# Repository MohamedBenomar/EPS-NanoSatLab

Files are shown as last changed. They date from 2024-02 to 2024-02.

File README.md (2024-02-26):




# Electrical Power System (EPS) for the NanoSatLab of the Universitat Politècnica de Catalunya (UPC)

Study and validate a design of a Electrical Power System for Nanosatellites using Supercapacitors technology as a source for systems that require high currents for a short time, together with Lithium-Ion batteries.

## Table of Contents

- [CADS](#cads)
- [Docs](#docs)
- [Firmware](#firmware)
- [Hardware](#hardware)
- [Validation](#validation)

## CADS

This folder section the 3D model of the designed PCB and the 3D model of an encapsulate for the system.

## Docs

This section includes the datasheets of the components used in the design, a real picture of the system indicating the differents blocks and the paper about the project.

## Firmware

This section includes the firmware for the ESP using an STM32 microcontroller.

## Hardware

This section includes the hardware files of the system using the open-source software KiCad.

## Validation

This section contains the validation report of the system.

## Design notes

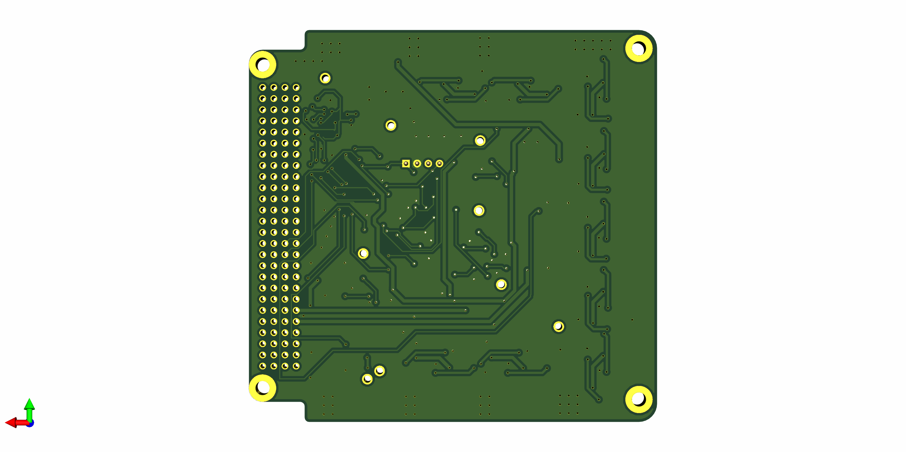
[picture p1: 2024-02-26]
Hardware/Docs/EPS_v3_NanoSatLab_PCB_Back.png

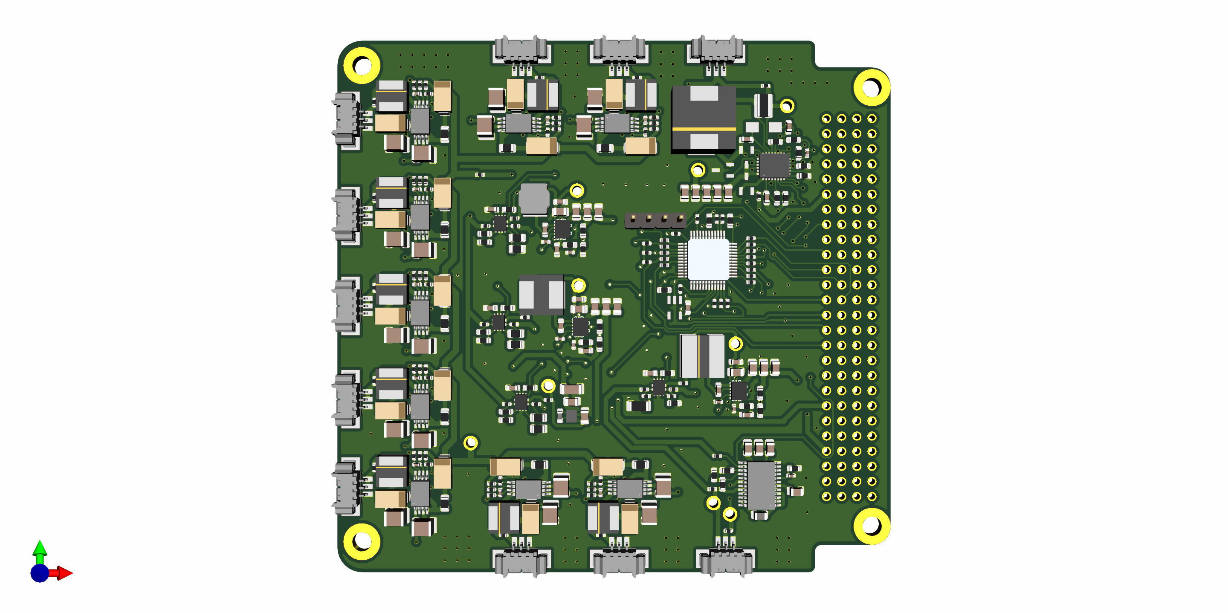
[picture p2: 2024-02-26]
Hardware/Docs/EPS_v3_NanoSatLab_PCB_Front.png

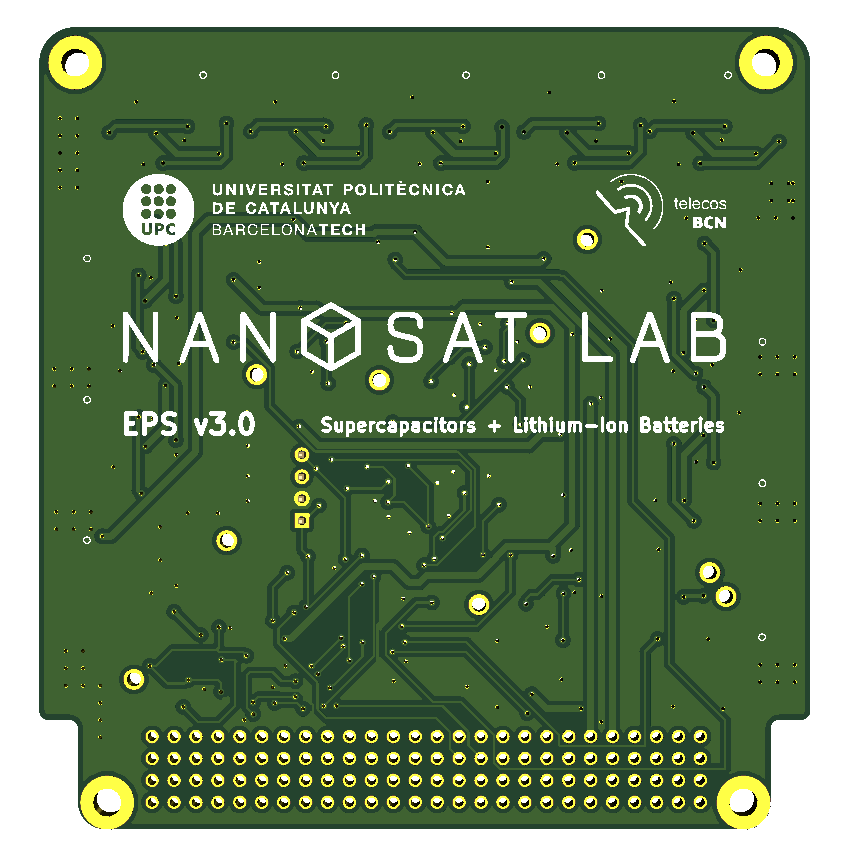
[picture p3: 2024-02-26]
CAD/EPS_v3_NanoSatLab_Bottom_3D.PNG

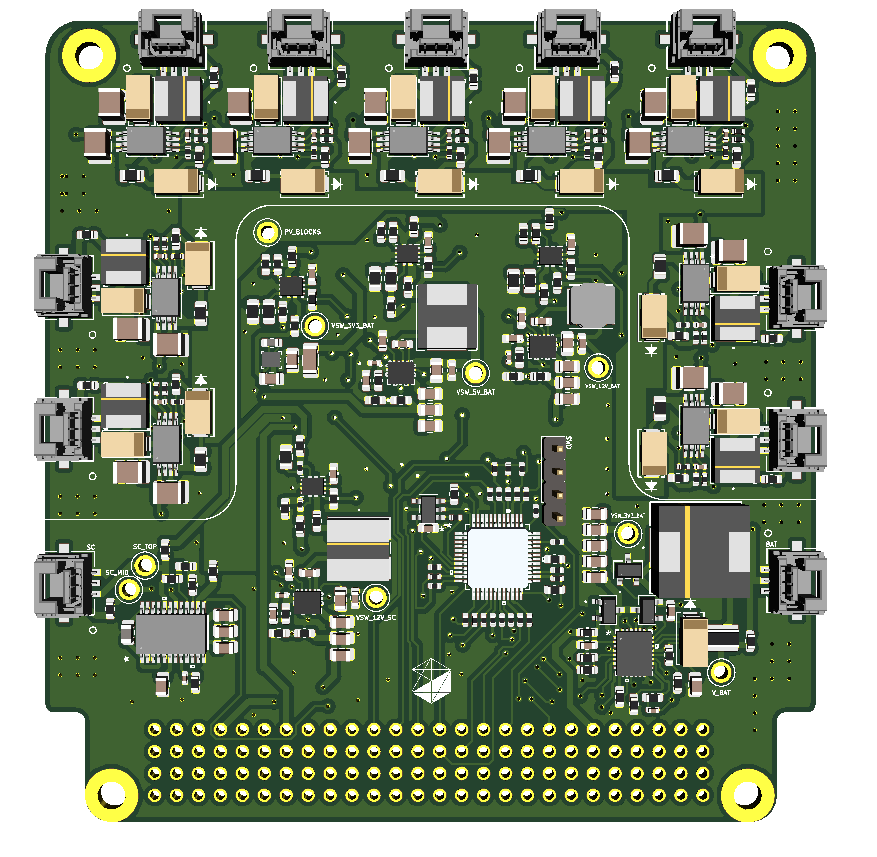
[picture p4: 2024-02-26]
CAD/EPS_v3_NanoSatLab_Top_3D.PNG

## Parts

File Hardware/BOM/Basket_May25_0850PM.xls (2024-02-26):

SHOPPING BASKET
This is not an invoice
25-May-21 20:50:02
 | Mouser No | Mfr. No | Manufacturer | Customer No | Description | RoHS | Lifecycle | Order Qty. | Price (EUR) | Ext.: (EUR)
1 | 538-502382-0370 | 502382-0370 | Molex |  | Headers & Wire Housings 3P CLIKMATE RECPT VERTICAL TIN | RoHS Compliant |  | 11 | 0,424 € | 4,66 €
2 | 511-STM32L412C8T6 | STM32L412C8T6 | STMicroelectronics |  | ARM Microcontrollers - MCU 16/32-BITS MICROS | RoHS Compliant |  | 1 | 3,68 € | 3,68 €
3 | 579-MCP1320T-29LE/OT | MCP1320T-29LE/OT | Microchip |  | Supervisory Circuits Active low P-P | RoHS Compliant |  | 1 | 0,559 € | 0,56 €
4 | 81-DFE18SAN1R0MG0L | DFE18SAN1R0MG0L | Murata |  | Fixed Inductors 0603 1.0uH 20% 1.7A RDC=0.128ohms | RoHS Compliant |  | 1 | 0,356 € | 0,36 €
5 | 595-TPS61288RQQR | TPS61288RQQR | Texas Instruments |  | Switching Voltage Regulators 18V, 15A synch boost converter 11-VQFN-HR -40 to 125 | RoHS Compliant | New Product | 3 | 3,35 € | 10,05 €
6 | 652-CR0603FX9313ELF | CR0603-FX-9313ELF | Bourns |  | Thick Film Resistors - SMD CHIP RESISTOR | RoHS Compliant |  | 2 | 0,085 € | 0,17 €
7 | 667-ERJ-PB3B4872V | ERJ-PB3B4872V | Panasonic |  | Thick Film Resistors - SMD 0603 Anti-Surge Res. 0.1%, 48.7Koh |  |  | 3 | 0,237 € | 0,71 €
8 | 81-LQH5BPN2R7NT0L0L | LQH5BPN2R7NT0L | Murata |  | Fixed Inductors 2.7uH +/-30% | RoHS Compliant |  | 1 | 0,415 € | 0,42 €
9 | 81-GCM155R72A392KA7J | GCM155R72A392KA37J | Murata |  | Multilayer Ceramic Capacitors MLCC - SMD/SMT 0402 3900pF 100volts X7R 10% | RoHS Compliant |  | 1 | 0,085 € | 0,09 €
10 | 667-ERJ-PB3B3402V | ERJ-PB3B3402V | Panasonic |  | Thick Film Resistors - SMD 0603 Anti-Surge Res. 0.1%, 34Kohm |  |  | 1 | 0,212 € | 0,21 €
11 | 542-PM628S-6R0-RC | PM628S-6R0-RC | Bourns |  | Fixed Inductors 6.0uH 30% | RoHS Compliant |  | 1 | 0,94 € | 0,94 €
12 | 81-GCM1555C1H620JA6D | GCM1555C1H620JA16D | Murata |  | Multilayer Ceramic Capacitors MLCC - SMD/SMT 0402 62pF 50volts C0G 5% | RoHS Compliant |  | 2 | 0,085 € | 0,17 €
13 | 667-ERJ-PB3D2052V | ERJ-PB3D2052V | Panasonic |  | Thick Film Resistors - SMD 0603 Anti-Surge Res. 0.5%, 20.5Koh |  |  | 1 | 0,152 € | 0,15 €
14 | 595-TPS2121RUXR | TPS2121RUXR | Texas Instruments |  | Power Switch ICs - Power Distribution 2.7-V&nbsp;to 22-V, 56-m , 4.5-A, power mux with seamless switchover 12-VQFN-HR -40 to 125 | RoHS Compliant |  | 4 | 1,86 € | 7,44 €
15 | 667-ERJ-PA3F3573V | ERJ-PA3F3573V | Panasonic |  | Thick Film Resistors - SMD 0603 357Kohm 1% Anti-Surge AEC-Q200 |  |  | 1 | 0,136 € | 0,14 €
16 | 704-FP3-3R3-R | FP3-3R3-R | Eaton |  | Fixed Inductors 3.3uH 5.5A Flat-Pac FP3 | RoHS Compliant |  | 1 | 3,71 € | 3,71 €
17 | 667-ERJ-PB3B1962V | ERJ-PB3B1962V | Panasonic |  | Thick Film Resistors - SMD 0603 Anti-Surge Res. 0.1%, 19.6Koh |  |  | 1 | 0,237 € | 0,24 €
18 | 534-5013 | 5013 | Keystone Electronics |  | Circuit Board Hardware - PCB ORANGE TEST POINT | RoHS Compliant |  | 9 | 0,352 € | 3,17 €
19 | 81-LQM21PN3R3MGRD | LQM21PN3R3MGRD | Murata |  | Fixed Inductors 0805 3.3uH 20% | RoHS Compliant |  | 1 | 0,305 € | 0,31 €
20 | 584-LTC3128IUFD#PBF | LTC3128IUFD#PBF | Analog Devices Inc. |  | Switching Voltage Regulators 3A Monolithic Buck-Boost Supercapacitor Charger and Balancer with Accurate Input Current Limit | RoHS Compliant |  | 1 | 8,80 € | 8,80 €
21 | 660-RN731JTTD1423B50 | RN731JTTD1423B50 | KOA Speer |  | Thin Film Resistors - SMD 142kOhm,0603,0.1%,50 ppm,63mW,50V | RoHS Compliant |  | 1 | 0,352 € | 0,35 €
22 | 667-ERJ-UP3F3571V | ERJ-UP3F3571V | Panasonic |  | Thick Film Resistors - SMD AEC-Q200 | RoHS Compliant By Exemption | New Product | 1 | 0,22 € | 0,22 €
23 | 594-MCT06030C2214FP5 | MCT06030C2214FP500 | Vishay |  | Thin Film Resistors - SMD .1W 2.21Mohms 1% 0603 50ppm Auto | RoHS Compliant |  | 1 | 0,195 € | 0,20 €
24 | 667-ERJ-UP3F3013V | ERJ-UP3F3013V | Panasonic |  | Thick Film Resistors - SMD AEC-Q200 | RoHS Compliant By Exemption | New Product | 1 | 0,22 € | 0,22 €
25 | 667-ERJ-6CWDR022V | ERJ-6CWDR022V | Panasonic |  | Current Sense Resistors - SMD 0805 0.5% 0.022ohm AEC-Q200 | RoHS Compliant By Exemption | New Product | 1 | 0,576 € | 0,58 €
26 | 494-LSM115JE3/TR13 | LSM115JE3/TR13 | Microchip |  | Schottky Diodes & Rectifiers Schottky | RoHS Compliant |  | 1 | 0,364 € | 0,36 €
27 | 963-NR10050T2R1N | NR10050T2R1N | Taiyo Yuden |  | Fixed Inductors 1005 2.1uH 10.4mOhms +/-30%Tol 8.3A HiCur | RoHS Compliant |  | 1 | 0,754 € | 0,75 €
28 | 667-ERJ-PA3F8662V | ERJ-PA3F8662V | Panasonic |  | Thick Film Resistors - SMD 0603 86.6Kohm 1% Anti-Surge AEC-Q200 |  |  | 1 | 0,11 € | 0,11 €
29 | 660-RN731JTD3361D100 | RN731JTTD3361D100 | KOA Speer |  | Thin Film Resistors - SMD 3.36kOhm,0603,0.5%,1 0ppm,63mW,50V | RoHS Compliant |  | 1 | 0,201 € | 0,20 €
30 | 621-DMN1019UVT-7 | DMN1019UVT-7 | Diodes Incorporated |  | MOSFET 12V Enh Mode FET | RoHS Compliant |  | 3 | 0,39 € | 1,17 €
31 | 511-SPV1040T | SPV1040T | STMicroelectronics |  | Battery Management Hi efficiency solar battery charger | RoHS Compliant |  | 9 | 2,84 € | 25,56 €
32 | 963-JMK325ABJ107MM-P | JMK325ABJ107MM-P | Taiyo Yuden |  | Multilayer Ceramic Capacitors MLCC - SMD/SMT 1210 6.3VDC 100uF 20% X5R | RoHS Compliant |  | 9 | 0,508 € | 4,57 €
33 | 963-NRS5020T470MMGJV | NRS5020T470MMGJV | Taiyo Yuden |  | Fixed Inductors 47uH 20% AEC-Q200 Hi Quality | RoHS Compliant | New Product | 9 | 0,601 € | 5,41 €
34 | 78-VS-30BQ015-M39AT | VS-30BQ015-M3/9AT | Vishay |  | Schottky Diodes & Rectifiers 3A 15V Single Die Schottky Rectifier | RoHS Compliant |  | 18 | 0,751 € | 13,52 €
35 | 71-RCWH080533L2FNEA | RCWH080533L2FNEA | Vishay |  | Thick Film Resistors - SMD 0.33W .0332ohms 1% 200ppm | RoHS Compliant |  | 9 | 0,567 € | 5,10 €
36 | 187-CL32A157MQVNNNE | CL32A157MQVNNNE | Samsung Electro-Mechanics |  | Multilayer Ceramic Capacitors MLCC - SMD/SMT 150uF +/-20% 6.3V X5R 3225 | RoHS Compliant | New At Mouser | 9 | 0,974 € | 8,77 €
37 | 584-LTC4013IUFD#PBF | LTC4013IUFD#PBF | Analog Devices Inc. |  | Battery Management 60V Synchronous Buck Multi-Chemistry Battery Charger | RoHS Compliant |  | 1 | 9,23 € | 9,23 €
38 | 595-TPS630242YFFT | TPS630242YFFT | Texas Instruments |  | Switching Voltage Regulators High Efficiency 1.5A Sing InductBuckBoost | RoHS Compliant |  | 1 | 2,33 € | 2,33 €
By submitting your order you agree to these terms and conditions. (https://www.mouser.es/saleterms) |  |  |  |  |  |  |  |  | Merchandise: | 124,63 €
Prices are reflected at the date and time shown. |  |  |  |  |  |  |  |  | Delivery Charge: | 0,00 €
 |  |  |  |  |  |  |  |  | Back-order Delivery: | 0,00 €

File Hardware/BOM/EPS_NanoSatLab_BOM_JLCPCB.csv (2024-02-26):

Comment | Designator | Footprint | LCSC Part #
100 nF Unpolarized capacitor | C201,C317,C313,C309,C306,C307,C302,C314,C301,C308,C305 | C_0603_1608Metric | CC0603KRX7R9BB104
47 nF Unpolarized capacitor | C316,C315 | C_0603_1608Metric | CL10B473KB8NNNC
2.2 uF Unpolarized capacitor | C318,C311,C310 | C_0603_1608Metric | CL10A225KO8NNNC
82 pF Unpolarized capacitor | C329 | C_0603_1608Metric | 0603CG820J500NT
22 uF Unpolarized capacitor | C330,C331,C332,C321,C323,C326 | C_0805_2012Metric | CL21A226MAQNNNE
10 uF Unpolarized capacitor | C333,C325,C312,C322,C304,C327,C324,C303,C403,C405,C404,C401,C509,C502,C503,C505,C506,C508 | C_0805_2012Metric | CL21A106KAYNNNE
47 uF Unpolarized capacitor | C334 | C_1206_3216Metric | CL31A476MPHNNNE
470 pF Unpolarized capacitor | C402 | C_0402_1005Metric | 0402B471K500NT
0.1 uF Unpolarized capacitor | C501 | C_0603_1608Metric | CC0603KRX7R9BB104
0.01 uF Unpolarized capacitor | C504 | C_0402_1005Metric | CL05B103KB5NNNC
0.22 uF Unpolarized capacitor | C507 | C_0603_1608Metric | CL10B224KA8NNNC
1 uF Unpolarized capacitor | C604,C605,C606,C613,C614,C615,C622,C623,C624 | C_0402_1005Metric | CL05A105KA5NQNC
100 kΩ Resistor, US symbol | R201,R202,R203,R204 | R_0402_1005Metric | 0402WGF1003TCE
33 Ω Resistor, US symbol | R222,R223 | R_0402_1005Metric | 0402WGF330JTCE
0 Ω Resistor, US symbol | R226,R215,R217,R218,R216,R210,R221,R214,R209,R207,R208,R212,R213,R224,R225,R219,R206,R220 | R_0402_1005Metric | 0402WGF0000TCE
10 kΩ Resistor, US symbol | R227,R205,R211,R319,R320,R311,R312,R328,R329 | R_0603_1608Metric | 0603WAF1002T5E
12 kΩ Resistor, US symbol | R305,R307 | R_0402_1005Metric | 0402WGF1202TCE
40.2 kΩ Resistor, US symbol | R306 | R_0603_1608Metric | 0603WFA4022T5E
7.5 kΩ Resistor, US symbol | R308 | R_0805_2012Metric | 0805W8F7501T5E
5.1 kΩ Resistor, US symbol | R317,R309,R326 | R_0805_2012Metric | 0805W8F5101T5E
15 kΩ Resistor, US symbol | R318,R310,R327 | R_0805_2012Metric | 0805W8F1502T5E
18 kΩ Resistor, US symbol | R325,R314,R331,R313 | R_0603_1608Metric | 0603WAF1802T5E
0 Ω Resistor, US symbol | R330,R322,R338,R321,R303,R315,R301,R323,R324,R304,R316,R302,R401,R407,R404,R501,R510,R601,R602,R603,R619,R620,R621,R638,R639,R637 | R_0603_1608Metric | 0603WAF0000T5E
1.5 MΩ Resistor, US symbol | R502 | R_0603_1608Metric | 0603WAF1504T5E
1 MΩ Resistor, US symbol | R503,R507,R508 | R_0603_1608Metric | 0603WAF1004T5E
75 kΩ Resistor, US symbol | R505 | R_0603_1608Metric | 0603WAF7502T5E
1 kΩ Resistor, US symbol | R604,R605,R606,R607,R608,R609,R622,R623,R624,R625,R626,R627,R640,R641,R642,R643,R644,R645 | R_0402_1005Metric | 0402WGF1001TCE
2 MΩ Resistor, US symbol | R613,R615,R617,R631,R633,R635,R649,R651,R653 | R_0603_1608Metric | 0603WAF2004T5E
680 kΩ Resistor, US symbol | R614,R616,R618,R632,R634,R636,R650,R652,R654 | R_0402_1005Metric | 0402WGF6803TCE

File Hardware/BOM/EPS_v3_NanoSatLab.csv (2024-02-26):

Reference | Value | Footprint | Datasheet | Description | JLCPCB | LCSC BOM | LCSC Part | Order Code | Package | Ref | Resistance
J112 | 502382-0370 | EPS_v3_Library:MOLEX_502382-0370 | ~ | SC_CONN | - - - | 0 | - - - | 502494-0370 | MOLEX | - - -
J111 | 502382-0370 | EPS_v3_Library:MOLEX_502382-0370 | ~ | BAT_CONN | - - - | 0 | - - - | 502382-0370 | MOLEX | - - -
J110 | PC104 | EPS_v3_Library:PC104 |  | PinHeaders | - - - | 0 | - - - | – – – | – – – | - - -
J101 | 502382-0370 | EPS_v3_Library:MOLEX_502382-0370 | ~ | X_1 | - - - | 0 | - - - | 502382-0370 | MOLEX | - - -
J102 | 502382-0370 | EPS_v3_Library:MOLEX_502382-0370 | ~ | Y_1 | - - - | 0 | - - - | 502382-0370 | MOLEX | - - -
J103 | 502382-0370 | EPS_v3_Library:MOLEX_502382-0370 | ~ | Z_1 | - - - | 0 | - - - | 502382-0370 | MOLEX | - - -
J104 | 502382-0370 | EPS_v3_Library:MOLEX_502382-0370 | ~ | X_2 | - - - | 0 | - - - | 502382-0370 | MOLEX | - - -
J105 | 502382-0370 | EPS_v3_Library:MOLEX_502382-0370 | ~ | Y_2 | - - - | 0 | - - - | 502382-0370 | MOLEX | - - -
J106 | 502382-0370 | EPS_v3_Library:MOLEX_502382-0370 | ~ | Z_2 | - - - | 0 | - - - | 502382-0370 | MOLEX | - - -
J107 | 502382-0370 | EPS_v3_Library:MOLEX_502382-0370 | ~ | X_3 | - - - | 0 | - - - | 502382-0370 | MOLEX | - - -
J108 | 502382-0370 | EPS_v3_Library:MOLEX_502382-0370 | ~ | Y_3 | - - - | 0 | - - - | 502382-0370 | MOLEX | - - -
J109 | 502382-0370 | EPS_v3_Library:MOLEX_502382-0370 | ~ | Z_3 | - - - | 0 | - - - | 502382-0370 | MOLEX | - - -
C201 | 100 nF | Capacitor_SMD:C_0603_1608Metric | ~ |  | CC0603KRX7R9BB104 | 1 | CC0603KRX7R9BB104 | CC0603KRX7R9BB104 | 0603 | CC0603KRX7R9BB104
U201 | STM32L412C8T6 | EPS_v3_Library:STM32L412C8T6 |  |  | - - - | 0 | - - - | STM32L412C8T6 | LQFP-48 | - - -
R227 | 10 kΩ | Resistor_SMD:R_0603_1608Metric | ~ |  | 0603WAF1002T5E | 1 | 0603WAF1002T5E | CRCW060310K0JNEBC | 0603 | CRCW060310K0JNEBC
J201 | SWD | Connector_PinHeader_2.54mm:PinHeader_1x04_P2.54mm_Vertical | ~ | PinHeaders | - - - | 0 | - - - | – – – | – – – | - - -
R226 | 0 Ω | Resistor_SMD:R_0402_1005Metric | ~ |  | 0402WGF0000TCE | 1 | 0402WGF0000TCE | RCS04020000Z0ED | 0402 | RCS04020000Z0ED
R215 | 0 Ω | Resistor_SMD:R_0402_1005Metric | ~ |  | 0402WGF0000TCE | 1 | 0402WGF0000TCE | RCS04020000Z0ED | 0402 | RCS04020000Z0ED
R217 | 0 Ω | Resistor_SMD:R_0402_1005Metric | ~ |  | 0402WGF0000TCE | 1 | 0402WGF0000TCE | RCS04020000Z0ED | 0402 | RCS04020000Z0ED
R218 | 0 Ω | Resistor_SMD:R_0402_1005Metric | ~ |  | 0402WGF0000TCE | 1 | 0402WGF0000TCE | RCS04020000Z0ED | 0402 | RCS04020000Z0ED
R216 | 0 Ω | Resistor_SMD:R_0402_1005Metric | ~ |  | 0402WGF0000TCE | 1 | 0402WGF0000TCE | RCS04020000Z0ED | 0402 | RCS04020000Z0ED
R210 | 0 Ω | Resistor_SMD:R_0402_1005Metric | ~ |  | 0402WGF0000TCE | 1 | 0402WGF0000TCE | RCS04020000Z0ED | 0402 | RCS04020000Z0ED
R221 | 0 Ω | Resistor_SMD:R_0402_1005Metric | ~ |  | 0402WGF0000TCE | 1 | 0402WGF0000TCE | RCS04020000Z0ED | 0402 | RCS04020000Z0ED
R214 | 0 Ω | Resistor_SMD:R_0402_1005Metric | ~ |  | 0402WGF0000TCE | 1 | 0402WGF0000TCE | RCS04020000Z0ED | 0402 | RCS04020000Z0ED
R209 | 0 Ω | Resistor_SMD:R_0402_1005Metric | ~ |  | 0402WGF0000TCE | 1 | 0402WGF0000TCE | RCS04020000Z0ED | 0402 | RCS04020000Z0ED
R207 | 0 Ω | Resistor_SMD:R_0402_1005Metric | ~ |  | 0402WGF0000TCE | 1 | 0402WGF0000TCE | RCS04020000Z0ED | 0402 | RCS04020000Z0ED
R208 | 0 Ω | Resistor_SMD:R_0402_1005Metric | ~ |  | 0402WGF0000TCE | 1 | 0402WGF0000TCE | RCS04020000Z0ED | 0402 | RCS04020000Z0ED
R212 | 0 Ω | Resistor_SMD:R_0402_1005Metric | ~ |  | 0402WGF0000TCE | 1 | 0402WGF0000TCE | RCS04020000Z0ED | 0402 | RCS04020000Z0ED
R213 | 0 Ω | Resistor_SMD:R_0402_1005Metric | ~ |  | 0402WGF0000TCE | 1 | 0402WGF0000TCE | RCS04020000Z0ED | 0402 | RCS04020000Z0ED
R222 | 33 Ω | Resistor_SMD:R_0402_1005Metric | ~ |  | 0402WGF330JTCE | 1 | 0402WGF330JTCE | CRCW040233R0FKEDC | 0402 | CRCW040233R0FKEDC
R223 | 33 Ω | Resistor_SMD:R_0402_1005Metric | ~ |  | 0402WGF330JTCE | 1 | 0402WGF330JTCE | CRCW040233R0FKEDC | 0402 | CRCW040233R0FKEDC
R224 | 0 Ω | Resistor_SMD:R_0402_1005Metric | ~ |  | 0402WGF0000TCE | 1 | 0402WGF0000TCE | RCS04020000Z0ED | 0402 | RCS04020000Z0ED
R225 | 0 Ω | Resistor_SMD:R_0402_1005Metric | ~ |  | 0402WGF0000TCE | 1 | 0402WGF0000TCE | RCS04020000Z0ED | 0402 | RCS04020000Z0ED
R205 | 10 kΩ | Resistor_SMD:R_0603_1608Metric | ~ |  | 0603WAF1002T5E | 1 | 0603WAF1002T5E | CRCW060310K0JNEBC | 0603 | CRCW060310K0JNEBC
R211 | 10 kΩ | Resistor_SMD:R_0603_1608Metric | ~ |  | 0603WAF1002T5E | 1 | 0603WAF1002T5E | CRCW060310K0JNEBC | 0603 | CRCW060310K0JNEBC
R219 | 0 Ω | Resistor_SMD:R_0402_1005Metric | ~ |  | 0402WGF0000TCE | 1 | 0402WGF0000TCE | RCS04020000Z0ED | 0402 | RCS04020000Z0ED
R206 | 0 Ω | Resistor_SMD:R_0402_1005Metric | ~ |  | 0402WGF0000TCE | 1 | 0402WGF0000TCE | RCS04020000Z0ED | 0402 | RCS04020000Z0ED
R220 | 0 Ω | Resistor_SMD:R_0402_1005Metric | ~ |  | 0402WGF0000TCE | 1 | 0402WGF0000TCE | RCS04020000Z0ED | 0402 | RCS04020000Z0ED
R201 | 100 kΩ | Resistor_SMD:R_0402_1005Metric | ~ |  | 0402WGF1003TCE | 1 | 0402WGF1003TCE | RCS0402100KFKED | 0402 | RCS0402100KFKED
R202 | 100 kΩ | Resistor_SMD:R_0402_1005Metric | ~ |  | 0402WGF1003TCE | 1 | 0402WGF1003TCE | RCS0402100KFKED | 0402 | RCS0402100KFKED
R203 | 100 kΩ | Resistor_SMD:R_0402_1005Metric | ~ |  | 0402WGF1003TCE | 1 | 0402WGF1003TCE | RCS0402100KFKED | 0402 | RCS0402100KFKED
R204 | 100 kΩ | Resistor_SMD:R_0402_1005Metric | ~ |  | 0402WGF1003TCE | 1 | 0402WGF1003TCE | RCS0402100KFKED | 0402 | RCS0402100KFKED
U202 | MCP1320T-29LE_OT | EPS_v3_Library:MCP1320T-29LE&slash_OT |  |  | - - - | 0 | - - - | MCP1320T-29LE/OT | SOT-23-5 | - - -
C333 | 10 uF | Capacitor_SMD:C_0805_2012Metric | ~ |  | CL21A106KAYNNNE | 1 | CL21A106KAYNNNE | JMF212AB7106KGHT | 0805 | JMF212AB7106KGHT | 1 mΩ
C325 | 10 uF | Capacitor_SMD:C_0805_2012Metric | ~ |  | CL21A106KAYNNNE | 1 | CL21A106KAYNNNE | JMF212AB7106KGHT | 0805 | JMF212AB7106KGHT | 3 mΩ
C334 | 47 uF | Capacitor_SMD:C_1206_3216Metric | ~ |  | CL31A476MPHNNNE | 1 | CL31A476MPHNNNE | CL31A476MPHNNNE | 1206 | CL31A476MPHNNNE | 1 mΩ
L304 | 1 uH | Inductor_SMD:L_0603_1608Metric | ~ |  | - - - | 0 | - - - | DFE18SAN1R0MG0L | 0603 | - - -
U307 | TPS61288RQQR | EPS_v3_Library:TPS61288RQQR |  |  | - - - | 0 | - - - | TPS61288RQQR | VQFN-HR-11 | - - -
C330 | 22 uF | Capacitor_SMD:C_0805_2012Metric | ~ |  | CL21A226MAQNNNE | 1 | CL21A226MAQNNNE | CL21A226MOQNNNE | 0805 | CL21A226MOQNNNE
R340 | 931 kΩ | Resistor_SMD:R_0603_1608Metric | ~ |  | 0603WAF9313T5E | 0 | - - - | CR0603-FX-9313ELF | 0603 | CR0603-FX-9313ELF
R341 | 48.7 kΩ | Resistor_SMD:R_0603_1608Metric | ~ |  | 0603WAF4872T5E | 0 | - - - | ERJ-PB3B4872V | 0603 | ERJ-PB3B4872V
L303 | 2.7 uH | EPS_v3_Library:IND_LQH5BPN2R7NT0L | ~ |  | - - - | 0 | - - - | LQH5BPN2R7NT0L | 2020 | - - -
C317 | 100 nF | Capacitor_SMD:C_0603_1608Metric | ~ |  | CC0603KRX7R9BB104 | 1 | CC0603KRX7R9BB104 | CC0603KRX7R9BB104 | 0603 | CC0603KRX7R9BB104
C318 | 2.2 uF | Capacitor_SMD:C_0603_1608Metric | ~ |  | 0805F225M500NT | 1 | CL10A225KO8NNNC | LMK105ABJ225KVHF | 0603 | LMK105ABJ225KVHF
C313 | 100 nF | Capacitor_SMD:C_0603_1608Metric | ~ |  | CC0603KRX7R9BB104 | 1 | CC0603KRX7R9BB104 | CC0603KRX7R9BB104 | 0603 | CC0603KRX7R9BB104
C312 | 10 uF | Capacitor_SMD:C_0805_2012Metric | ~ |  | CL21A106KAYNNNE | 1 | CL21A106KAYNNNE | JMF212AB7106KGHT | 0805 | JMF212AB7106KGHT
C328 | 39 nF | Capacitor_SMD:C_0402_1005Metric | ~ |  | CL05B393K05NNNC | 0 | - - - | GCM155R72A392KA37J | 0402 | GCM155R72A392KA37J
C329 | 82 pF | Capacitor_SMD:C_0603_1608Metric | ~ |  | 0603CG820J500NT | 1 | 0603CG820J500NT | 06035A820JAT2A | 0603 | 06035A820JAT2A
R339 | 34 kΩ | Resistor_SMD:R_0603_1608Metric | ~ |  | 0603WAF3402T5E | 0 | - - - | ERJ-PB3B3402V | 0603 | ERJ-PB3B3402V
C322 | 10 uF | Capacitor_SMD:C_0805_2012Metric | ~ |  | CL21A106KAYNNNE | 1 | CL21A106KAYNNNE | JMF212AB7106KGHT | 0805 | JMF212AB7106KGHT
R336 | 931 kΩ | Resistor_SMD:R_0603_1608Metric | ~ |  | 0603WAF9313T5E | 0 | - - - | CR0603-FX-9313ELF | 0603 | CR0603-FX-9313ELF
R337 | 48.7 kΩ | Resistor_SMD:R_0603_1608Metric | ~ |  | 0603WAF4872T5E | 0 | - - - | ERJ-PB3B4872V | 0603 | ERJ-PB3B4872V
L302 | 6 uH | EPS_v3_Library:PM628S-100 | ~ |  | - - - | 0 | - - - | PM628S-6R0-RC | 6.8x6.8x2.8mm | - - -
C309 | 100 nF | Capacitor_SMD:C_0603_1608Metric | ~ |  | CC0603KRX7R9BB104 | 1 | CC0603KRX7R9BB104 | CC0603KRX7R9BB104 | 0603 | CC0603KRX7R9BB104
C311 | 2.2 uF | Capacitor_SMD:C_0603_1608Metric | ~ |  | 0805F225M500NT | 1 | CL10A225KO8NNNC | LMK105ABJ225KVHF | 0603 | LMK105ABJ225KVHF
C306 | 100 nF | Capacitor_SMD:C_0603_1608Metric | ~ |  | CC0603KRX7R9BB104 | 1 | CC0603KRX7R9BB104 | CC0603KRX7R9BB104 | 0603 | CC0603KRX7R9BB104
C304 | 10 uF | Capacitor_SMD:C_0805_2012Metric | ~ |  | CL21A106KAYNNNE | 1 | CL21A106KAYNNNE | JMF212AB7106KGHT | 0805 | JMF212AB7106KGHT
C316 | 47 nF | Capacitor_SMD:C_0603_1608Metric | ~ |  | CL10B473KB8NNNC | 1 | CL10B473KB8NNNC | CL10B473KB8NNNC | 0603 | CL10B473KB8NNNC
C320 | 62 pF | Capacitor_SMD:C_0402_1005Metric | ~ |  | 0402CG620J500NT | 0 | - - - | GCM1555C1H620JA16D | 0402 | GCM1555C1H620JA16D
R333 | 20.5 kΩ | Resistor_SMD:R_0603_1608Metric | ~ |  | 0603WAF2052T5E | 0 | - - - | ERJ-PB3D2052V | 0603 | ERJ-PB3D2052V
C327 | 10 uF | Capacitor_SMD:C_0805_2012Metric | ~ |  | CL21A106KAYNNNE | 1 | CL21A106KAYNNNE | JMF212AB7106KGHT | 0805 | JMF212AB7106KGHT
C324 | 10 uF | Capacitor_SMD:C_0805_2012Metric | ~ |  | CL21A106KAYNNNE | 1 | CL21A106KAYNNNE | JMF212AB7106KGHT | 0805 | JMF212AB7106KGHT
R317 | 5.1 kΩ | Resistor_SMD:R_0805_2012Metric | ~ |  | - - - | 1 | 0805W8F5101T5E | CRCW08055K10FKEA | 0805 | - - -
R318 | 15 kΩ | Resistor_SMD:R_0805_2012Metric | ~ |  | 0805W8F1502T5E | 1 | 0805W8F1502T5E | RCG080515K0FKEA | 0805 | RCG080515K0FKEA
R319 | 10 kΩ | Resistor_SMD:R_0603_1608Metric | ~ |  | 0603WAF1002T5E | 1 | 0603WAF1002T5E | CRCW060310K0JNEBC | 0603 | CRCW060310K0JNEBC
R320 | 10 kΩ | Resistor_SMD:R_0603_1608Metric | ~ |  | 0603WAF1002T5E | 1 | 0603WAF1002T5E | CRCW060310K0JNEBC | 0603 | CRCW060310K0JNEBC
U303 | TPS2121RUXR | EPS_v3_Library:TPS2121RUXR |  |  | - - - | 0 | - - - | TPS2121RUXR | VQFN-12 | - - -
R309 | 5.1 kΩ | Resistor_SMD:R_0805_2012Metric | ~ |  | - - - | 1 | 0805W8F5101T5E | CRCW08055K10FKEA | 0805 | - - -
R310 | 15 kΩ | Resistor_SMD:R_0805_2012Metric | ~ |  | 0805W8F1502T5E | 1 | 0805W8F1502T5E | RCG080515K0FKEA | 0805 | RCG080515K0FKEA
R311 | 10 kΩ | Resistor_SMD:R_0603_1608Metric | ~ |  | 0603WAF1002T5E | 1 | 0603WAF1002T5E | CRCW060310K0JNEBC | 0603 | CRCW060310K0JNEBC
R312 | 10 kΩ | Resistor_SMD:R_0603_1608Metric | ~ |  | 0603WAF1002T5E | 1 | 0603WAF1002T5E | CRCW060310K0JNEBC | 0603 | CRCW060310K0JNEBC
R326 | 5.1 kΩ | Resistor_SMD:R_0805_2012Metric | ~ |  | - - - | 1 | 0805W8F5101T5E | CRCW08055K10FKEA | 0805 | - - -
R327 | 15 kΩ | Resistor_SMD:R_0805_2012Metric | ~ |  | 0805W8F1502T5E | 1 | 0805W8F1502T5E | RCG080515K0FKEA | 0805 | RCG080515K0FKEA
R328 | 10 kΩ | Resistor_SMD:R_0603_1608Metric | ~ |  | 0603WAF1002T5E | 1 | 0603WAF1002T5E | CRCW060310K0JNEBC | 0603 | CRCW060310K0JNEBC
R329 | 10 kΩ | Resistor_SMD:R_0603_1608Metric | ~ |  | 0603WAF1002T5E | 1 | 0603WAF1002T5E | CRCW060310K0JNEBC | 0603 | CRCW060310K0JNEBC
R305 | 12 kΩ | Resistor_SMD:R_0402_1005Metric | ~ |  | 0402WGF1202TCE | 1 | 0402WGF1202TCE | ERJ-2RHD1202X | 0402 | ERJ-2RHD1202X
R306 | 40.2 kΩ | Resistor_SMD:R_0603_1608Metric | ~ |  | - - - | 1 | 0603WFA4022T5E | ERJ-UP3F4022V | 0603 | - - -
R307 | 12 kΩ | Resistor_SMD:R_0402_1005Metric | ~ |  | 0402WGF1202TCE | 1 | 0402WGF1202TCE | ERJ-2RHD1202X | 0402 | ERJ-2RHD1202X
R308 | 7.5 kΩ | Resistor_SMD:R_0805_2012Metric | ~ |  | - - - | 1 | 0805W8F7501T5E | CRCW12067K00JNTA | 0805 | - - -
R325 | 18 kΩ | Resistor_SMD:R_0603_1608Metric | ~ |  | 0603WAF1802T5E | 1 | 0603WAF1802T5E | AC0603FR-1318KL | 0603 | AC0603FR-1318KL
R314 | 18 kΩ | Resistor_SMD:R_0603_1608Metric | ~ |  | 0603WAF1802T5E | 1 | 0603WAF1802T5E | AC0603FR-1318KL | 0603 | AC0603FR-1318KL
R331 | 18 kΩ | Resistor_SMD:R_0603_1608Metric | ~ |  | 0603WAF1802T5E | 1 | 0603WAF1802T5E | AC0603FR-1318KL | 0603 | AC0603FR-1318KL
R313 | 18 kΩ | Resistor_SMD:R_0603_1608Metric | ~ |  | 0603WAF1802T5E | 1 | 0603WAF1802T5E | AC0603FR-1318KL | 0603 | AC0603FR-1318KL
C307 | 100 nF | Capacitor_SMD:C_0603_1608Metric | ~ |  | CC0603KRX7R9BB104 | 1 | CC0603KRX7R9BB104 | CC0603KRX7R9BB104 | 0603 | CC0603KRX7R9BB104
C302 | 100 nF | Capacitor_SMD:C_0603_1608Metric | ~ |  | CC0603KRX7R9BB104 | 1 | CC0603KRX7R9BB104 | CC0603KRX7R9BB104 | 0603 | CC0603KRX7R9BB104
C314 | 100 nF | Capacitor_SMD:C_0603_1608Metric | ~ |  | CC0603KRX7R9BB104 | 1 | CC0603KRX7R9BB104 | CC0603KRX7R9BB104 | 0603 | CC0603KRX7R9BB104
C301 | 100 nF | Capacitor_SMD:C_0603_1608Metric | ~ |  | CC0603KRX7R9BB104 | 1 | CC0603KRX7R9BB104 | CC0603KRX7R9BB104 | 0603 | CC0603KRX7R9BB104
C331 | 22 uF | Capacitor_SMD:C_0805_2012Metric | ~ |  | CL21A226MAQNNNE | 1 | CL21A226MAQNNNE | CL21A226MOQNNNE | 0805 | CL21A226MOQNNNE
C332 | 22 uF | Capacitor_SMD:C_0805_2012Metric | ~ |  | CL21A226MAQNNNE | 1 | CL21A226MAQNNNE | CL21A226MOQNNNE | 0805 | CL21A226MOQNNNE
C321 | 22 uF | Capacitor_SMD:C_0805_2012Metric | ~ |  | CL21A226MAQNNNE | 1 | CL21A226MAQNNNE | CL21A226MOQNNNE | 0805 | CL21A226MOQNNNE
R334 | 357 kΩ | Resistor_SMD:R_0603_1608Metric | ~ |  | 0603WAF3573T5E | 0 | - - - | ERJ-PA3F3573V | 0603 | ERJ-PA3F3573V
R335 | 48.7 kΩ | Resistor_SMD:R_0603_1608Metric | ~ |  | 0603WAF4872T5E | 0 | - - - | ERJ-PB3B4872V | 0603 | ERJ-PB3B4872V
L301 | 3.2 uH | EPS_v3_Library:IND_FP3-3R3-R | ~ |  | - - - | 0 | - - - | FP3-3R3-R | 5.2x5.2x1.45mm | - - -
C308 | 100 nF | Capacitor_SMD:C_0603_1608Metric | ~ |  | CC0603KRX7R9BB104 | 1 | CC0603KRX7R9BB104 | CC0603KRX7R9BB104 | 0603 | CC0603KRX7R9BB104
C310 | 2.2 uF | Capacitor_SMD:C_0603_1608Metric | ~ |  | 0805F225M500NT | 1 | CL10A225KO8NNNC | LMK105ABJ225KVHF | 0603 | LMK105ABJ225KVHF
C305 | 100 nF | Capacitor_SMD:C_0603_1608Metric | ~ |  | CC0603KRX7R9BB104 | 1 | CC0603KRX7R9BB104 | CC0603KRX7R9BB104 | 0603 | CC0603KRX7R9BB104
C303 | 10 uF | Capacitor_SMD:C_0805_2012Metric | ~ |  | CL21A106KAYNNNE | 1 | CL21A106KAYNNNE | JMF212AB7106KGHT | 0805 | JMF212AB7106KGHT
C315 | 47 nF | Capacitor_SMD:C_0603_1608Metric | ~ |  | CL10B473KB8NNNC | 1 | CL10B473KB8NNNC | CL10B473KB8NNNC | 0603 | CL10B473KB8NNNC
C319 | 62 pF | Capacitor_SMD:C_0402_1005Metric | ~ |  | 0402CG620J500NT | 0 | - - - | GCM1555C1H620JA16D | 0402 | GCM1555C1H620JA16D
R332 | 19.6 kΩ | Resistor_SMD:R_0603_1608Metric | ~ |  | CR0603FA1962G | 0 | - - - | ERJ-PB3B1962V | 0603 | ERJ-PB3B1962V
C323 | 22 uF | Capacitor_SMD:C_0805_2012Metric | ~ |  | CL21A226MAQNNNE | 1 | CL21A226MAQNNNE | CL21A226MOQNNNE | 0805 | CL21A226MOQNNNE
C326 | 22 uF | Capacitor_SMD:C_0805_2012Metric | ~ |  | CL21A226MAQNNNE | 1 | CL21A226MAQNNNE | CL21A226MOQNNNE | 0805 | CL21A226MOQNNNE
U308 | TPS630242YFFR | EPS_v3_Library:TPS630242YFFR |  |  | - - - | 0 | - - - | TPS630242YFFR | DSBGA-20 | - - -
U302 | TPS2121RUXR | EPS_v3_Library:TPS2121RUXR |  |  | - - - | 0 | - - - | TPS2121RUXR | VQFN-12 | - - -
U306 | TPS2121RUXR | EPS_v3_Library:TPS2121RUXR |  |  | - - - | 0 | - - - | TPS2121RUXR | VQFN-12 | - - -
U301 | TPS2121RUXR | EPS_v3_Library:TPS2121RUXR |  |  | - - - | 0 | - - - | TPS2121RUXR | VQFN-12 | - - -
U305 | TPS61288RQQR | EPS_v3_Library:TPS61288RQQR |  |  | - - - | 0 | - - - | TPS61288RQQR | VQFN-HR-11 | - - -
U304 | TPS61288RQQR | EPS_v3_Library:TPS61288RQQR |  |  | - - - | 0 | - - - | TPS61288RQQR | VQFN-HR-11 | - - -
R330 | 0 Ω | Resistor_SMD:R_0603_1608Metric | ~ |  | 0402WGF0000TCE | 1 | 0603WAF0000T5E | RC0603JR-100RL | 0603 | RCS04020000Z0ED
R322 | 0 Ω | Resistor_SMD:R_0603_1608Metric | ~ |  | 0402WGF0000TCE | 1 | 0603WAF0000T5E | RC0603JR-100RL | 0603 | RCS04020000Z0ED
R338 | 0 Ω | Resistor_SMD:R_0603_1608Metric | ~ |  | 0402WGF0000TCE | 1 | 0603WAF0000T5E | RC0603JR-100RL | 0603 | RCS04020000Z0ED
R321 | 0 Ω | Resistor_SMD:R_0603_1608Metric | ~ |  | 0402WGF0000TCE | 1 | 0603WAF0000T5E | RC0603JR-100RL | 0603 | RCS04020000Z0ED
TP303 | TestPoint | EPS_v3_Library:TESTPOINT_5013 | ~ |  | - - - | 0 | - - - | 5013 | TP | - - -
TP301 | TestPoint | EPS_v3_Library:TESTPOINT_5013 | ~ |  | - - - | 0 | - - - | 5013 | TP | - - -
TP304 | TestPoint | EPS_v3_Library:TESTPOINT_5013 | ~ |  | - - - | 0 | - - - | 5013 | TP | - - -
TP302 | TestPoint | EPS_v3_Library:TESTPOINT_5013 | ~ |  | - - - | 0 | - - - | 5013 | TP | - - -
R303 | 0 Ω | Resistor_SMD:R_0603_1608Metric | ~ |  | 0402WGF0000TCE | 1 | 0603WAF0000T5E | RC0603JR-100RL | 0603 | RCS04020000Z0ED
R315 | 0 Ω | Resistor_SMD:R_0603_1608Metric | ~ |  | 0402WGF0000TCE | 1 | 0603WAF0000T5E | RC0603JR-100RL | 0603 | RCS04020000Z0ED
R301 | 0 Ω | Resistor_SMD:R_0603_1608Metric | ~ |  | 0402WGF0000TCE | 1 | 0603WAF0000T5E | RC0603JR-100RL | 0603 | RCS04020000Z0ED
R323 | 0 Ω | Resistor_SMD:R_0603_1608Metric | ~ |  | 0402WGF0000TCE | 1 | 0603WAF0000T5E | RC0603JR-100RL | 0603 | RCS04020000Z0ED
R324 | 0 Ω | Resistor_SMD:R_0603_1608Metric | ~ |  | 0402WGF0000TCE | 1 | 0603WAF0000T5E | RC0603JR-100RL | 0603 | RCS04020000Z0ED
R304 | 0 Ω | Resistor_SMD:R_0603_1608Metric | ~ |  | 0402WGF0000TCE | 1 | 0603WAF0000T5E | RC0603JR-100RL | 0603 | RCS04020000Z0ED
R316 | 0 Ω | Resistor_SMD:R_0603_1608Metric | ~ |  | 0402WGF0000TCE | 1 | 0603WAF0000T5E | RC0603JR-100RL | 0603 | RCS04020000Z0ED
R302 | 0 Ω | Resistor_SMD:R_0603_1608Metric | ~ |  | 0402WGF0000TCE | 1 | 0603WAF0000T5E | RC0603JR-100RL | 0603 | RCS04020000Z0ED
C403 | 10 uF | Capacitor_SMD:C_0805_2012Metric | ~ |  | CL21A106KAYNNNE | 1 | CL21A106KAYNNNE | JMF212AB7106KGHT | 0805 | JMF212AB7106KGHT
L401 | 3.3 uH | Inductor_SMD:L_0805_2012Metric | ~ |  | - - - | 0 | - - - | LQM21PN3R3MGRD | 0805 | - - -
U401 | LTC3128 | EPS_v3_Library:LTC3128EFE-PBF |  |  | - - - | 0 | - - - | LTC3128IUFD#PBF | QFN-20 | - - -
R403 | 142 kΩ | Resistor_SMD:R_0603_1608Metric | ~ |  | - - - | 0 | - - - | RN731JTTD1423B50 | 0603 | - - -
R402 | 3.57 kΩ | Resistor_SMD:R_0603_1608Metric | ~ |  | 0603WAF3571T5E | 0 | - - - | ERJ-UP3F3571V | 0603 | ERJ-UP3F3571V
C402 | 470 pF | Capacitor_SMD:C_0402_1005Metric | ~ |  | 0402B471K500NT | 1 | 0402B471K500NT | VJ0402Y471JXQPW1BC | 0402 | VJ0402Y471JXQPW1BC
R405 | 2.21 MΩ | Resistor_SMD:R_0603_1608Metric | ~ |  | WR06W2214FTL | 0 | - - - | MCT06030C2214FP500 | 0603 | MCT06030C2214FP500
R406 | 301 kΩ | Resistor_SMD:R_0603_1608Metric | ~ |  | 0603WAF301KT5E | 0 | - - - | ERJ-UP3F3013V | 0603 | ERJ-UP3F3013V
C405 | 10 uF | Capacitor_SMD:C_0805_2012Metric | ~ |  | CL21A106KAYNNNE | 1 | CL21A106KAYNNNE | JMF212AB7106KGHT | 0805 | JMF212AB7106KGHT
C404 | 10 uF | Capacitor_SMD:C_0805_2012Metric | ~ |  | CL21A106KAYNNNE | 1 | CL21A106KAYNNNE | JMF212AB7106KGHT | 0805 | JMF212AB7106KGHT
C401 | 10 uF | Capacitor_SMD:C_0805_2012Metric | ~ |  | CL21A106KAYNNNE | 1 | CL21A106KAYNNNE | JMF212AB7106KGHT | 0805 | JMF212AB7106KGHT
TP401 | TestPoint | EPS_v3_Library:TESTPOINT_5013 | ~ |  | - - - | 0 | - - - | 5013 | TP | - - -
TP402 | TestPoint | EPS_v3_Library:TESTPOINT_5013 | ~ |  | - - - | 0 | - - - | 5013 | TP | - - -
R401 | 0 Ω | Resistor_SMD:R_0603_1608Metric | ~ |  | 0402WGF0000TCE | 1 | 0603WAF0000T5E | RC0603JR-100RL | 0603 | RCS04020000Z0ED
R407 | 0 Ω | Resistor_SMD:R_0603_1608Metric | ~ |  | 0402WGF0000TCE | 1 | 0603WAF0000T5E | RC0603JR-100RL | 0603 | RCS04020000Z0ED
R404 | 0 Ω | Resistor_SMD:R_0603_1608Metric | ~ |  | 0402WGF0000TCE | 1 | 0603WAF0000T5E | RC0603JR-100RL | 0603 | RCS04020000Z0ED
U501 | LTC4013EUFD-PBF | EPS_v3_Library:LTC4013EUFD-PBF |  |  | - - - | 0 | - - - | LTC4013EUFD#PBF | QFN-28 | - - -
R502 | 1.5 MΩ | Resistor_SMD:R_0603_1608Metric | ~ |  | 0603WAF1504T5E | 1 | 0603WAF1504T5E | ERJ-PA3J155V | 0603 | ERJ-PA3J155V
R503 | 1 MΩ | Resistor_SMD:R_0603_1608Metric | ~ |  | 0603WAF1004T5E | 1 | 0603WAF1004T5E | ERJ-PA3J105V | 0603 | ERJ-PA3J105V
R509 | 22 mΩ | Resistor_SMD:R_0815_2038Metric | ~ |  | - - - | 0 | - - - | ERJ-6CWDR022V | 0805 | - - -
C507 | 0.22 uF | Capacitor_SMD:C_0603_1608Metric | ~ |  | CL10B224KA8NNNC | 1 | CL10B224KA8NNNC | CL10B224KA8NNNC | 0603 | CL10B224KA8NNNC
D501 | 1A | EPS_v3_Library:DO-214BA-2 | ~ |  | - - - | 0 | - - - | LSM115JE3/TR13 | DO-214BA-2 | - - -
L501 | 2.1 uH | EPS_v3_Library:NR10050T2R1N | ~ |  | - - - | 0 | - - - | NR10050T2R1N | 1005 | - - -
C509 | 10 uF | Capacitor_SMD:C_0805_2012Metric | ~ |  | CL10A106KP8NNNC | 1 | CL21A106KAYNNNE | JMF212AB7106KGHT | 0805 | GRM188R60J106ME84J
C501 | 0.1 uF | Capacitor_SMD:C_0603_1608Metric | ~ |  | CC0603KRX7R9BB104 | 1 | CC0603KRX7R9BB104 | CC0603KRX7R9BB104 | 0603 | CC0603KRX7R9BB104
R504 | 86.6 kΩ | Resistor_SMD:R_0603_1608Metric | ~ |  | 0603WAF8662T5E | 0 | - - - | ERJ-PA3F8662V | 0603 | ERJ-PA3F8662V
R505 | 75 kΩ | Resistor_SMD:R_0603_1608Metric | ~ |  | 0603WAF7502T5E | 1 | 0603WAF7502T5E | ERJ-UP3F7502V | 0603 | ERJ-UP3F7502V
R506 | 3.36 kΩ | Resistor_SMD:R_0603_1608Metric | ~ |  | - - - | 0 | - - - | RN731JTTD3361D100 | 0603 | - - -
C504 | 0.01 uF | Capacitor_SMD:C_0402_1005Metric | ~ |  | CL05B103KB5NNNC | 1 | CL05B103KB5NNNC | CL05B103KB5NNNC | 0402 | CL05B103KB5NNNC
R507 | 1 MΩ | Resistor_SMD:R_0603_1608Metric | ~ |  | 0603WAF1004T5E | 1 | 0603WAF1004T5E | ERJ-PA3J105V | 0603 | ERJ-PA3J105V
R508 | 1 MΩ | Resistor_SMD:R_0603_1608Metric | ~ |  | 0603WAF1004T5E | 1 | 0603WAF1004T5E | ERJ-PA3J105V | 0603 | ERJ-PA3J105V
C502 | 10 uF | Capacitor_SMD:C_0805_2012Metric | ~ |  | CL21A106KAYNNNE | 1 | CL21A106KAYNNNE | JMF212AB7106KGHT | 0805 | JMF212AB7106KGHT
C503 | 10 uF | Capacitor_SMD:C_0805_2012Metric | ~ |  | CL21A106KAYNNNE | 1 | CL21A106KAYNNNE | JMF212AB7106KGHT | 0805 | JMF212AB7106KGHT
C505 | 10 uF | Capacitor_SMD:C_0805_2012Metric | ~ |  | CL21A106KAYNNNE | 1 | CL21A106KAYNNNE | JMF212AB7106KGHT | 0805 | JMF212AB7106KGHT
C506 | 10 uF | Capacitor_SMD:C_0805_2012Metric | ~ |  | CL21A106KAYNNNE | 1 | CL21A106KAYNNNE | JMF212AB7106KGHT | 0805 | JMF212AB7106KGHT
C508 | 10 uF | Capacitor_SMD:C_0805_2012Metric | ~ |  | CL21A106KAYNNNE | 1 | CL21A106KAYNNNE | JMF212AB7106KGHT | 0805 | JMF212AB7106KGHT
TP502 | TestPoint | EPS_v3_Library:TESTPOINT_5013 | ~ |  | - - - | 0 | - - - | 5013 | TP | - - -
TP501 | TestPoint | EPS_v3_Library:TESTPOINT_5013 | ~ |  | - - - | 0 | - - - | 5013 | TP | - - -
R501 | 0 Ω | Resistor_SMD:R_0603_1608Metric | ~ |  | 0402WGF0000TCE | 1 | 0603WAF0000T5E | RC0603JR-100RL | 0603 | RCS04020000Z0ED
R510 | 0 Ω | Resistor_SMD:R_0603_1608Metric | ~ |  | 0402WGF0000TCE | 1 | 0603WAF0000T5E | RC0603JR-100RL | 0603 | RCS04020000Z0ED
Q501 | INFET | EPS_v3_Library:DMN1019USN-7(TSOT-26-6) | ~ |  | DMN1019UVT-7 | 0 | - - - | DMN1019UVT-7 | TSOT-26-6 | DMN1019UVT-7
Q502 | T_NMOS | EPS_v3_Library:DMN1019USN-7(TSOT-26-6) | ~ |  | DMN1019UVT-7 | 0 | - - - | DMN1019UVT-7 | TSOT-26-6 | DMN1019UVT-7
Q503 | B_NMOS | EPS_v3_Library:DMN1019USN-7(TSOT-26-6) | ~ |  | DMN1019UVT-7 | 0 | - - - | DMN1019UVT-7 | TSOT-26-6 | DMN1019UVT-7
U601 | SPV1040T | EPS_v3_Library:SPV1040T |  |  | - - - | 0 | - - - | SPV1040T | TSSOP-8 | - - -
C601 | 100 uF | Capacitor_SMD:C_1210_3225Metric | ~ |  | TAJB107K006RNJ | 0 | - - - | JMK325ABJ107MM-P | 1210 | JMK325ABJ107MM-P
L601 | 47 uH | EPS_v3_Library:NRS5020T4R7MMGJ | ~ |  | - - - | 0 | - - - | NRS5020T470MMGJV | 5020 | - - -
D601 | Vf=0.3V and If=3A | EPS_v3_Library:DO-214AB-2 | ~ |  | - - - | 0 | - - - | VS-30BQ015-M3/9AT | DO-214AB-2 | - - -
R610 | 33.2 mΩ | Resistor_SMD:R_0805_2012Metric | ~ |  | - - - | 0 | - - - | RCWH080533L2FNEA | 0805 | - - -
R613 | 2 MΩ | Resistor_SMD:R_0603_1608Metric | ~ |  | 0402WGF2004TCE | 1 | 0603WAF2004T5E | ERJ-2GEJ205X | 0603 | ERJ-2GEJ205X
R614 | 680 kΩ | Resistor_SMD:R_0402_1005Metric | ~ |  | - - - | 1 | 0402WGF6803TCE | CR0402-FX-6803GLF | 0402 | - - -
C604 | 1 uF | Capacitor_SMD:C_0402_1005Metric | ~ |  | CL05A105KA5NQNC | 1 | CL05A105KA5NQNC | JMK105BJ105MV8F | 0402 | JMK105BJ105MV8F
R604 | 1 kΩ | Resistor_SMD:R_0402_1005Metric | ~ |  | 0402WGF1001TCE | 1 | 0402WGF1001TCE | RCS04021K00JNED | 0402 | RCS04021K00JNED
R605 | 1 kΩ | Resistor_SMD:R_0402_1005Metric | ~ |  | 0402WGF1001TCE | 1 | 0402WGF1001TCE | RCS04021K00JNED | 0402 | RCS04021K00JNED
C607 | 150 uF | Capacitor_SMD:C_1210_3225Metric | ~ |  | - - - | 0 | - - - | CL32A157MQVNNNE | 1210 | - - -
D604 | Vf=0.3V and If=3A | EPS_v3_Library:DO-214AB-2 | ~ |  | - - - | 0 | - - - | VS-30BQ015-M3/9AT | DO-214AB-2 | - - -
U602 | SPV1040T | EPS_v3_Library:SPV1040T |  |  | - - - | 0 | - - - | SPV1040T | TSSOP-8 | - - -
L602 | 47 uH | EPS_v3_Library:NRS5020T4R7MMGJ | ~ |  | - - - | 0 | - - - | NRS5020T470MMGJV | 5020 | - - -
D602 | Vf=0.3V and If=3A | EPS_v3_Library:DO-214AB-2 | ~ |  | - - - | 0 | - - - | VS-30BQ015-M3/9AT | DO-214AB-2 | - - -
R611 | 33.2 mΩ | Resistor_SMD:R_0805_2012Metric | ~ |  | - - - | 0 | - - - | RCWH080533L2FNEA | 0805 | - - -
R615 | 2 MΩ | Resistor_SMD:R_0603_1608Metric | ~ |  | 0402WGF2004TCE | 1 | 0603WAF2004T5E | ERJ-2GEJ205X | 0603 | ERJ-2GEJ205X
R616 | 680 kΩ | Resistor_SMD:R_0402_1005Metric | ~ |  | - - - | 1 | 0402WGF6803TCE | CR0402-FX-6803GLF | 0402 | - - -
C605 | 1 uF | Capacitor_SMD:C_0402_1005Metric | ~ |  | CL05A105KA5NQNC | 1 | CL05A105KA5NQNC | JMK105BJ105MV8F | 0402 | JMK105BJ105MV8F
R606 | 1 kΩ | Resistor_SMD:R_0402_1005Metric | ~ |  | 0402WGF1001TCE | 1 | 0402WGF1001TCE | RCS04021K00JNED | 0402 | RCS04021K00JNED
R607 | 1 kΩ | Resistor_SMD:R_0402_1005Metric | ~ |  | 0402WGF1001TCE | 1 | 0402WGF1001TCE | RCS04021K00JNED | 0402 | RCS04021K00JNED
C608 | 150 uF | Capacitor_SMD:C_1210_3225Metric | ~ |  | - - - | 0 | - - - | CL32A157MQVNNNE | 1210 | - - -
D605 | Vf=0.3V and If=3A | EPS_v3_Library:DO-214AB-2 | ~ |  | - - - | 0 | - - - | VS-30BQ015-M3/9AT | DO-214AB-2 | - - -
U603 | SPV1040T | EPS_v3_Library:SPV1040T |  |  | - - - | 0 | - - - | SPV1040T | TSSOP-8 | - - -
L603 | 47 uH | EPS_v3_Library:NRS5020T4R7MMGJ | ~ |  | - - - | 0 | - - - | NRS5020T470MMGJV | 5020 | - - -
D603 | Vf=0.3V and If=3A | EPS_v3_Library:DO-214AB-2 | ~ |  | - - - | 0 | - - - | VS-30BQ015-M3/9AT | DO-214AB-2 | - - -
R612 | 33.2 mΩ | Resistor_SMD:R_0805_2012Metric | ~ |  | - - - | 0 | - - - | RCWH080533L2FNEA | 0805 | - - -
R617 | 2 MΩ | Resistor_SMD:R_0603_1608Metric | ~ |  | 0402WGF2004TCE | 1 | 0603WAF2004T5E | ERJ-2GEJ205X | 0603 | ERJ-2GEJ205X
R618 | 680 kΩ | Resistor_SMD:R_0402_1005Metric | ~ |  | - - - | 1 | 0402WGF6803TCE | CR0402-FX-6803GLF | 0402 | - - -
C606 | 1 uF | Capacitor_SMD:C_0402_1005Metric | ~ |  | CL05A105KA5NQNC | 1 | CL05A105KA5NQNC | JMK105BJ105MV8F | 0402 | JMK105BJ105MV8F
R608 | 1 kΩ | Resistor_SMD:R_0402_1005Metric | ~ |  | 0402WGF1001TCE | 1 | 0402WGF1001TCE | RCS04021K00JNED | 0402 | RCS04021K00JNED
R609 | 1 kΩ | Resistor_SMD:R_0402_1005Metric | ~ |  | 0402WGF1001TCE | 1 | 0402WGF1001TCE | RCS04021K00JNED | 0402 | RCS04021K00JNED
C609 | 150 uF | Capacitor_SMD:C_1210_3225Metric | ~ |  | - - - | 0 | - - - | CL32A157MQVNNNE | 1210 | - - -
D606 | Vf=0.3V and If=3A | EPS_v3_Library:DO-214AB-2 | ~ |  | - - - | 0 | - - - | VS-30BQ015-M3/9AT | DO-214AB-2 | - - -
U604 | SPV1040T | EPS_v3_Library:SPV1040T |  |  | - - - | 0 | - - - | SPV1040T | TSSOP-8 | - - -
L604 | 47 uH | EPS_v3_Library:NRS5020T4R7MMGJ | ~ |  | - - - | 0 | - - - | NRS5020T470MMGJV | 5020 | - - -
D607 | Vf=0.3V and If=3A | EPS_v3_Library:DO-214AB-2 | ~ |  | - - - | 0 | - - - | VS-30BQ015-M3/9AT | DO-214AB-2 | - - -
R628 | 33.2 mΩ | Resistor_SMD:R_0805_2012Metric | ~ |  | - - - | 0 | - - - | RCWH080533L2FNEA | 0805 | - - -
R631 | 2 MΩ | Resistor_SMD:R_0603_1608Metric | ~ |  | 0402WGF2004TCE | 1 | 0603WAF2004T5E | ERJ-2GEJ205X | 0603 | ERJ-2GEJ205X
R632 | 680 kΩ | Resistor_SMD:R_0402_1005Metric | ~ |  | - - - | 1 | 0402WGF6803TCE | CR0402-FX-6803GLF | 0402 | - - -
C613 | 1 uF | Capacitor_SMD:C_0402_1005Metric | ~ |  | CL05A105KA5NQNC | 1 | CL05A105KA5NQNC | JMK105BJ105MV8F | 0402 | JMK105BJ105MV8F
R622 | 1 kΩ | Resistor_SMD:R_0402_1005Metric | ~ |  | 0402WGF1001TCE | 1 | 0402WGF1001TCE | RCS04021K00JNED | 0402 | RCS04021K00JNED
R623 | 1 kΩ | Resistor_SMD:R_0402_1005Metric | ~ |  | 0402WGF1001TCE | 1 | 0402WGF1001TCE | RCS04021K00JNED | 0402 | RCS04021K00JNED
C616 | 150 uF | Capacitor_SMD:C_1210_3225Metric | ~ |  | - - - | 0 | - - - | CL32A157MQVNNNE | 1210 | - - -
D610 | Vf=0.3V and If=3A | EPS_v3_Library:DO-214AB-2 | ~ |  | - - - | 0 | - - - | VS-30BQ015-M3/9AT | DO-214AB-2 | - - -
U605 | SPV1040T | EPS_v3_Library:SPV1040T |  |  | - - - | 0 | - - - | SPV1040T | TSSOP-8 | - - -
L605 | 47 uH | EPS_v3_Library:NRS5020T4R7MMGJ | ~ |  | - - - | 0 | - - - | NRS5020T470MMGJV | 5020 | - - -
D608 | Vf=0.3V and If=3A | EPS_v3_Library:DO-214AB-2 | ~ |  | - - - | 0 | - - - | VS-30BQ015-M3/9AT | DO-214AB-2 | - - -
R629 | 33.2 mΩ | Resistor_SMD:R_0805_2012Metric | ~ |  | - - - | 0 | - - - | RCWH080533L2FNEA | 0805 | - - -
R633 | 2 MΩ | Resistor_SMD:R_0603_1608Metric | ~ |  | 0402WGF2004TCE | 1 | 0603WAF2004T5E | ERJ-2GEJ205X | 0603 | ERJ-2GEJ205X
R634 | 680 kΩ | Resistor_SMD:R_0402_1005Metric | ~ |  | - - - | 1 | 0402WGF6803TCE | CR0402-FX-6803GLF | 0402 | - - -
C614 | 1 uF | Capacitor_SMD:C_0402_1005Metric | ~ |  | CL05A105KA5NQNC | 1 | CL05A105KA5NQNC | JMK105BJ105MV8F | 0402 | JMK105BJ105MV8F
R624 | 1 kΩ | Resistor_SMD:R_0402_1005Metric | ~ |  | 0402WGF1001TCE | 1 | 0402WGF1001TCE | RCS04021K00JNED | 0402 | RCS04021K00JNED
R625 | 1 kΩ | Resistor_SMD:R_0402_1005Metric | ~ |  | 0402WGF1001TCE | 1 | 0402WGF1001TCE | RCS04021K00JNED | 0402 | RCS04021K00JNED
C617 | 150 uF | Capacitor_SMD:C_1210_3225Metric | ~ |  | - - - | 0 | - - - | CL32A157MQVNNNE | 1210 | - - -
D611 | Vf=0.3V and If=3A | EPS_v3_Library:DO-214AB-2 | ~ |  | - - - | 0 | - - - | VS-30BQ015-M3/9AT | DO-214AB-2 | - - -
U606 | SPV1040T | EPS_v3_Library:SPV1040T |  |  | - - - | 0 | - - - | SPV1040T | TSSOP-8 | - - -
L606 | 47 uH | EPS_v3_Library:NRS5020T4R7MMGJ | ~ |  | - - - | 0 | - - - | NRS5020T470MMGJV | 5020 | - - -
D609 | Vf=0.3V and If=3A | EPS_v3_Library:DO-214AB-2 | ~ |  | - - - | 0 | - - - | VS-30BQ015-M3/9AT | DO-214AB-2 | - - -
R630 | 33.2 mΩ | Resistor_SMD:R_0805_2012Metric | ~ |  | - - - | 0 | - - - | RCWH080533L2FNEA | 0805 | - - -
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

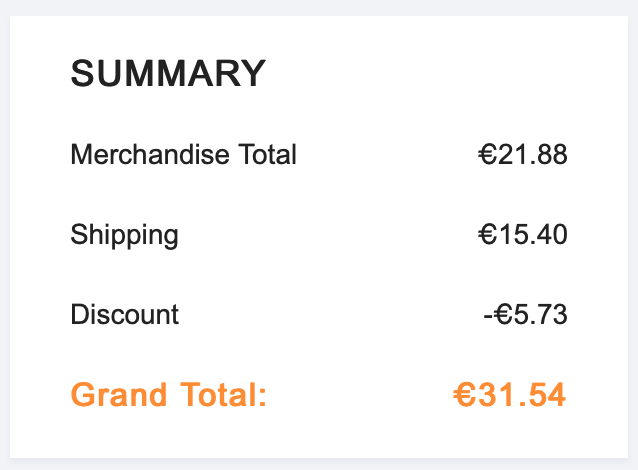
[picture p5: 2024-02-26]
Hardware/EPS_v3_Assembly/JLCPCB Final Cost.png

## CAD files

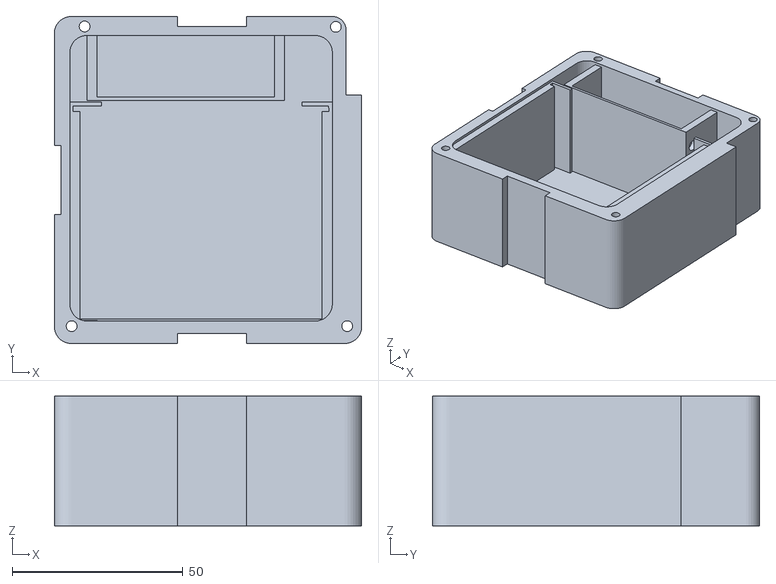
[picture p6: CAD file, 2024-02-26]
CAD/Cuerpo.stl
90.2 x 95.9 x 38.0

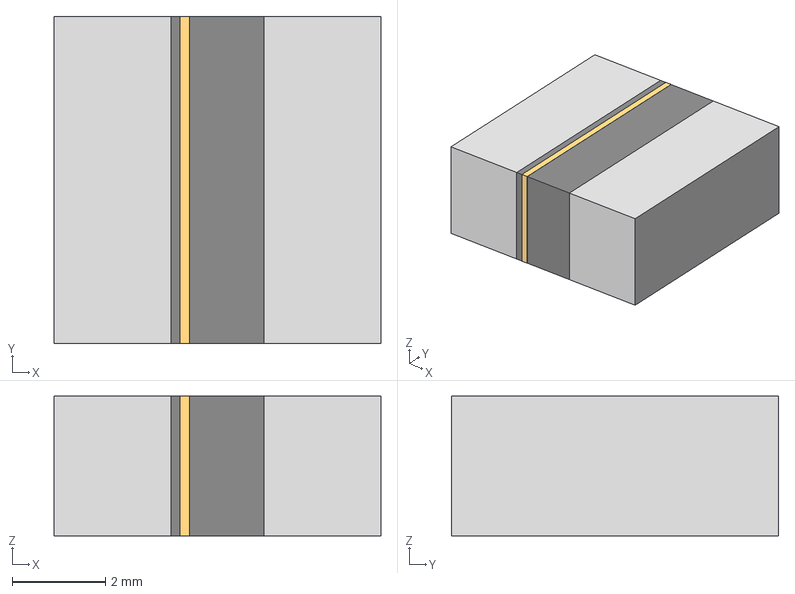
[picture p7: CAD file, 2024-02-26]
Hardware/EPS_v3_Library/3D/IND_PM628S.step
7.01 x 7.02 x 3.00 mm

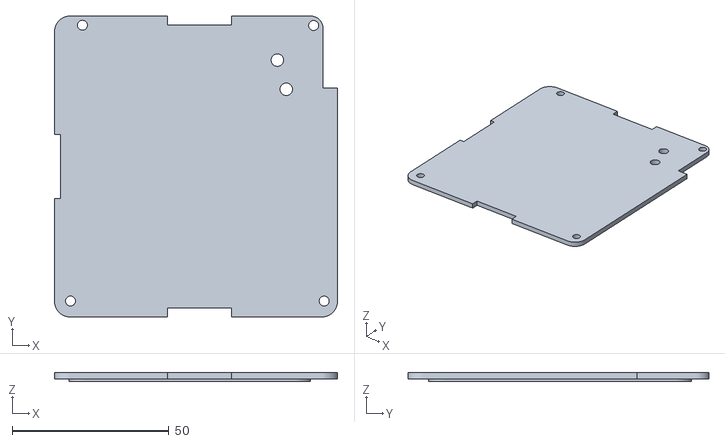
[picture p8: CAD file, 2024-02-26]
CAD/Tapa.stl
90.2 x 95.9 x 2.80

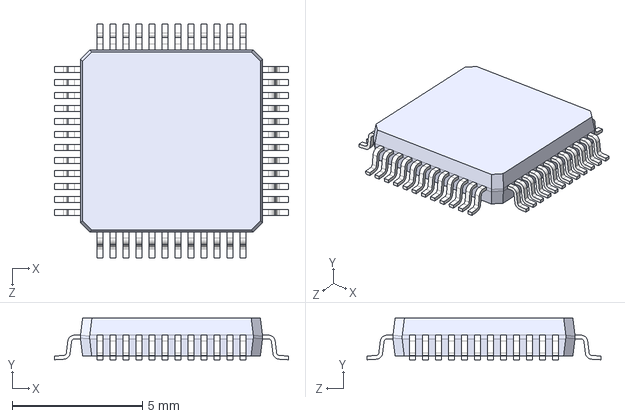
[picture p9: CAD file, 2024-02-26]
Hardware/EPS_v3_Library/3D/STM32L412C8T6.STEP
9.00 x 1.60 x 9.00 mm

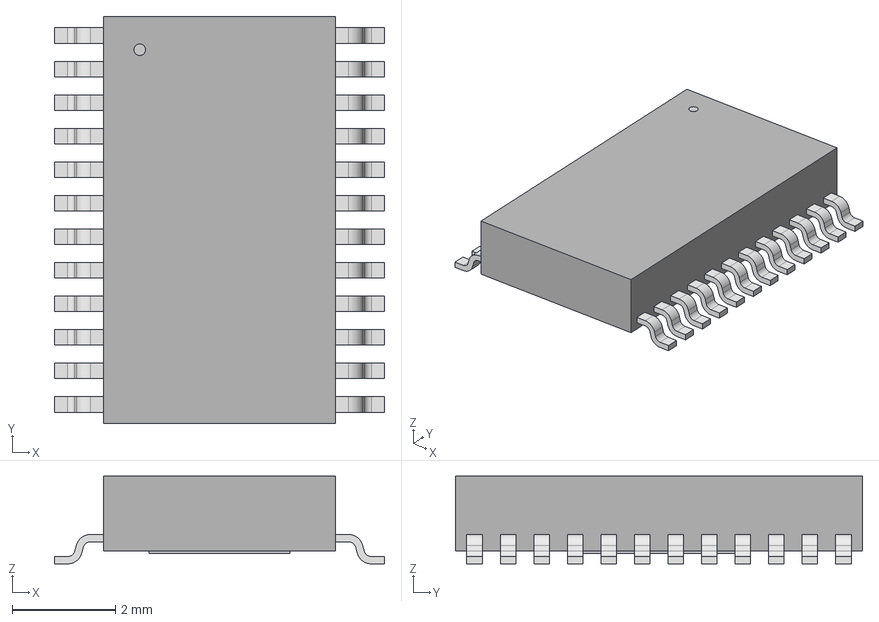
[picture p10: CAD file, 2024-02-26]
Hardware/EPS_v3_Library/3D/LTC3128EFEPBF_TSSOP-24_FEAA_LIT.step
6.40 x 7.90 x 1.70 mm

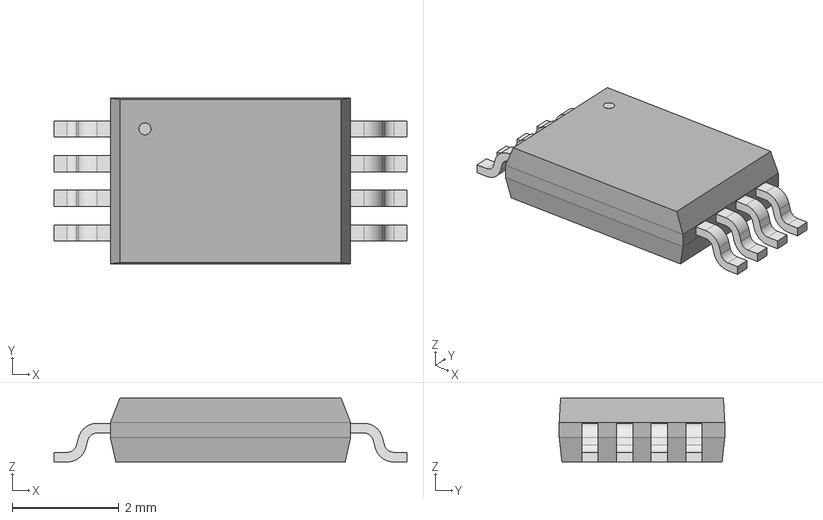
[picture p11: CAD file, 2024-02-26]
Hardware/EPS_v3_Library/3D/SPV1040T.step
6.60 x 3.10 x 1.20 mm

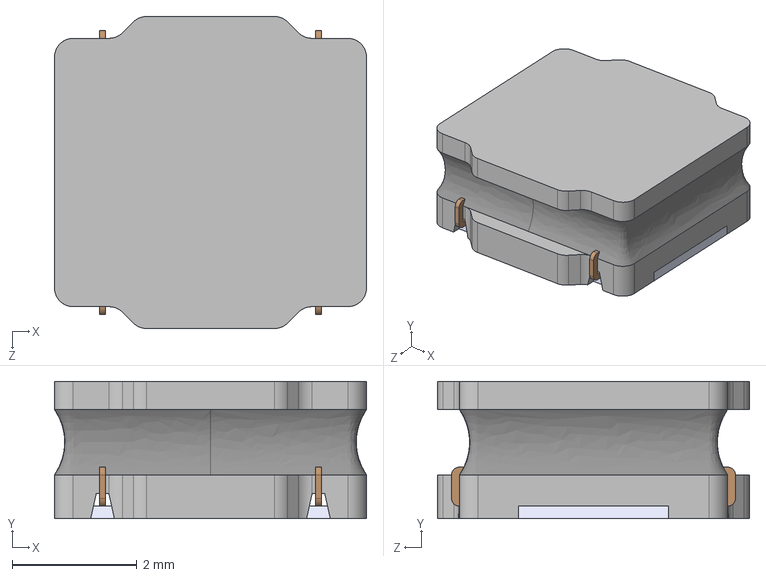
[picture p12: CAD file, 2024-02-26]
Hardware/EPS_v3_Library/3D/LQH5BPN2R7NT0L.step
5.00 x 2.20 x 5.00 mm

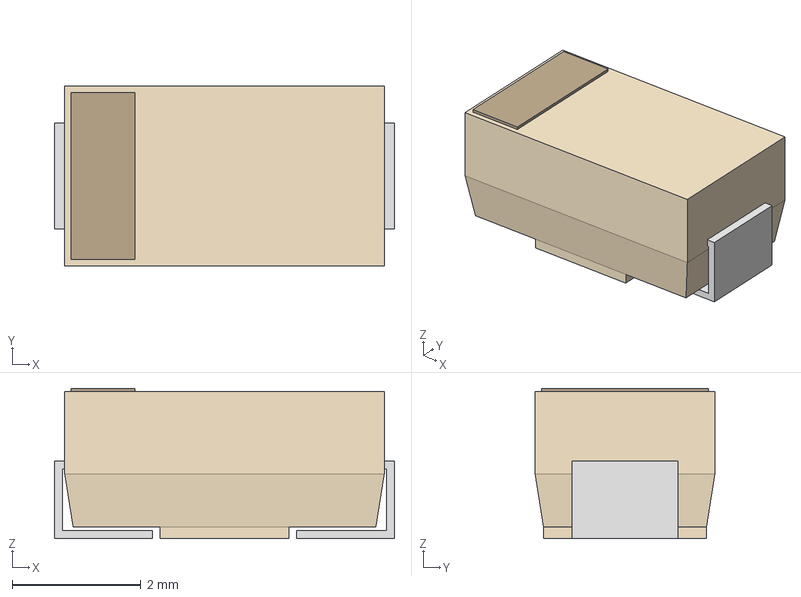
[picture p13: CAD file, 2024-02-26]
Hardware/EPS_v3_Library/3D/DIODE_DO-214AC.step
5.28 x 2.79 x 2.34 mm

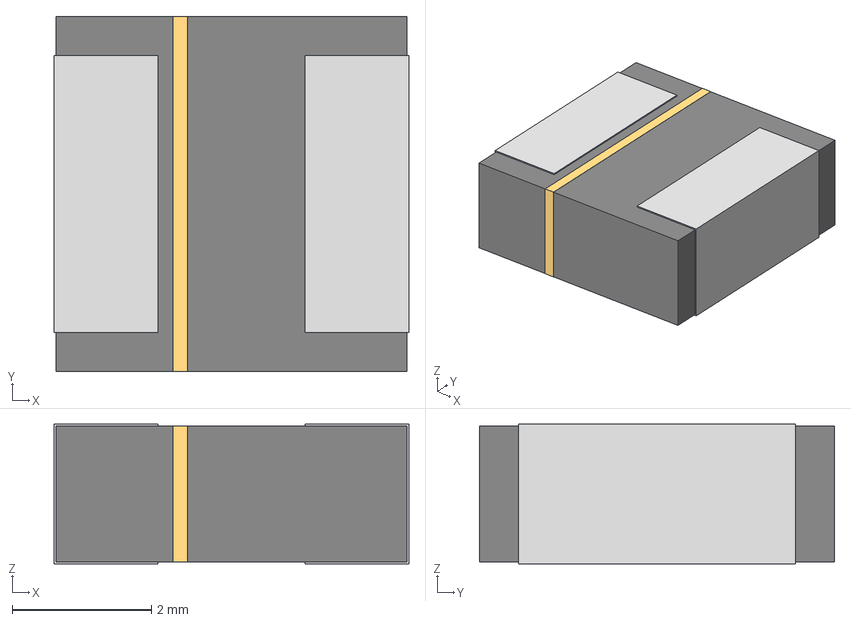
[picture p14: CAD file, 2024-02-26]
Hardware/EPS_v3_Library/3D/NRS5020T4R7MMGJ_IND_TAIYO_NRS5020_TAY.step
5.11 x 5.11 x 2.01 mm

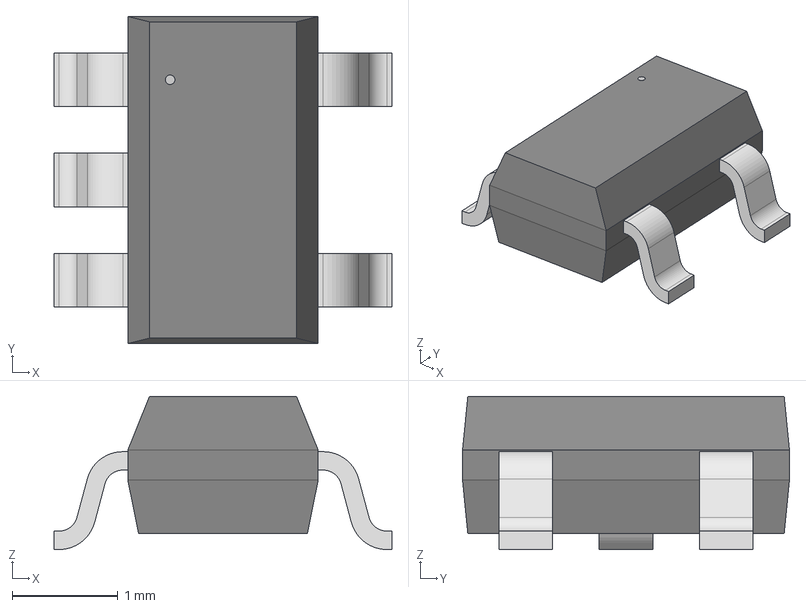
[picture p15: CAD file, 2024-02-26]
Hardware/EPS_v3_Library/3D/MCP1320T29LEOT_SOT-23-5_MC_MCH.step
3.20 x 3.10 x 1.45 mm

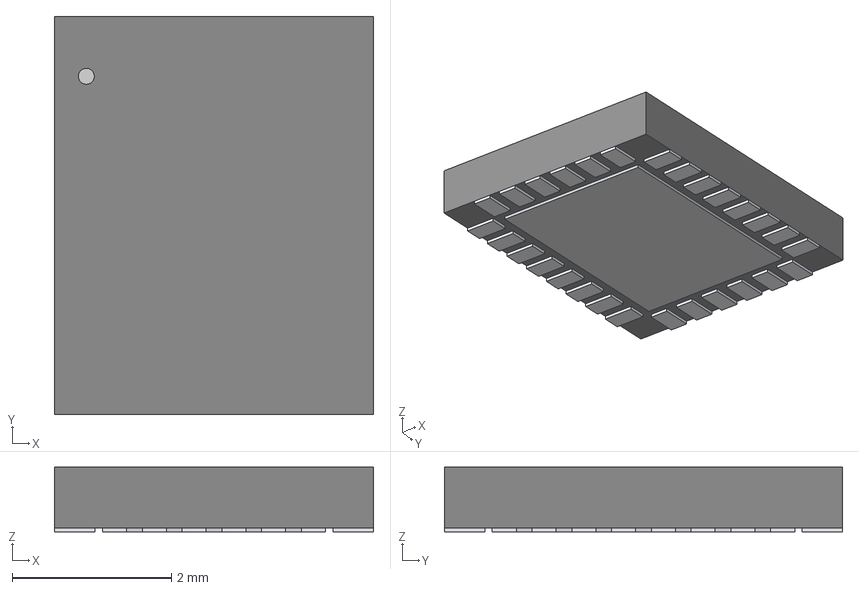
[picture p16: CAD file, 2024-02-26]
Hardware/EPS_v3_Library/3D/LTC4013EUFDPBF_UFD_28_ADI.step
4.01 x 5.00 x 0.815 mm

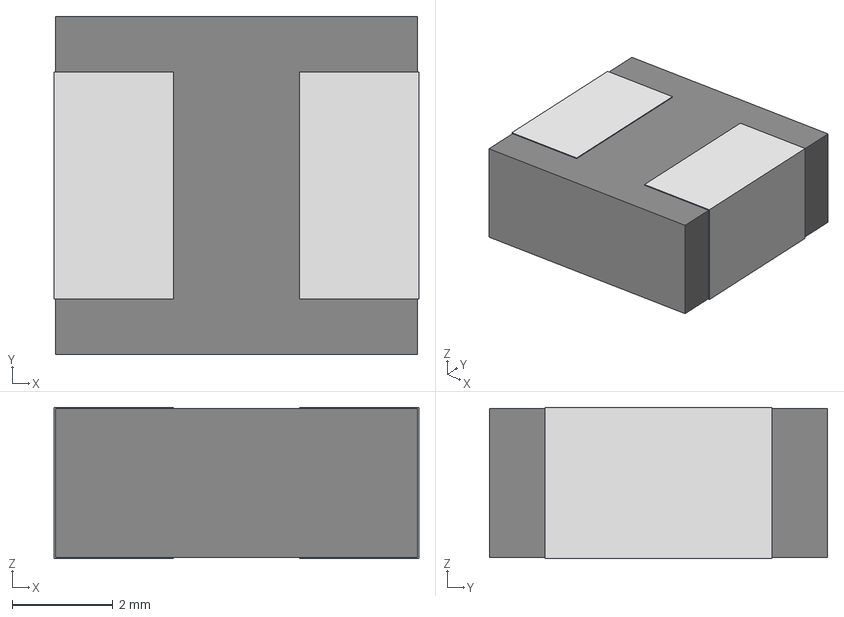
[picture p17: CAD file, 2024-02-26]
Hardware/EPS_v3_Library/3D/FP3-3R3-R.step
7.24 x 6.71 x 3.00 mm

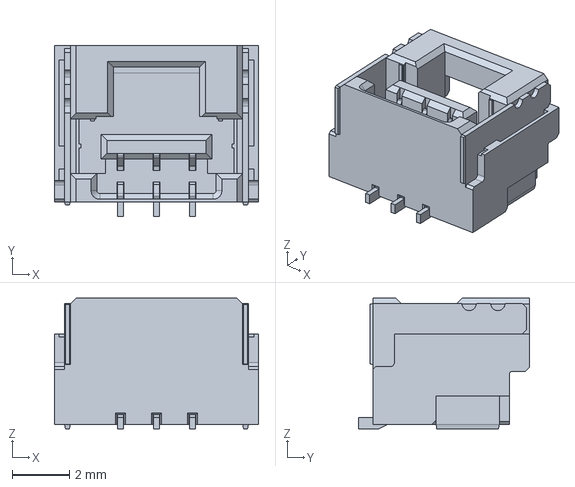
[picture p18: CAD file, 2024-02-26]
Hardware/EPS_v3_Library/3D/MOLEX_502382-0370.stp
7.10 x 5.95 x 4.55 mm

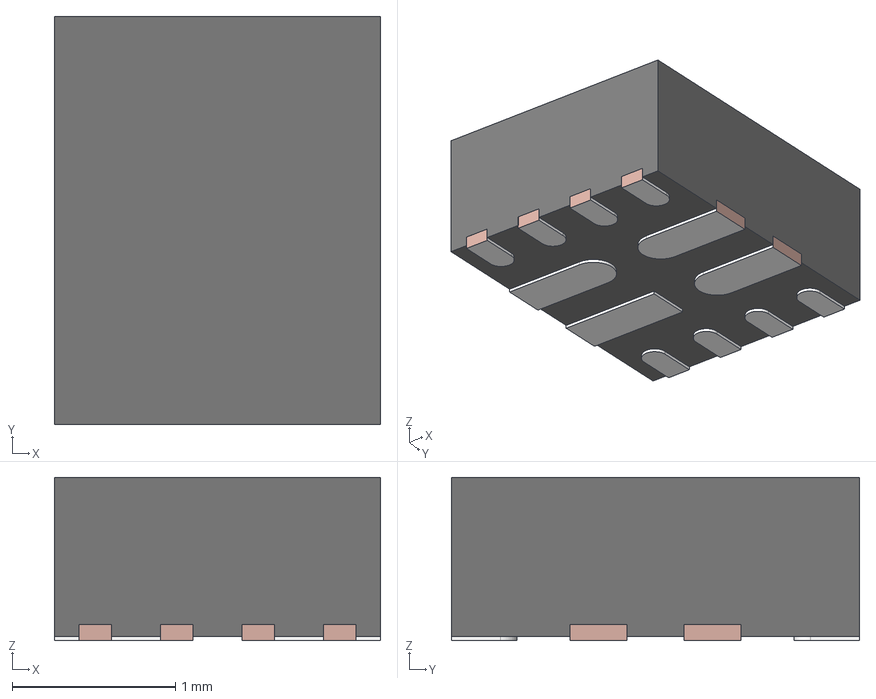
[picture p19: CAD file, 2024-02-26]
Hardware/EPS_v3_Library/3D/TPS2121RUXR.stp
2.00 x 2.50 x 1.00 mm
FRAME
MOLD

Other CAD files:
Hardware/EPS_v3_Library/3D/DO-214BA_VIS.step
Hardware/EPS_v3_Library/3D/DMN1019USN-7_SOT_9USN-7_DIO.step
Hardware/EPS_v3_Library/3D/IND_TAIYO_NR10050_TAY.step
Hardware/EPS_v3_Library/3D/IND_CB_DRA125.step
Hardware/EPS_v3_Library/3D/532610371.stp
Hardware/EPS_v3_Library/3D/TPS61288RQQR.stp
Hardware/EPS_v3_Library/3D/TPS630242YFFR.STEP

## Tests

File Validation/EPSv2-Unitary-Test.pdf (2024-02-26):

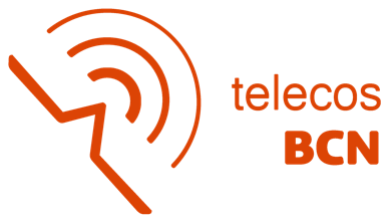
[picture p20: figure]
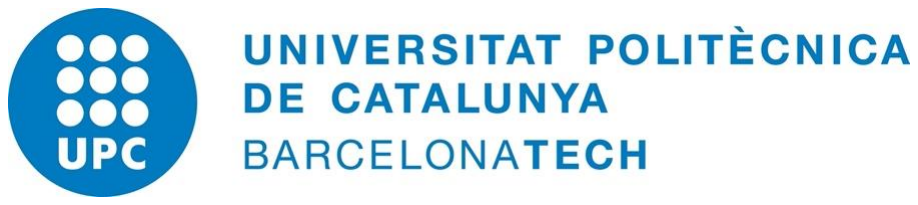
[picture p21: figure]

# Unitary Test

## MOHAMED BENOMAR EL KATI

## INTRODUCTION TO RESEARCH (IR)

Q2-2020/2021

Table of Contents

EPSv2_Unitary_Test

## 1. Description

The first step is to identify the different ICs on the PCB.

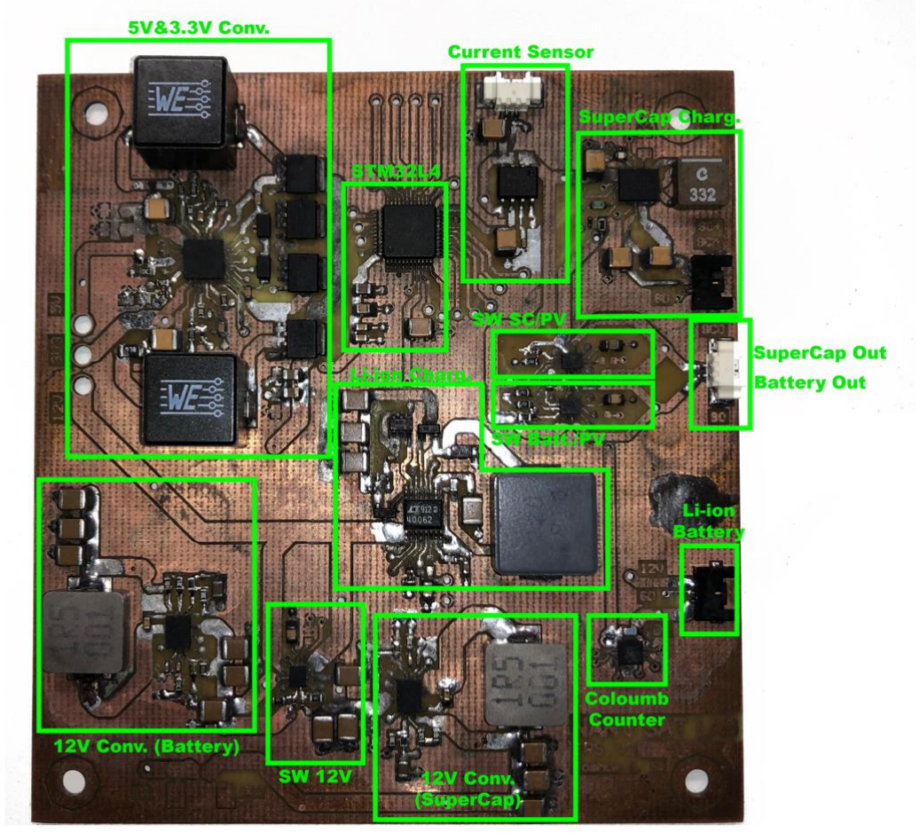
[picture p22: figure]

Figure 1 – PCB description

## EPS_NanoSatLab

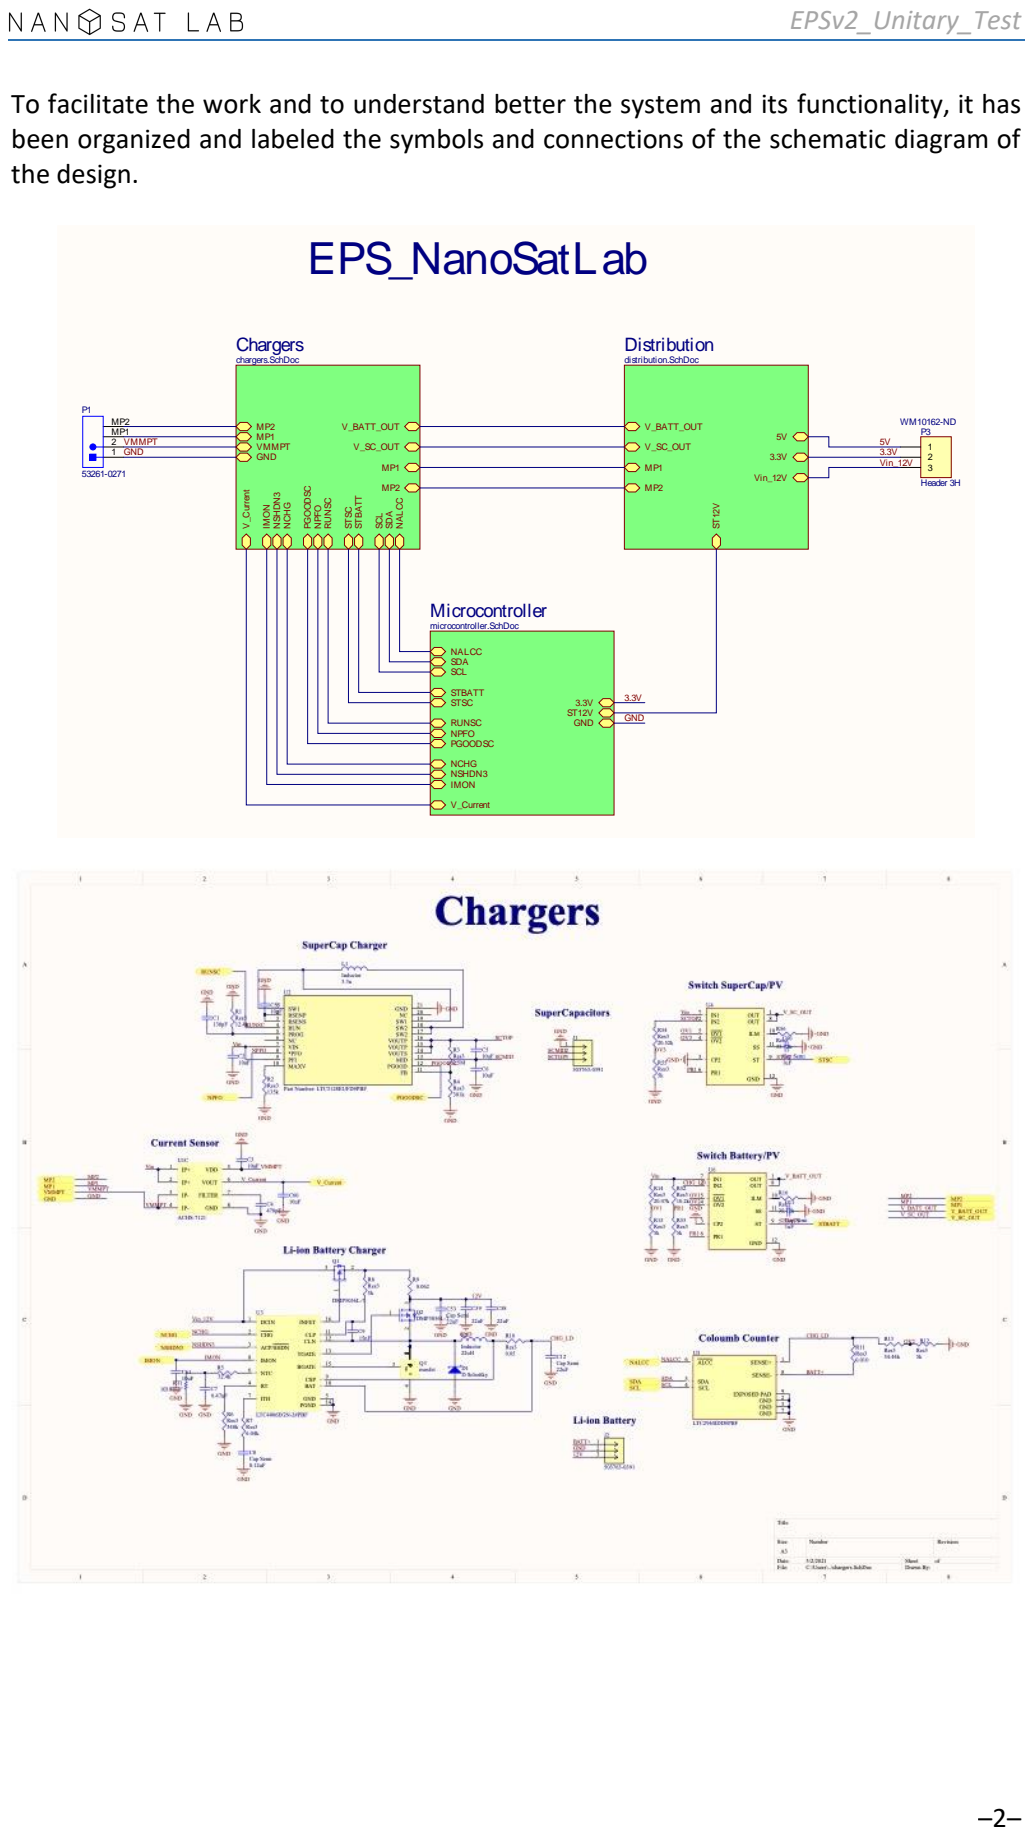
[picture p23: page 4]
VMMPT GND; V_BATT_OUT; V_SC_OUT; SCL; SDA; NALCC; STBATT; STSC; PGOODSC; NPFO; NSHDN3; NCHG; RUNSC; IMON; V_Current; Chargers; chargers.SchDoc; Vin_12V; Distribution; distribution.SchDoc; Header 3H; 5V 3.3V Vin_12V; NALCC SDA SCL; STBATT STSC; 3.3V ST12V GND; Microcontroller; microcontroller.SchDoc; GND

To facilitate the work and to understand better the system and its functionality, it has
been organized and labeled the symbols and connections of the schematic diagram of
the design.

## Distribution

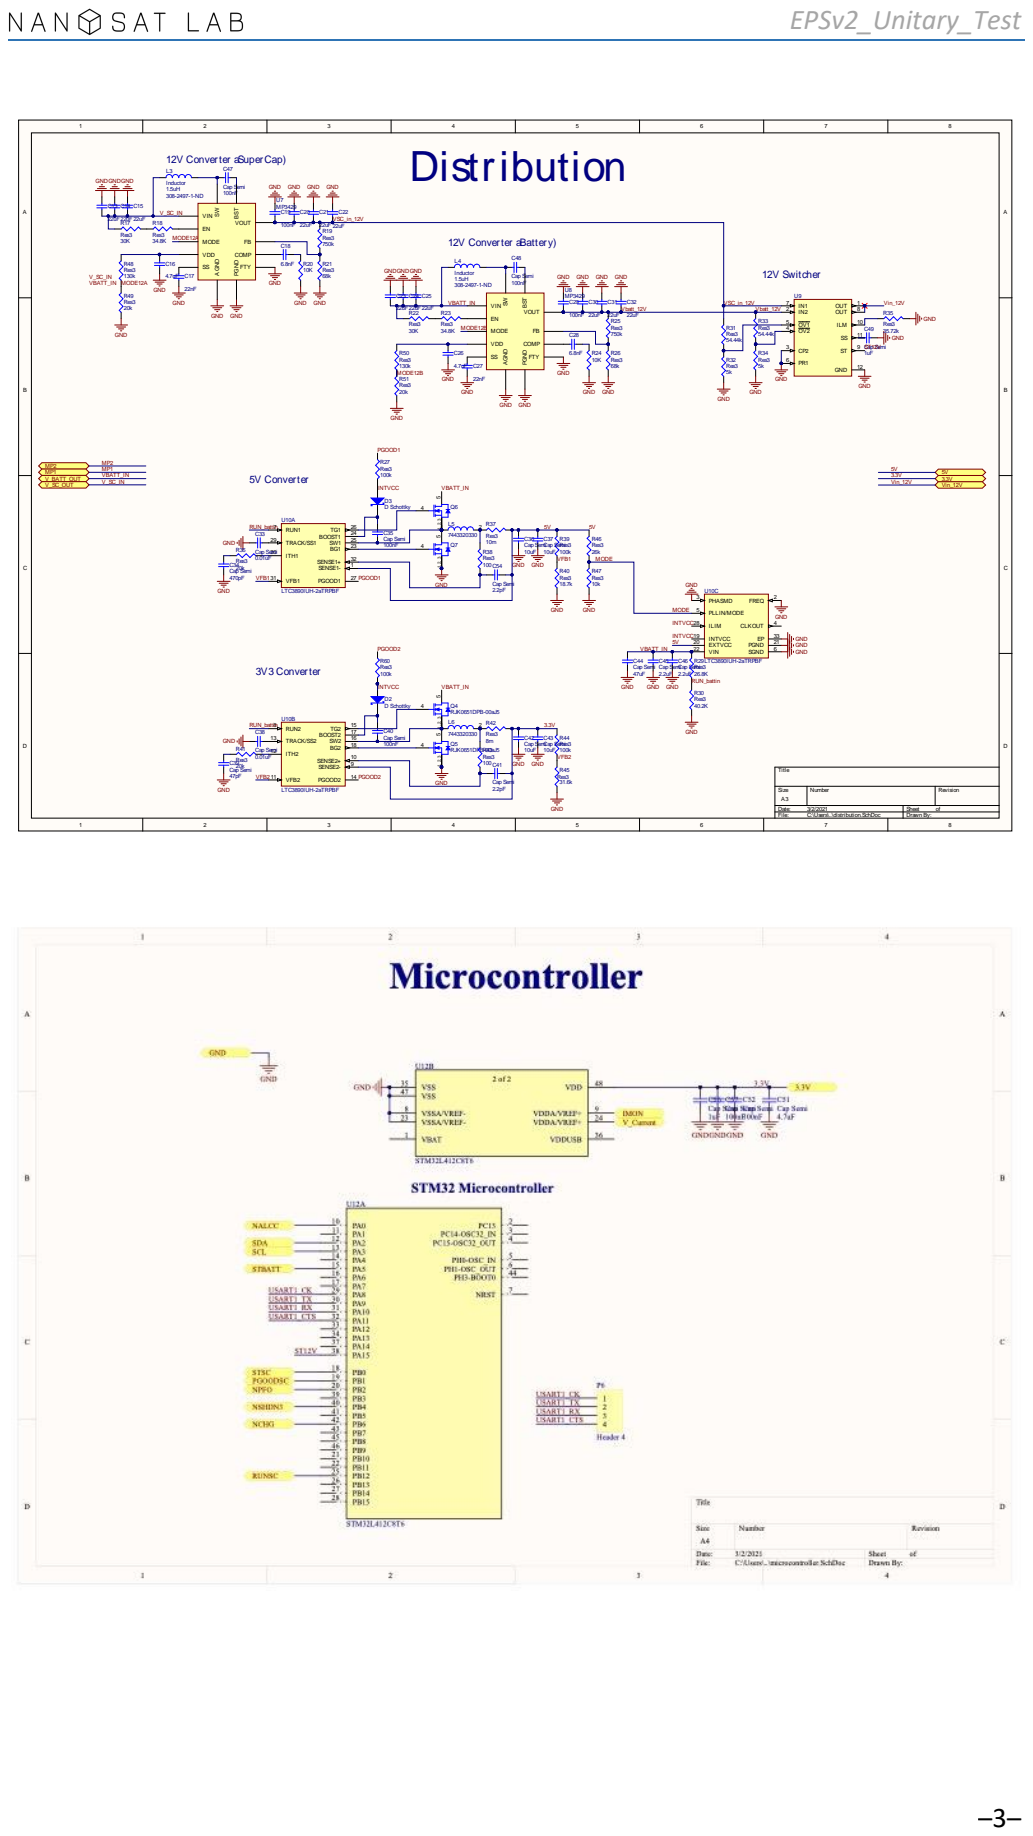
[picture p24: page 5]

C | 3.3V Vin_12V | C

Size A3 | Number | Revision

Date: 3/2/2021 File: C:\Users\..\distribution.SchDoc | Sheet of Drawn By:

## 2. EPS v2 Test

### 2.1 U1: ACHS-7121 (Current Sensor)

2.1.1 Pinout

U1 | 1 | IP+ IP+ | Terminal for current being sampled 2
| 3 | IP- | Terminal for current being sampled
| 4 | IP-
| 5 | GND | Output side ground
| 6 | FILTER | Filter pin to set bandwidth
| 7 | VOUT | Output Voltage
| 8 | VDD | Supply voltage relative to GND

2.1.2 Description

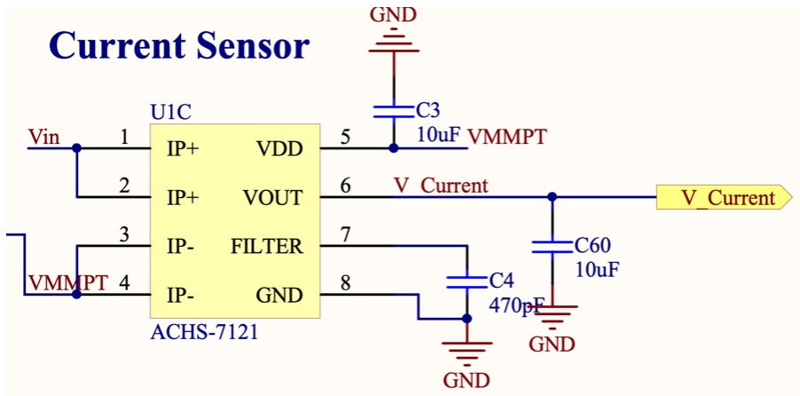
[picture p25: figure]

Vout = 185 · I + 2600 [mV] → ±10A

VoutA = [12 bits ADC] =

VoutD

- 5200
2

12 [mV]

I =

VoutA − 2600
185 =

VoutD

- 5200
4096 | − 2600
185 | =

VoutD

- 5200 − 10649600
757760 | [A]

I = VoutD

- 0,00686233 − 14,0540541 [A]

2.1.3 Validation

The aim of this test is to check the current sensor detects the current as specified by their datasheet. To test it is needed to connect it to the power supply, and a Multimeter to check the voltage that indicates the current passing through the current sensor. To simulate the load, is used a 4.9Ω power resistor and a power supply to change the voltage to vary the current flowing through the resistor.

The aim is to check the output voltage when there is flowing 0.2A, 0.6A, 0.9A, 1.2A and 2.1A. By the Ohm’s Law, the voltages that supply the resistor should be 0.98V, 2.94V, 4.41V, 5.88V and 10.29V.

After checking the output voltage with a multimeter, the performance and sensitivity will be checked by an ADC of the STM32L4 microcontroller.

2.1.4 Results

ID | Designator | Conditions | Date | Result | Judgement | Comments | Expected Value
3.1.4 | Current Sensor (Vout)
3.1.4.1 | Sensitivity = | 185 mV/A | I = 0.20 A | 22/3/2021 | 2460 mV | OK | Vsupply = 0.98 V | 2437 mV
3.1.4.2 | Vdd = | 4.8 V | I = 0.60 A | 22/3/2021 | 2535 mV | OK | Vsupply = 2.94 V | 2511 mV
3.1.4.3 | Vout = | 185*A + 2400 [mV] | I = 0.90 A | 22/3/2021 | 2590 mV | OK | Vsupply = 4.41 V | 2566.5 mV
3.1.4.4 | R = | 4.9 Ω | I = 1.20 A | 22/3/2021 | 2630 mV | OK | Vsupply = 5.88 V | 2622 mV
3.1.4.5 | | | I = 2.10 A | 22/3/2021 | 2790 mV | OK | Vsupply = 10.29 V | 2788.5 mV
3.1.4.6 | Real Sensor Sensitivity | | STM32 | 22/3/2021 | 200 mV/A | OK | | 185 mV/A

### 2.2 U2: LTC3128EUFD#PBF (SuperCap Charger)

2.2.1 Pinout

U2

1 | SW1 | Inductor pin 1 | Inductor pin
2 | RSENP | Sense Resistor Power Output | Connect other loads if necessary
3 | RSENS | Sense Resistor Power In | Connected to RSENSP
4 | RUN | Logic-Controlled Shutdown Input | Run >=1.2V Nor. Op. & <= 0.3V Shutdown
5 | PROG | Average Input Current Limit | Rprog = 11/Ilim & Cprog = 1600/Rprog
6 | NC | – – – (Tied to GND) | – – –
7 | VIN | Input Supply Pin | – – –
8 | *PFO | Power Fail Output | Sinks current when supply < Vth
9 | PFI | Power Fail Input | Supply to be monitored (Input)
10 | MAXV | Maximum voltage across supercap. | RMAXV=50*VMAXV
11 | FB | Output Voltage Feedback | Vout = 0.58*(1+R2/R1)
12 | PGOOD | Power Good Indicator | Low when Vout < Voutprog*96.75%
13 | MID | Output for active charger balancer | Tie to the junction of the two supercaps
14 | VOUTS | Output Sense Input | Tie to the Vout supercapacitor
15 | VOUTP | Output Synchronous Rectifier | Tie to the Vout supercapacitor
16 | VOUTP | Output Synchronous Rectifier | Tie to the Vout supercapacitor
17 | SW2 | Inductor pin 2 | Inductor pin
18 | SW2 | Inductor pin 2 | Inductor pin
19 | SW1 | Inductor pin 1 | Inductor pin
20 | NC | – – – (Tied to GND) | – – –
21 | GND | Ground | – – –

2.2.2 Description

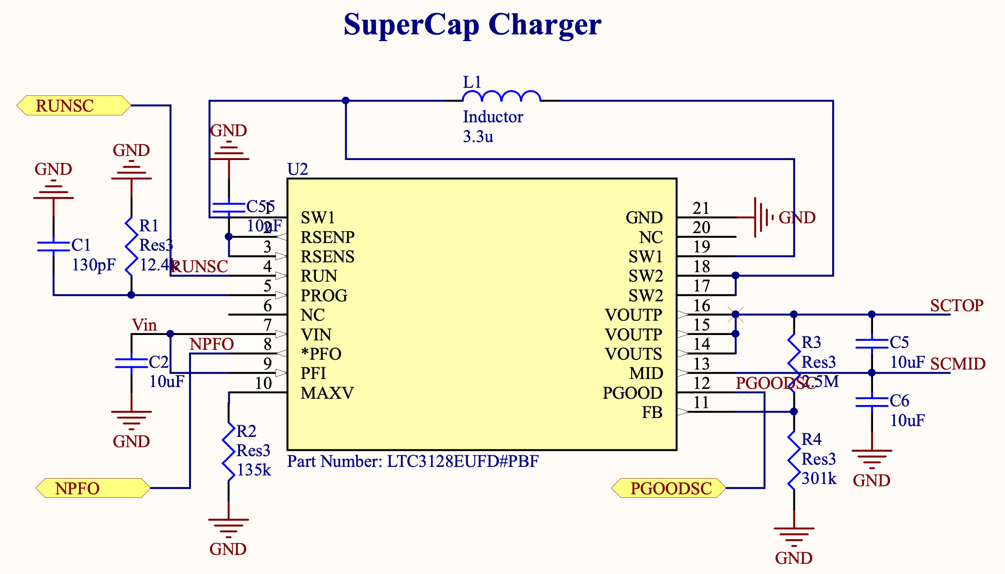
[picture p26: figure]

2.2.3 Validation

The aim of this test is to check the correct functioning of the SCAP charger module. To validate it will be connecting a power supply with 5.4V and connect the SC_TOP output pin to externals resistors put in series and check the current that goes through, to check the current at which is charging the SCAP. It should be around 0.9 A, as it was limited by R1 and C1. With help of a chronometer, and a Multimeter check occasionally how long it takes to charge.

Also, it will be checked the monitoring pins of the charging state with the microcontroller.

2.2.4 Results

ID | Designator | Conditions | Date | Result | Judgement | Comments | Expected Value
3.2.4 | Super Capacitor Charger
3.2.4.1 | Check charging state | Vin = 12 V | 3/3/2021 | | | | 12 V
3.2.4.2 | NCHG Pin State Check | Vnchg = 2V | 3/3/2021 | | | | 0 V
3.2.4.3 | Imax = | 2 | I = 0.50 A | 3/3/2021 | | | | 0.52925 V
3.2.4.4 | Sensitivity = | 0.4405 | I = 1.20 A | 3/3/2021 | | | | 0.8376 V

### 2.3 U3: LTC4006EGN-2#PBF (Li-ion Battery Charger)

2.3.1 Pinout

U3 | 1 | DCIN | External DC Power Input | – – –
| 2 | *CHG | Charge Status Output | Low when the battery is being charged
| 3 | *SHDN | AC Adapter indicator | High if the AC adapter voltage is adequate
| 4 | RT | Timer Resistor | Timer = 1h*RT/154k
| 5 | GND | Ground | – – –
| 6 | NTC | Thermistor network | Indicates if battery temp. is safe
| 7 | ITH | Current Mode PWM Control | Higher ITH volt. -> higher charg. current
| 8 | IMON | Current Monitoring Output | Liniear indication of charg. current
| 9 | CSP | Current Amp. CA1 Input | Supply to be monitored (Input)
| 10 | BAT | Battery Sense Input | Battery pin and shunt resistor
| 11 | CLP | In+ Sup. Curr. Lim. Amp. CL1 | Vout = 0.58*(1+R2/R1)
| 12 | CLN | In- Sup. Curr. Lim. Amp. CL1 | Low when Vout < Voutprog*96.75%
| 13 | TGATE | Drives Top PMOS | For the battery charger buck converter
| 14 | PGND | Ground Return BGATE Driver | Tie to the Vout supercapacitor
| 15 | BGATE | Drives Bottom NMOS | For the battery charger buck converter
| 16 | INFET | Drives Gate Input PFET | For the battery charger buck converter

2.3.2 Description

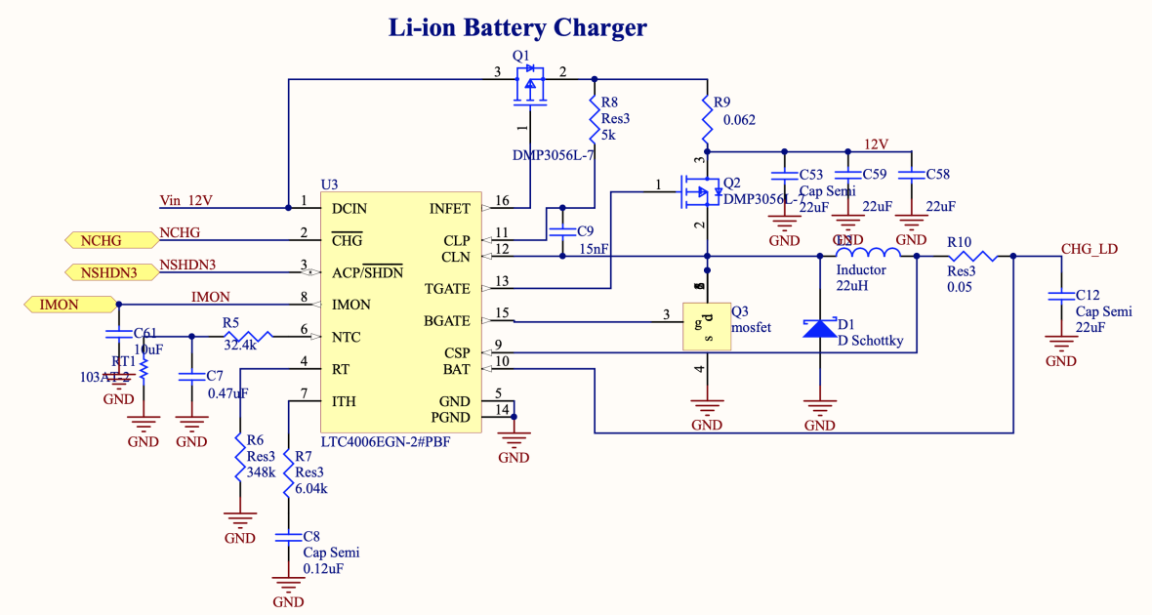
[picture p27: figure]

VIMON =

0,881

IMAX

- I + 0,309 [V] | I =

VIMON−0,309
0,881
- IMAX [A]

2.3.3 Validation

The aim of this test is to check the correct functioning of the battery charger module. The design is implemented for 2A Li-Ion Batteries, as the typical application of the charger datasheet.

Power supply the DCIN pin by 12V and check the charge state of the batteries by measuring their voltage referred to GND and the state of the *CHG pin, high when charging.

Check the current monitoring by measuring the voltage of IMON pin and the voltage drop on the shunt resistor and finally apply the correspondent conversion. And likewise calculate its sensitivity by changing the current.

Check the time of charging and discharging by a help of a chronometer.

2.3.4 Validation

ID | Designator | Conditions | Date | Result | Judgement | Comments | Expected Value
3.3.4 | Battery Charger
3.3.4.1 | Check charging state | Vin = 12 V | 3/3/2021 | | | | 12 V
3.3.4.2 | NCHG Pin State Check | Vnchg = 2V | 3/3/2021 | | | | 0 V
3.3.4.3 | Imax = | 2 | I = 0.50 A | 3/3/2021 | | | | 0.52925 V
3.3.4.4 | Sensitivity = | 0.4405 | I = 1.20 A | 3/3/2021 | | | | 0.8376 V
3.3.4.5 | V_Imon = | 0.4405*I + 0.309 [V] | I = 2.00 A | 3/3/2021 | | | | 1.19 V
3.3.4.6 | Charging time | | I = 0.00 A | 3/3/2021 | | | | 60 s

### 2.4 U4/U6/U9: TPS2121 (Power Multiplexer/Switch)

2.4.1 Pinout

Ux | 1 | OUT | Power Output
| 2 | IN2 | Power Input Source 2
| 3 | CP2 | Enables Comparator Operation
| 4 | OV2 | Enables IN2 Overvoltage Protection
| 5 | OV1 | Enables IN2 Overvoltage Protection
| 6 | PR1 | Enables Priority Operation
| 7 | IN1 | Power Input Source 1
| 8 | OUT | Power Output
| 9 | ST | Status Output
| 10 | ILM | Output Current Limiting
| 11 | SS | Adjusts Input Setting Delay Time and Output Soft Start Time
| 12 | GND | Ground

2.4.2 Description

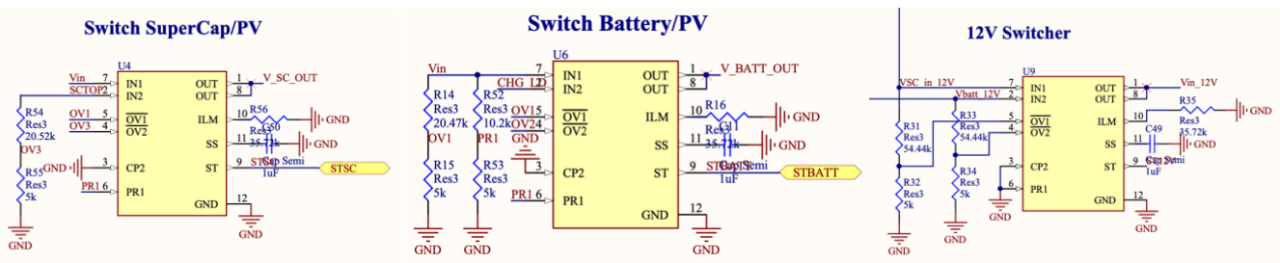
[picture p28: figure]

ILM =

65,2

RILM

0,861 → RILM[kΩ]

2.4.3 Validation

The aim of this test is to measure the time it takes to change paths of this component by applying the corresponding conditions.

Supply both inputs with two different power supplies and force the change of input selection and by a help of an oscilloscope trigger the instant of changing and measure the time and check the ST pin for the output status.

2.4.4 Results

Unable to test operation due to a design problem, see section 3.2 for details.

### 2.5 U5: LTC2944IDD#PBF (Coulomb Counter)

2.5.1 Pinout

U5 | 1 | SENSE+ | Positive Current Sense Input and Power Supply (3,6V – 60V)
| 2 | GND | Ground
| 3 | GND | Ground
| 4 | SCL | Serial Bus Clock I2C Input
| 5 | SDA | Serial Bus Data I2C Input
| 6 | *ALCC | Alert Output and Charge Complete Input
| 7 | GND | Ground
| 8 | SENSE- | Negative Current Sense Input (Negative Side Shunt Resistor) +-50mV
| 9 | GND | Ground

2.5.2 Description

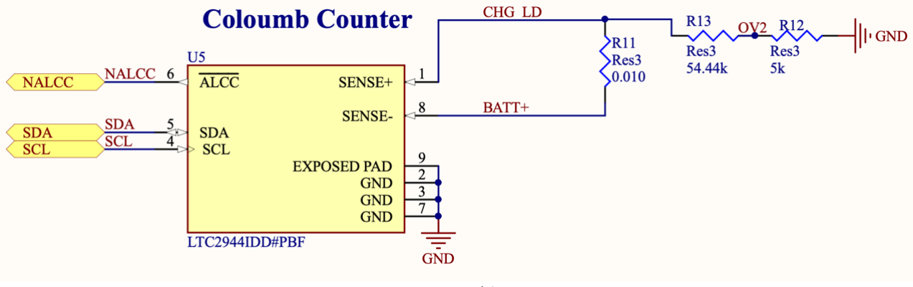
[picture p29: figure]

RSENSE ≤

50mV

IMAX
qLSB = 0,34 mAℎ ·

50mΩ

RSENSE

·

M
4096
M: Prescaler Coulomb Counter | 1mAℎ = 3,6C
If QBAT > IMAX · 22ℎ | → | RSENSE ≤

0,34mAℎ·2

16

QBAT

- 50mΩ

2.5.3 Validation

The aim of this test is to test the I2C bus data. Connect the Li-Ion batteries with a known load and check the voltage drop on the shunt resistor and compare with the I2C bus data by a help of an oscilloscope in decoder mode.

2.5.4 Results

ID | Designator | Conditions | Date | Result | Judgement | Comments | Expected Value
3.5.4 | Coulomb Counter
3.5.4.1 | Voltage Drop | Vbat = 3.2V | 3/3/2021 | | | | 0 V
3.5.4.2 | SDA Current | Iload = 2A | 3/3/2021 | | | | 0 V

### 2.6 U7/U8: TPS2121 (Boost Converter 12V)

2.6.1 Pinout

Ux | 1 | SW | Converter Switch, connected to power inductor
| 2 | VDD | Internal bias supply. If VIN > 3.4V, IC is powered by VIN
| 3 | SS | Soft-Start Programming
| 4 | COMP | Internal Error Amplifier Output
| 5 | FB | Feedback input, connected a resistor divider.
| 6 | AGND | Analog Ground
| 7 | PGND | Power Ground
| 8 | VOUT | Output
| 9 | FTY | Connected to GND
| 10 | MODE | Mode selection. Floating:USM, High:FCCM and Low: PSM
| 11 | EN | Chip Enable Control. For auto start-up, connect to Vin
| 12 | VIN | Input Supply
| 13 | BST | Bootstrap. Cap beetwen BST and SW, power the sync. HS-FET

2.6.2 Description


2.6.3 Validation

The aim of this test is to check that the converters are working appropriately. Connect a power supply with 5.4 V and 2.7V and check the output voltage of the converter is 12V.

2.6.4 Results

ID | Designator | Conditions | Date | Result | Judgement | Comments | Expected Value
3.6.4 | 12V Converter
3.6.4.1 | V_SC | Vin = 5.4 V | 23/3/2021 | 12.14 V | OK | | 12 V
3.6.4.2 | V_SC | Vin = 2.7 V | 23/3/2021 | 11.91 V | OK | | 12 V
3.6.4.3 | V_Batt | Vin = 5.4 V | 23/3/2021 | 12.16 V | OK | | 12 V
3.6.4.4 | V_Batt | Vin = 2.7 V | 23/3/2021 | 11.95 V | OK | | 12 V

### 2.7 U10: LTC3890IUH-2#TRPBF (5V/3V3 Converter)

2.7.1 Pinout

U10

1 | SENSE1- | In- Differential Current Comp.1
2 | FREQ | Freq. Control internal VCO
3 | PHASMD | Control Input to Phase Selector
4 | CLKOUT | Output Clock Signal
5 | PLLIN/MODE | External Synch. Input to Phase Detector and Forced Cont. Mode Input
6 | SGND | Small-signal Ground
7 | RUN1 | Digital Run Control Input Controller 1
8 | RUN2 | Digital Run Control Input Controller 2
9 | SENSE2- | In- Differential Current Comp.2
10 | SENSE2+ | In+ Differential Current Comp.2
11 | VFB2 | Receives the remotely sensed feedback voltage from Controller 2
12 | ITH2 | Error Amplifier Outputs and Switching Regulator Compensation Points
13 | TRACK/SS2 | External Tracking and Soft-Start Input
14 | PGOOD2 | Open-Drain Logic Output. Low when VFB2 < ±10% of its set point.
15 | TG2 | High Current Gate Drives for Top NMOSFET
16 | SW2 | Switch Node Connections to Inductors
17 | BOOST2 | Bootstrapped Supplies to the Topside Floating Drivers
18 | BG2 | High Current Gate Drives for Bottom (Synchronous) NMOSFET
19 | INTVCC | Output of the Internal Linear Low Dropout Regulator
20 | EXTVCC | External Power Input to an Internal LDO Connected to INTVCC
21 | PGND | Driver Power Ground
22 | VIN | Main Supply Pin
23 | BG1 | High Current Gate Drives for Bottom (Synchronous) NMOSFET
24 | BOOST1 | Bootstrapped Supplies to the Topside Floating Drivers
25 | SW1 | Switch Node Connections to Inductors
26 | TG1 | High Current Gate Drives for Top NMOSFET
27 | PGOOD1 | Open-Drain Logic Output. Low when VFB1 < ±10% of its set point.
28 | ILIM | Current Comparator Sense Voltage Range Inputs
29 | TRACK/SS1 | External Tracking and Soft-Start Input
30 | ITH1 | Error Amplifier Outputs and Switching Regulator Compensation Points
31 | VFB1 | Receives the remotely sensed feedback voltage from Controller 1
32 | SENSE1+ | In+ Differential Current Comp.1


2.7.2 Description

2.7.3 Validation

The aim of this test is to check that the converter is working appropriately. Connect a power supply with 5.4 V and 2.7V and check both output voltages of the converter are 5V and 3.3V.

2.7.4 Results

ID | Designator | Conditions | Date | Result | Judgement | Comments | Expected Value
3.7.4 | 5V and 3,3V Converter
3.7.4.1 | V_5V | Vin = 5.4 V | 23/3/2021 | 0.06 V | NOK | | 5 V
3.7.4.2 | V_5V | Vin = 2.7 V | 23/3/2021 | 0 V | NOK | | 5 V
3.7.4.3 | V_3V3 | Vin = 5.4 V | 23/3/2021 | 0.09 V | NOK | | 3.3 V
3.7.4.4 | V_3V3 | Vin = 2.7 V | 23/3/2021 | 0 V | NOK | | 3.3 V

## 3. Issues

### 3.1 Pinout U1: ACHS-7121 (Current Sensor)

The pinout in the design do not corresponds to the datasheet pinout.

U1:Pin5 | VDD
U1:Pin6 | VOUT
U1:Pin7 | FILTER
U1:Pin8 | GND

The correct pinout is as the following figure extracted from the sensor datasheet:

Solution:


Cut the traces and rework the connections with the correct pins.

### 3.2 Pinout U4/U6/U9: TPS2121 (Multiplexer/Switch)


The pinout in the design footprint do not corresponds to the datasheet pinout.


The footprint is flipped horitzontally.

Solution:
???

### 3.3 V_BATT Line

U6-Pin1 [Switch BAT-Out] should be connected to U8-Vin, Q6-Pin5, Q4-Pin5 and U10-Pin22.

U6-Pin1

U8 - Vin
U10 - Pin22
Q4 - Pin5
Q6 - Pin5

The U6-Pin1 corresponds to the output of the switcher that select the supply from PV or the battery, this switch-output feeds the power converters (3.3V, 5V and 12V).

Solution:
Solder a cable between both traces (VBATT_IN and V_BATT_OUT).

### 3.4 V_SC Line

U4-Pin1 [Switch SC-Out] should be connected to U7-Vin.

U4-Pin1 | U7 - Vin

The U4-Pin1 corresponds to the output of the switcher that select the supply from PV or the SuperCapacitor, this switch-output feeds the power converter of 12V.

Solution:
Solder a cable between both traces (VBATT_IN and V_BATT_OUT).

### 3.5 Serial Wire Debugger (SWD) for STM32-MCU

Missing the traces and connector to program the STM32L4 by the SWD pins.

STM32 | STLINK (Programmer)
VDD | 3V3
VSS | GND
PA13 (Pin34) | SWDIO
PA14 (Pin37) | SWCLK

Solution:
Solder wires directly from the STM32 pins to a connector used to plug-in to the STLINK of a NUCLEO board.

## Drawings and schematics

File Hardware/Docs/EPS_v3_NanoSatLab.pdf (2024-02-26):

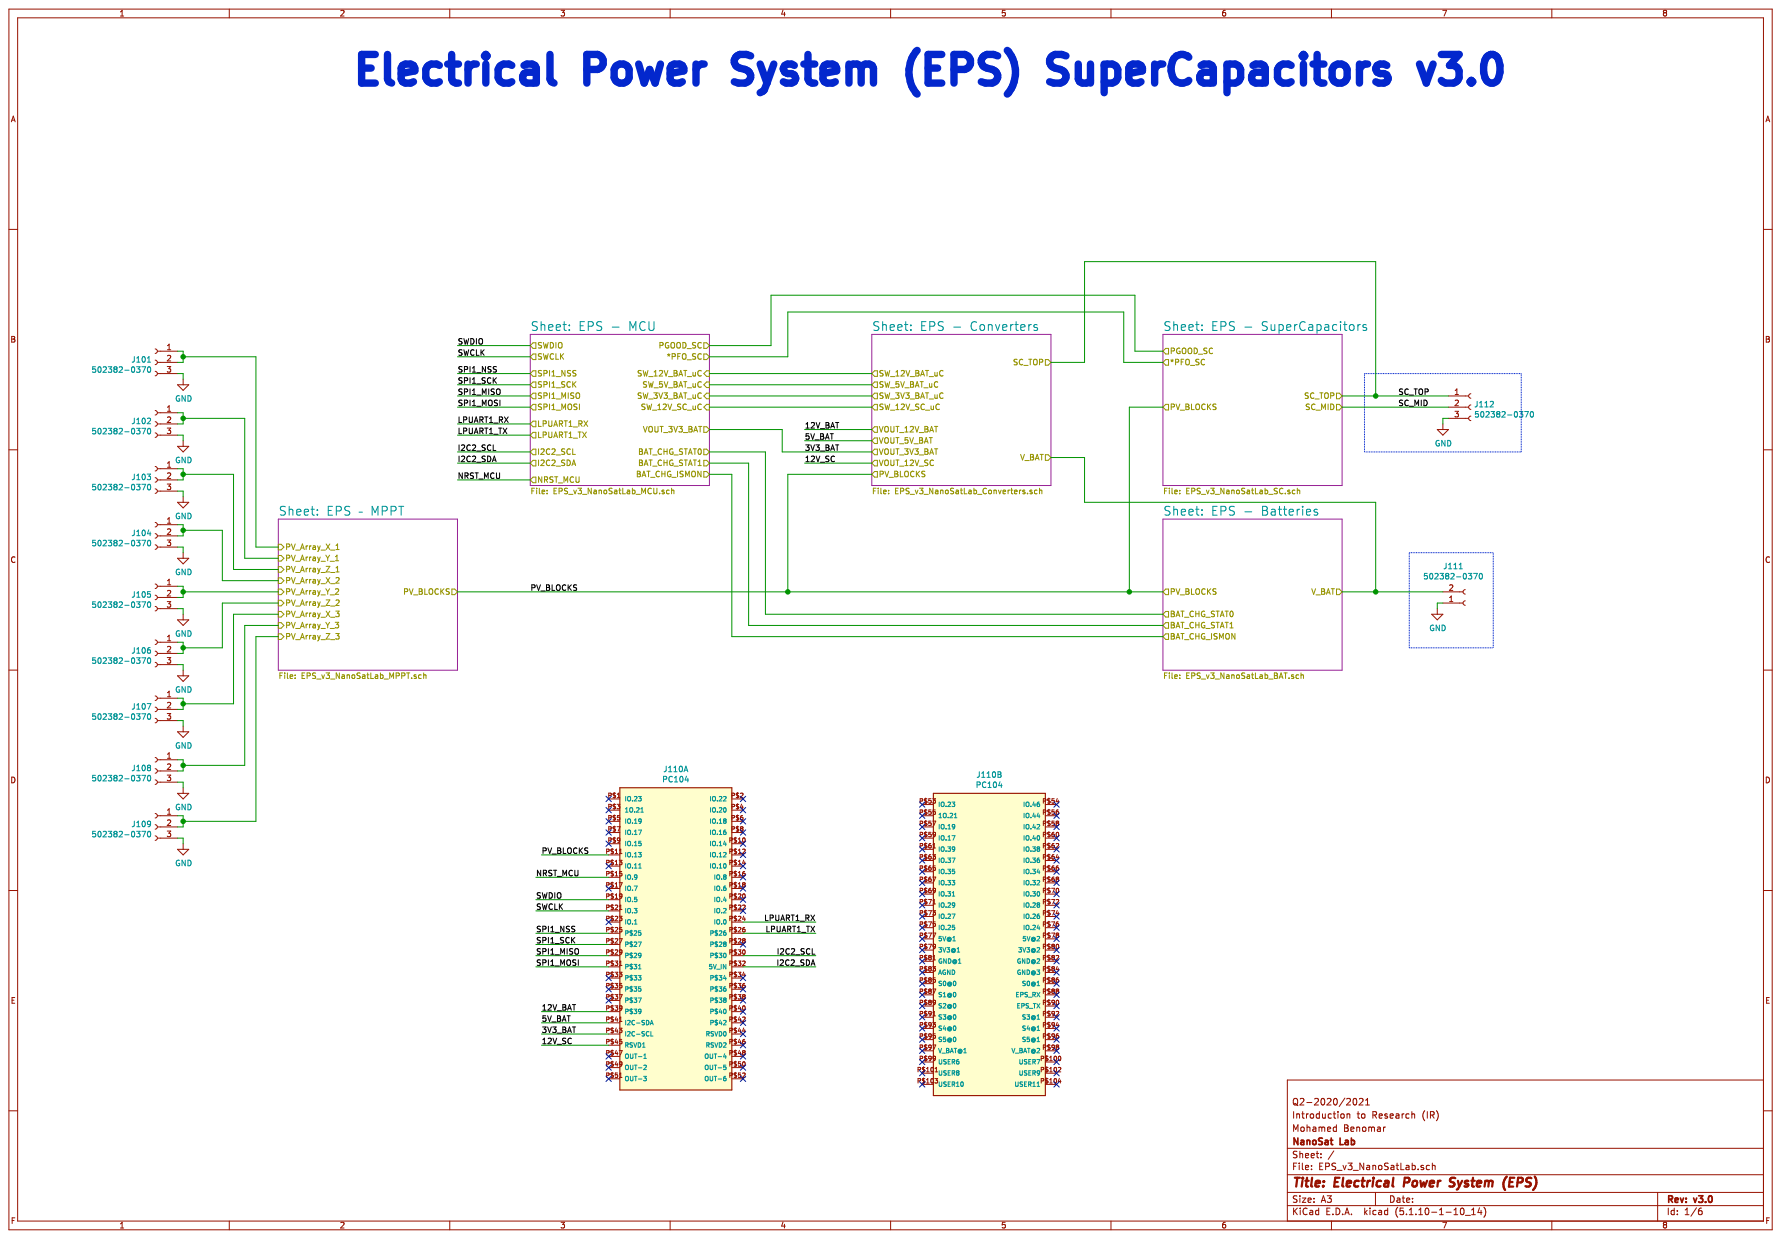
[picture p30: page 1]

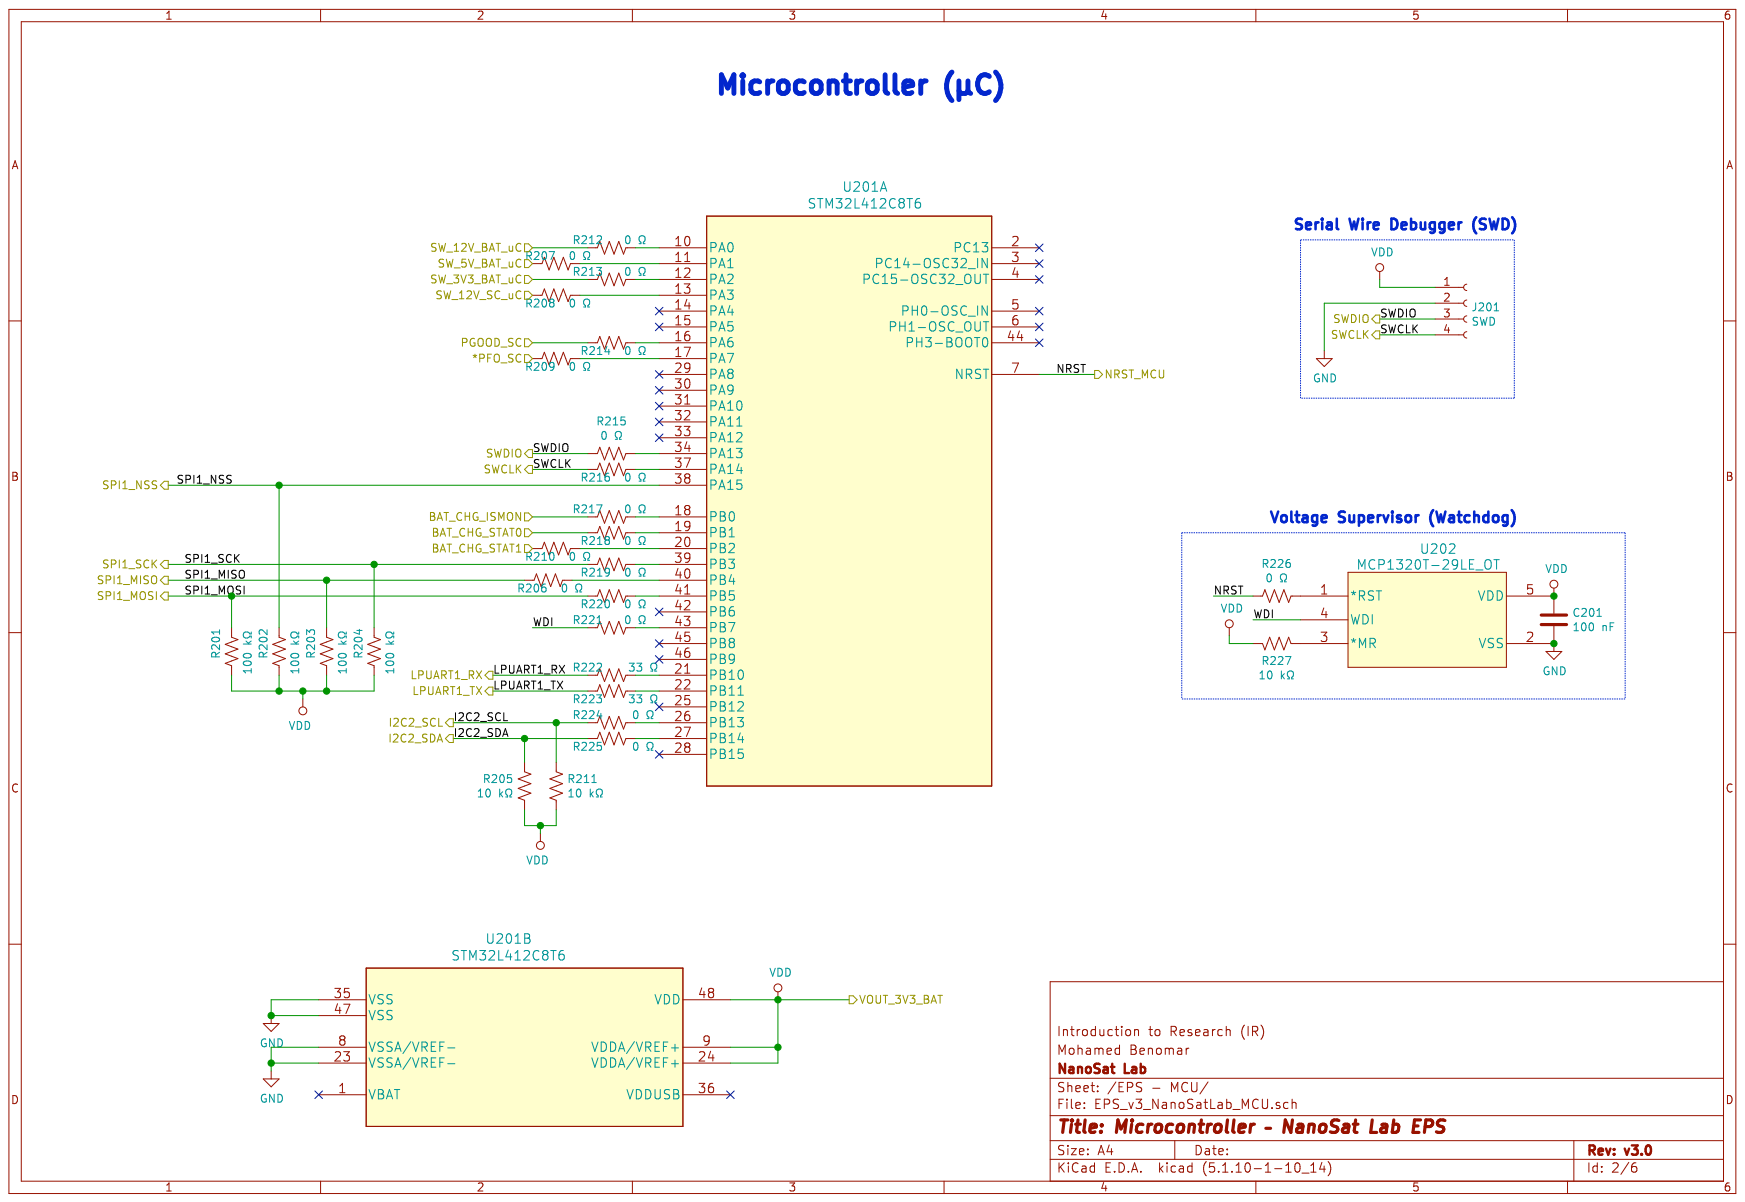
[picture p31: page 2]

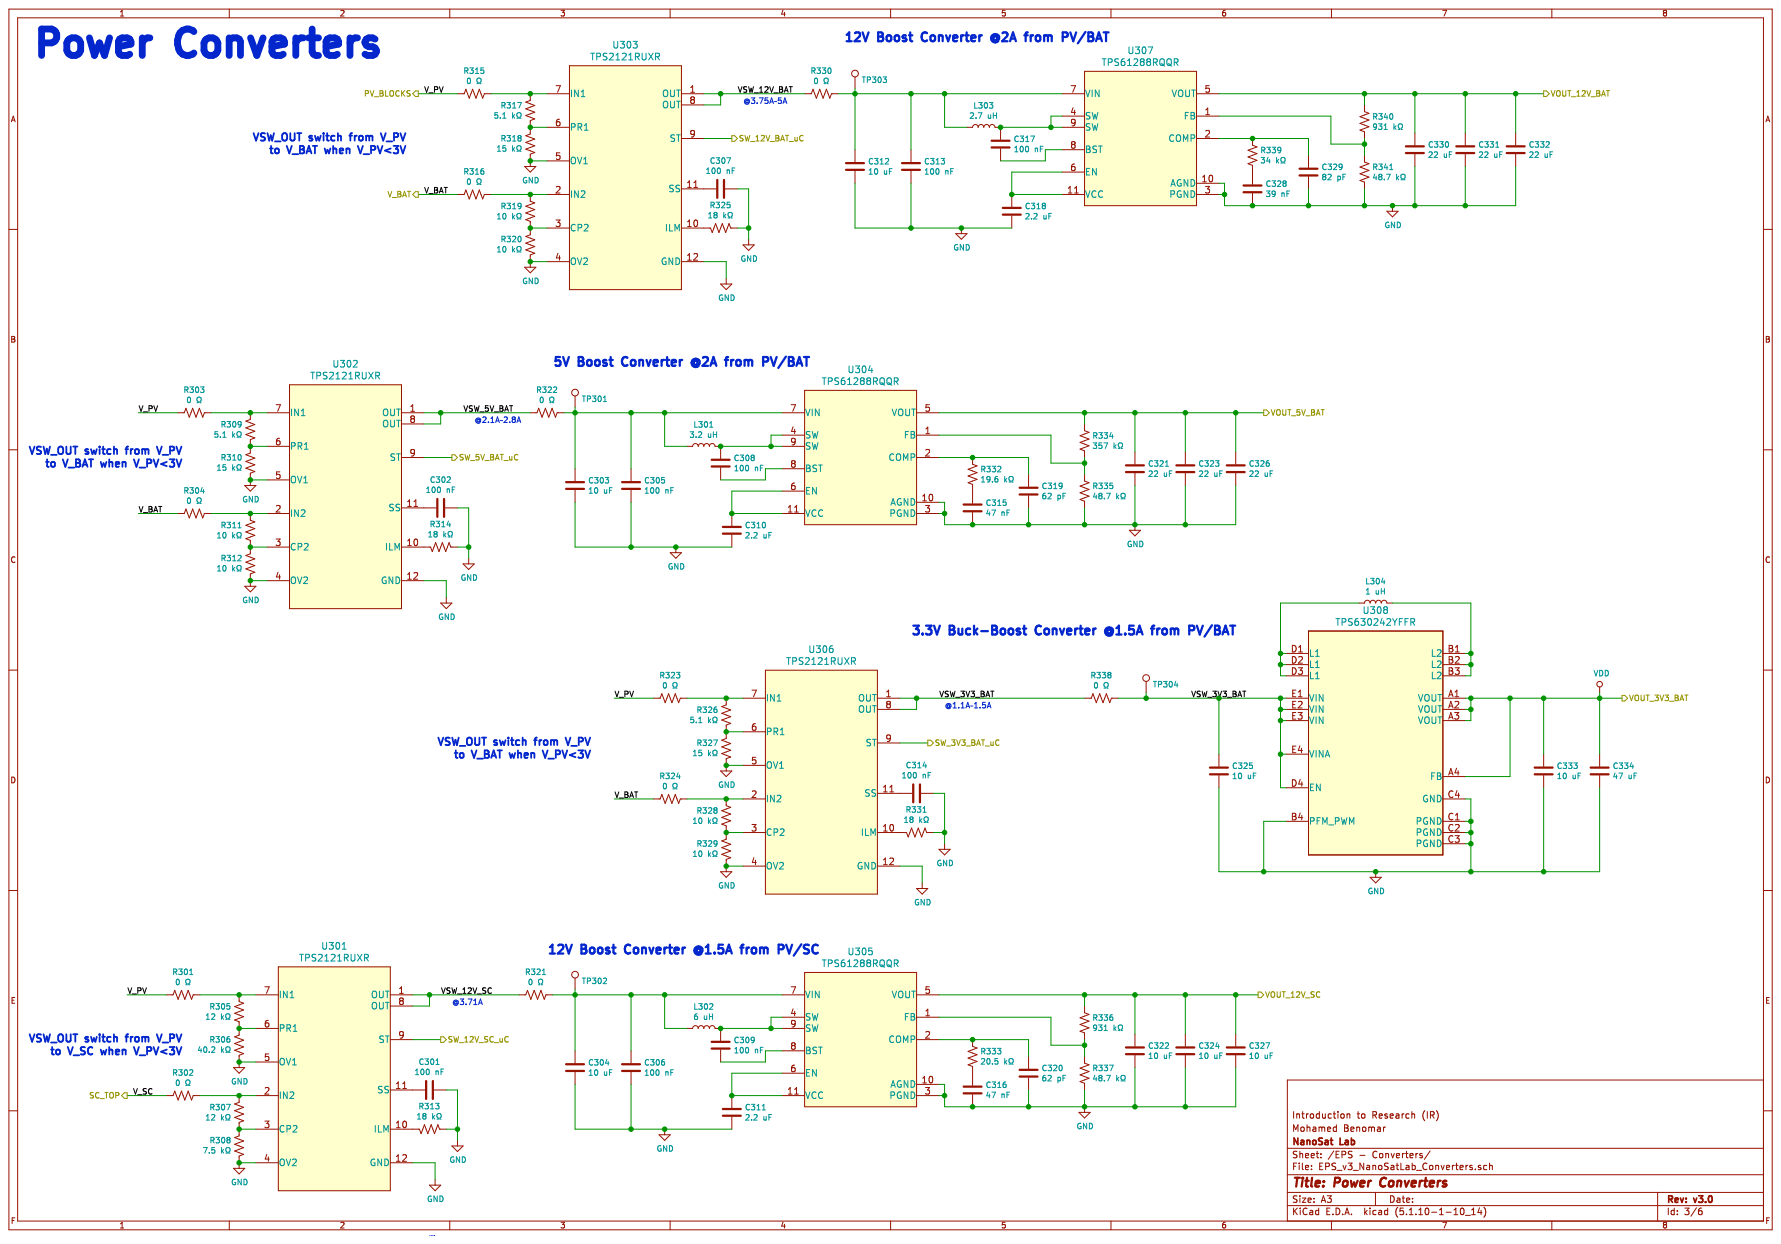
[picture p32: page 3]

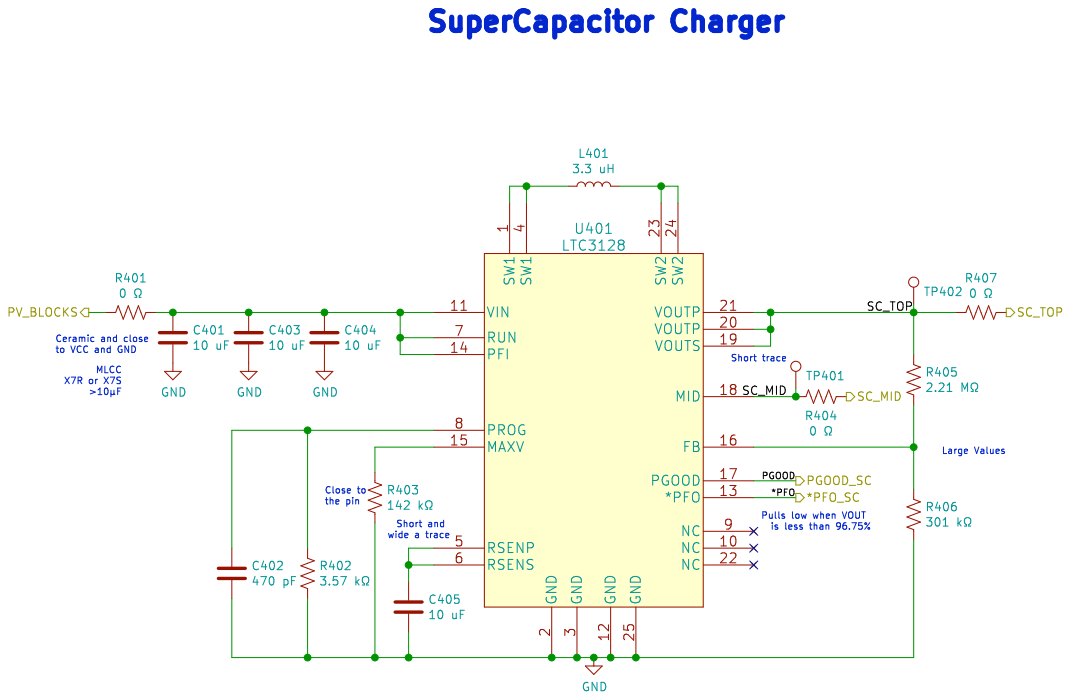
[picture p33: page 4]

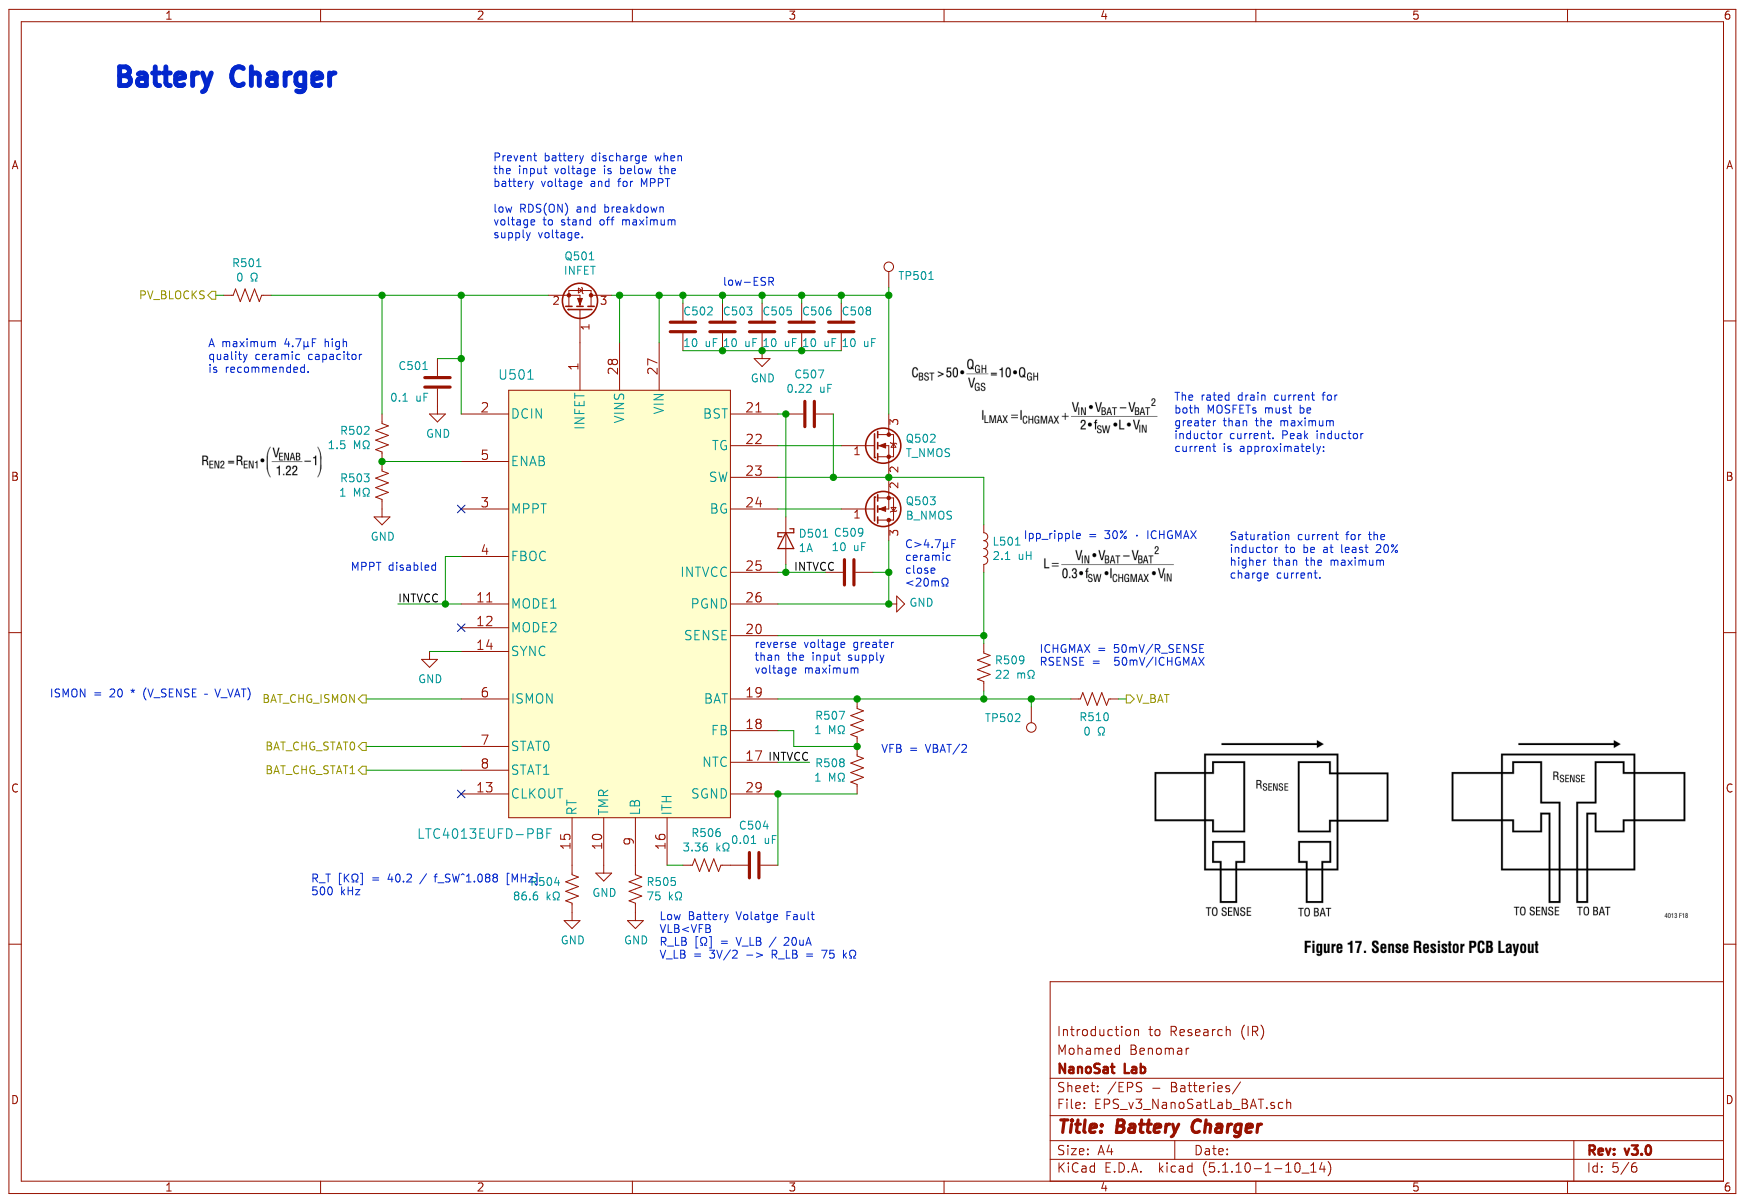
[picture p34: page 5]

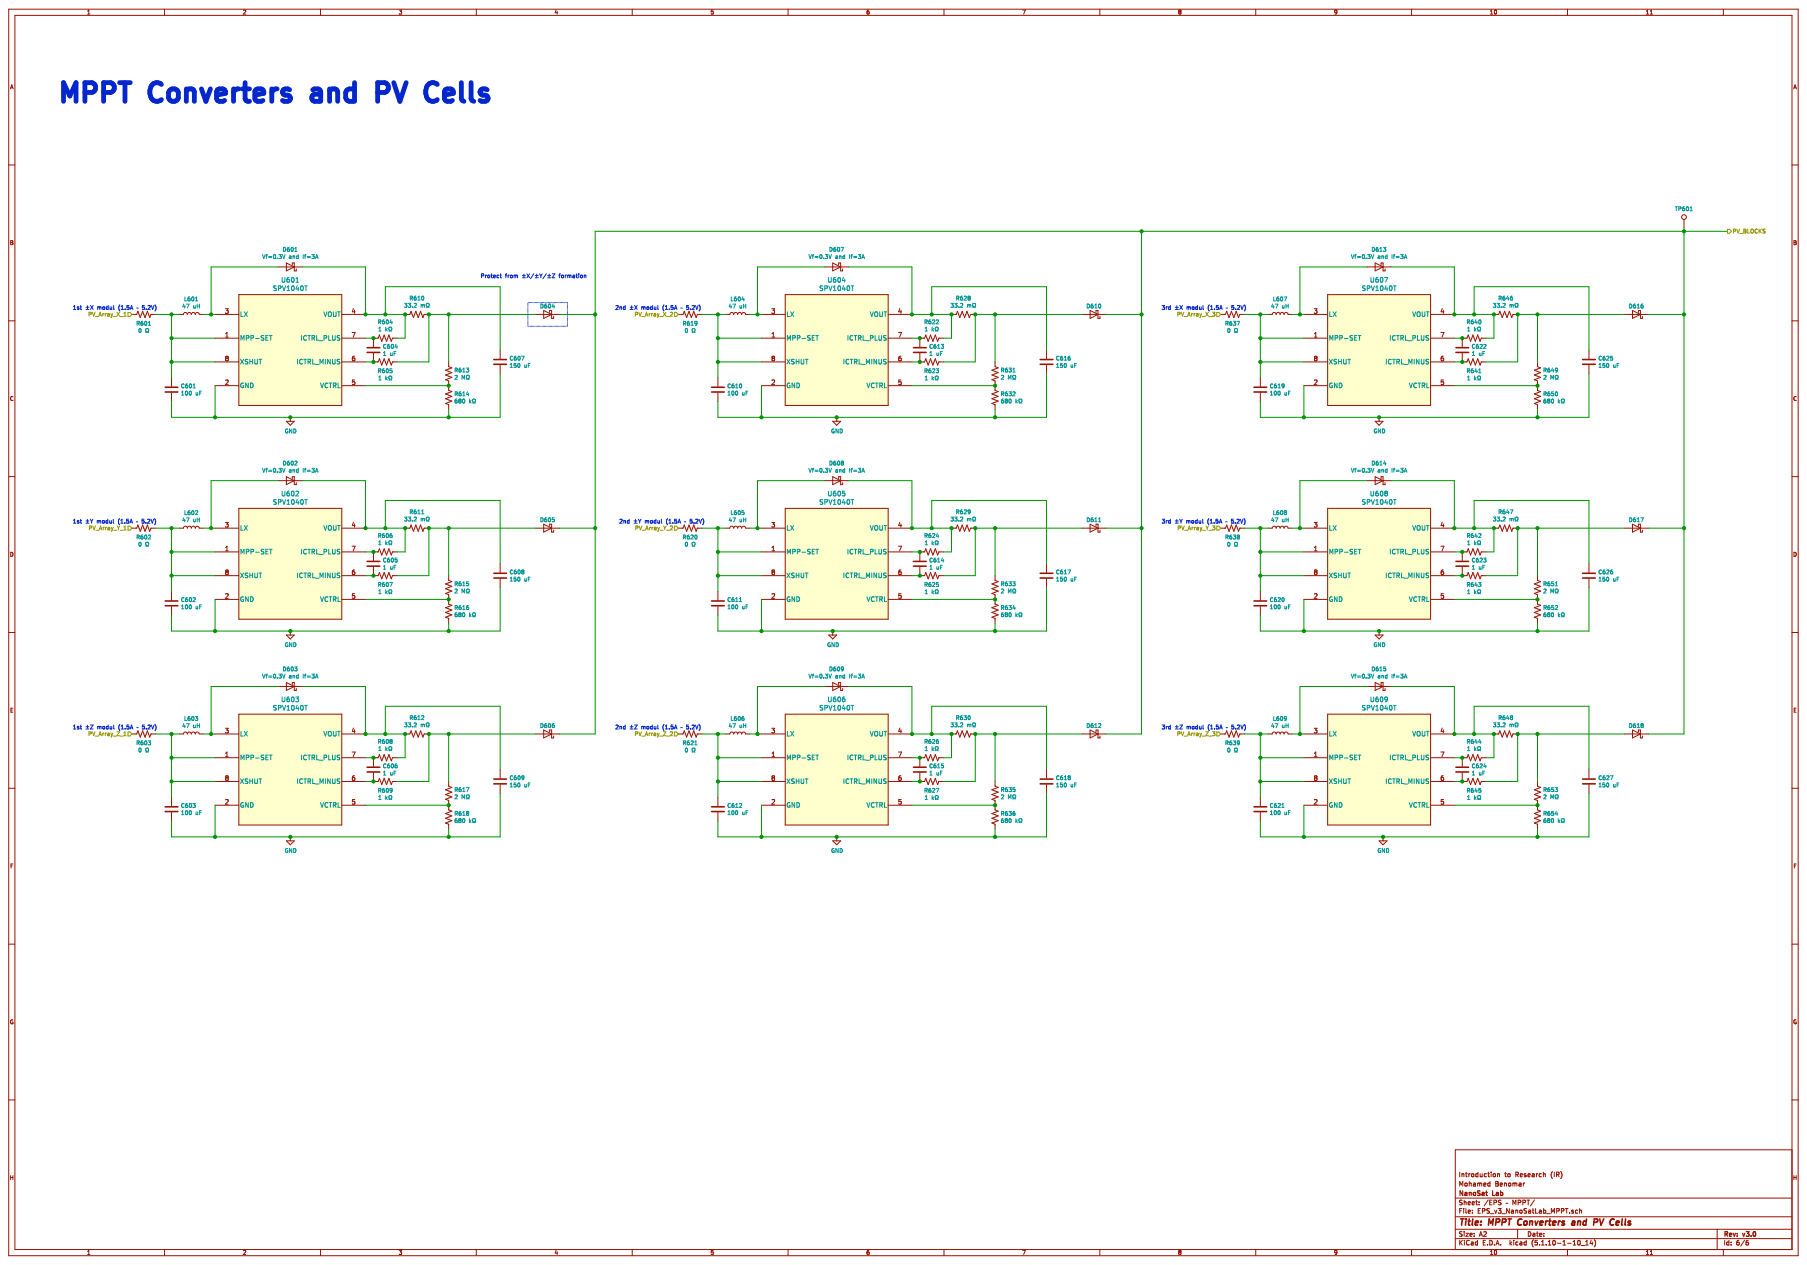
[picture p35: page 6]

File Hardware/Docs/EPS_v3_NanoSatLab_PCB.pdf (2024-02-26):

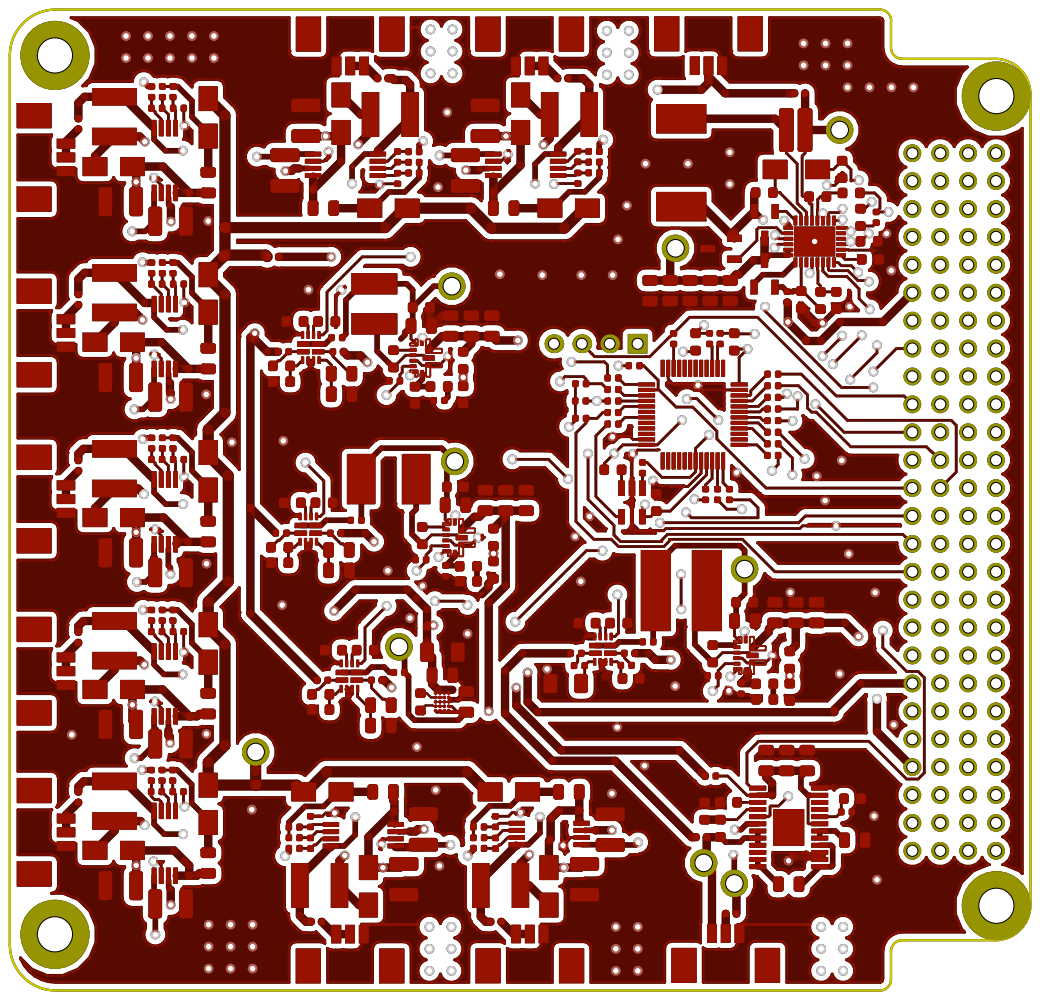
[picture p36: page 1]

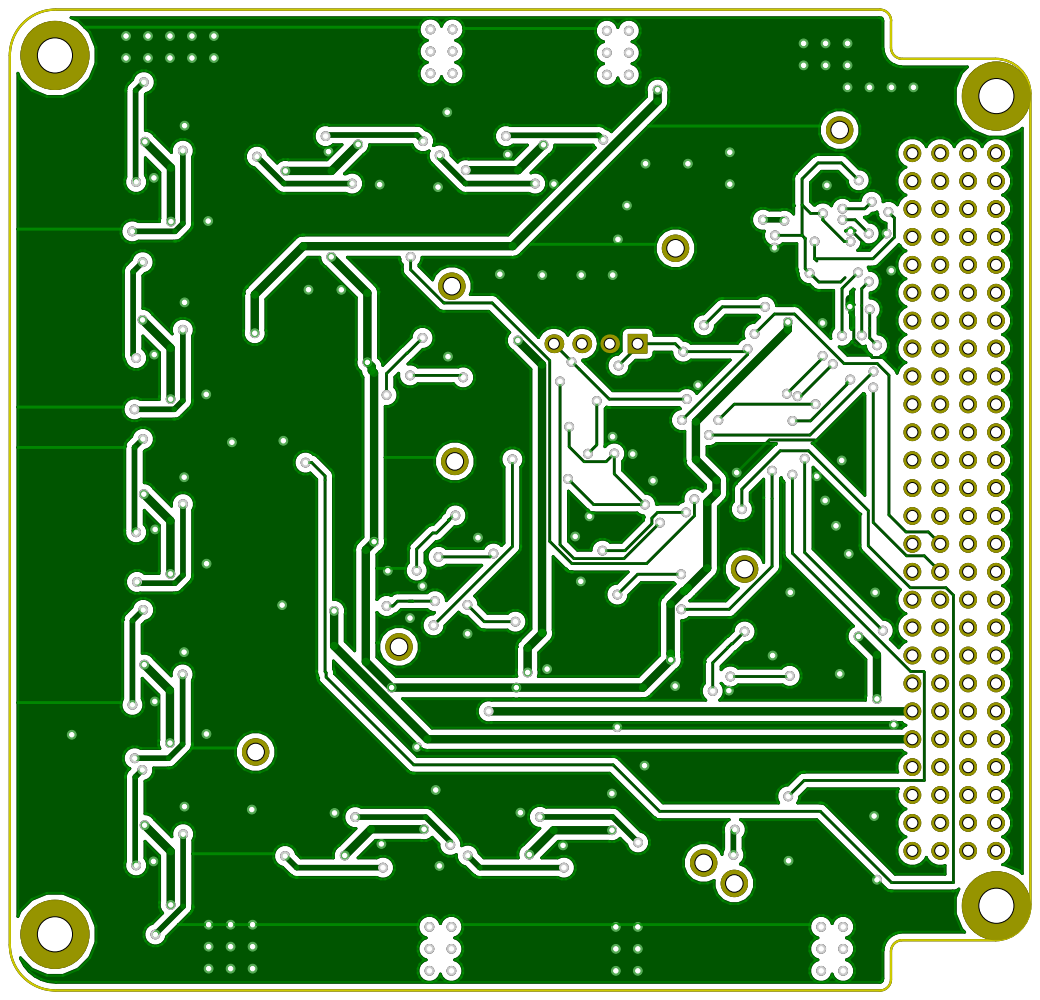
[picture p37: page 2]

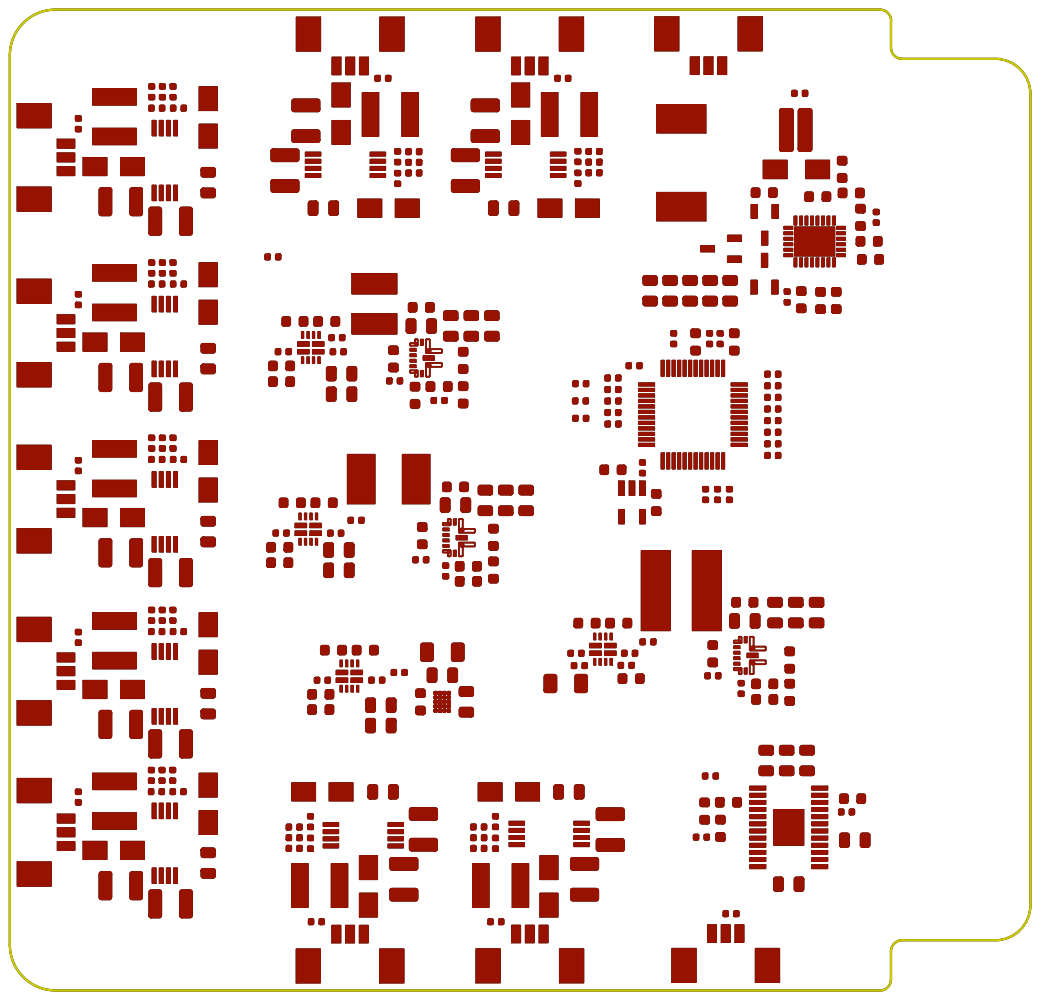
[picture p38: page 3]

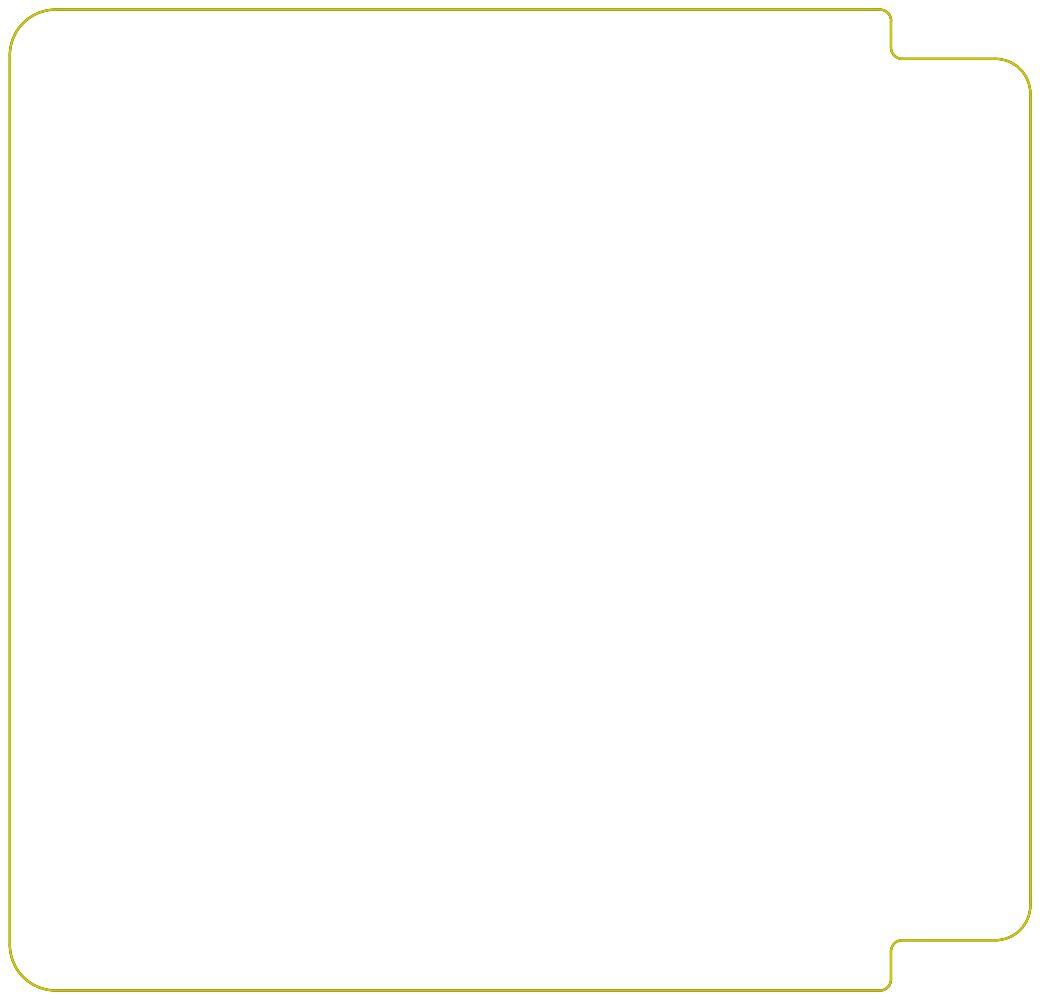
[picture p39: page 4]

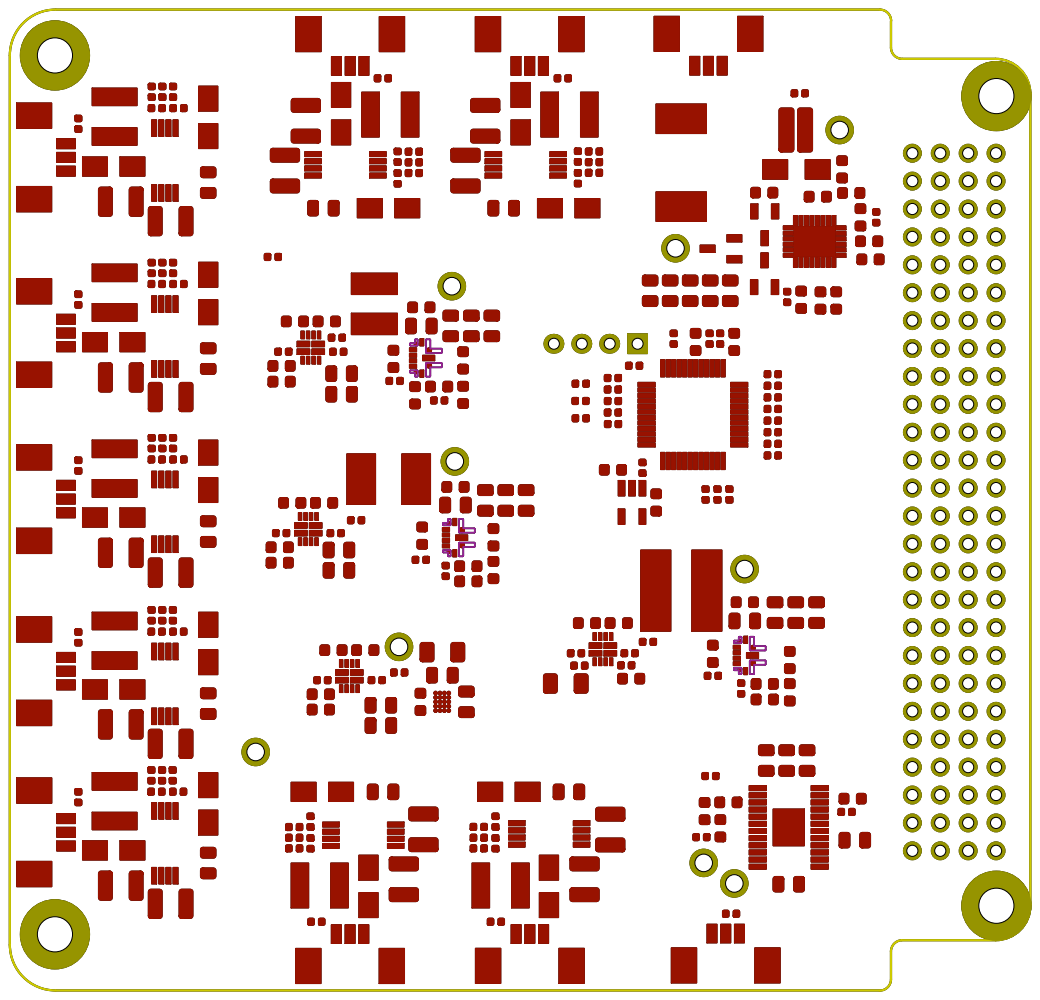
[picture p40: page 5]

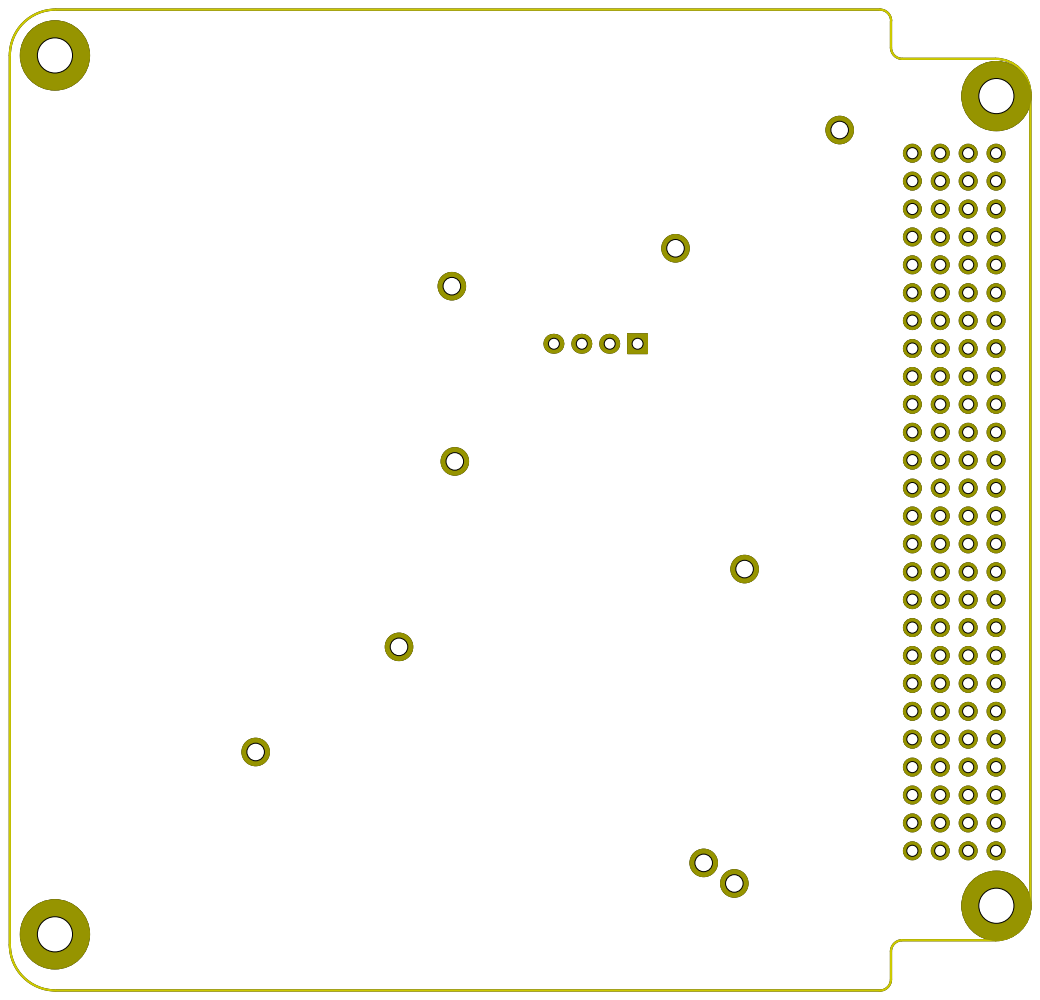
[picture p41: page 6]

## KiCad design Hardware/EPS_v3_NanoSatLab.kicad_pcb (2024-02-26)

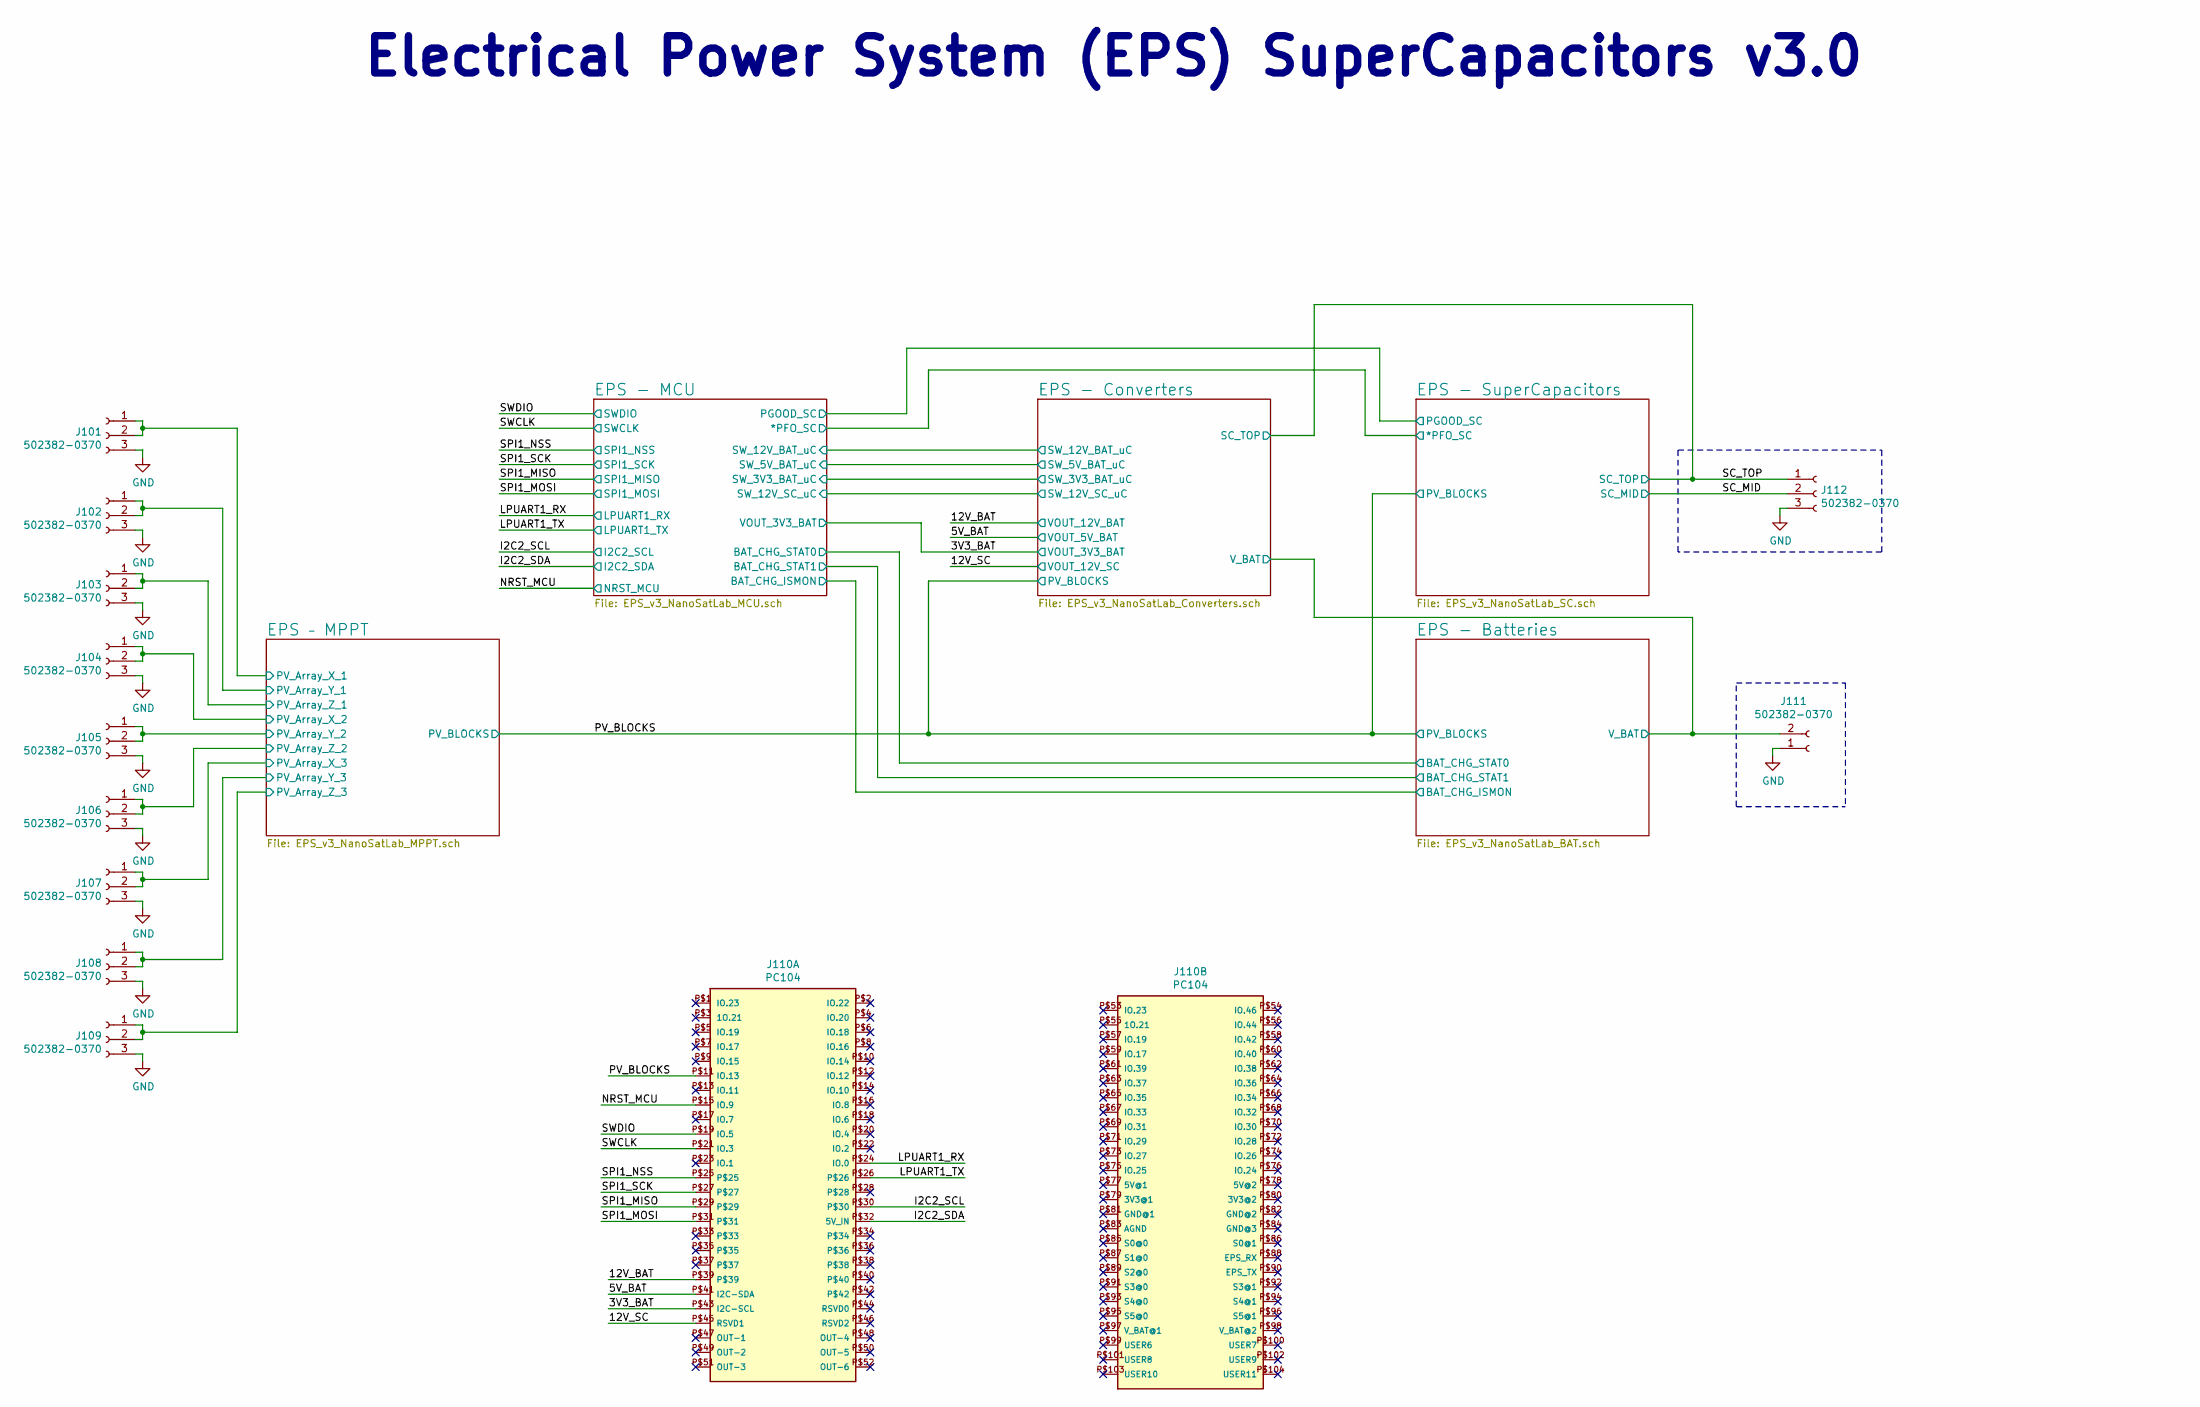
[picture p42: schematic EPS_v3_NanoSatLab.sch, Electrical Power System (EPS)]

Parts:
J101, J102, J103, J104, J105, J106, J107, J108, J109, J111, J112: 502382-0370; MOLEX_502382-0370; LCSC BOM 0
J110: PC104; LCSC Part # - - -

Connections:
/5V_BAT: J110.P$41 (I2C-SDA); also elsewhere on the board
/12V_BAT: J110.P$39; also elsewhere on the board
/12V_SC: J110.P$45 (RSVD1); also elsewhere on the board
/EPS - Batteries/V_BAT: J111.2; also elsewhere on the board
/EPS – MPPT/PV_Array_X_1: J101.1, J101.2; also elsewhere on the board
/EPS – MPPT/PV_Array_X_2: J104.1, J104.2; also elsewhere on the board
/EPS – MPPT/PV_Array_X_3: J107.1, J107.2; also elsewhere on the board
/EPS – MPPT/PV_Array_Y_1: J102.1, J102.2; also elsewhere on the board
/EPS – MPPT/PV_Array_Y_2: J105.1, J105.2; also elsewhere on the board
/EPS – MPPT/PV_Array_Y_3: J108.1, J108.2; also elsewhere on the board
/EPS – MPPT/PV_Array_Z_1: J103.1, J103.2; also elsewhere on the board
/EPS – MPPT/PV_Array_Z_2: J106.1, J106.2; also elsewhere on the board
/EPS – MPPT/PV_Array_Z_3: J109.1, J109.2; also elsewhere on the board
/I2C2_SCL: J110.P$30; also elsewhere on the board
/I2C2_SDA: J110.P$32 (5V_IN); also elsewhere on the board
/LPUART1_RX: J110.P$24 (IO.0); also elsewhere on the board
/LPUART1_TX: J110.P$26; also elsewhere on the board
/NRST_MCU: J110.P$15 (IO.9); also elsewhere on the board
/PV_BLOCKS: J110.P$11 (IO.13); also elsewhere on the board
/SC_MID: J112.2; also elsewhere on the board
/SC_TOP: J112.1; also elsewhere on the board
/SPI1_MISO: J110.P$29; also elsewhere on the board
/SPI1_MOSI: J110.P$31; also elsewhere on the board
/SPI1_NSS: J110.P$25; also elsewhere on the board
/SPI1_SCK: J110.P$27; also elsewhere on the board
/SWCLK: J110.P$21 (IO.3); also elsewhere on the board
/SWDIO: J110.P$19 (IO.5); also elsewhere on the board
GND: J101.3, J102.3, J103.3, J104.3, J105.3, J106.3, J107.3, J108.3, J109.3, J111.1, J112.3; also elsewhere on the board
VDD: J110.P$43 (I2C-SCL); also elsewhere on the board

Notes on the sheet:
Electrical Power System (EPS) SuperCapacitors v3.0

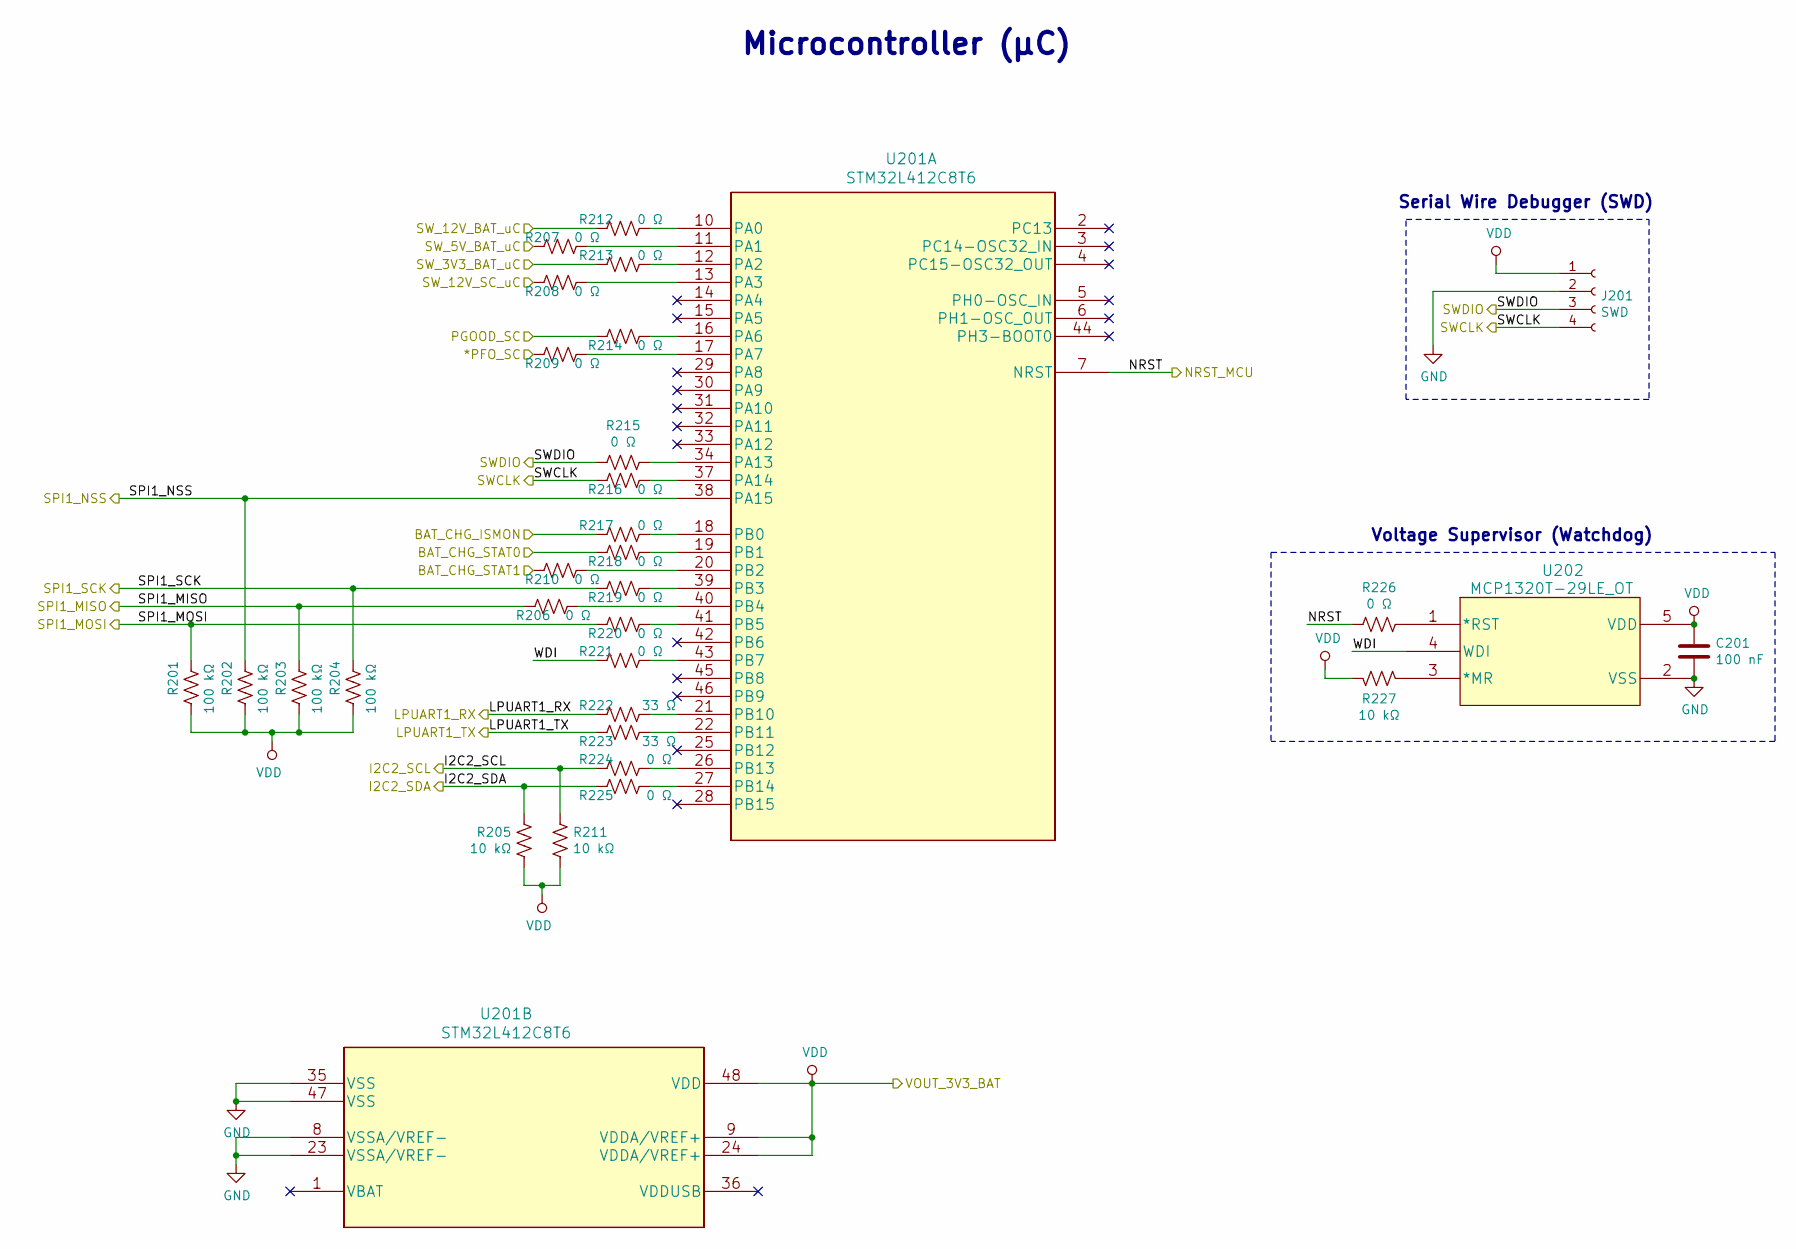
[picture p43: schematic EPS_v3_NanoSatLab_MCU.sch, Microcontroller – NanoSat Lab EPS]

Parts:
C201: 100 nF; C_0603_1608Metric; LCSC Part C14663
J201: SWD; PinHeader_1x04_P2.54mm_Vertical; LCSC BOM 0
R201, R202, R203, R204: 100 kΩ; R_0402_1005Metric; LCSC Part C25741
R205, R211, R227: 10 kΩ; R_0603_1608Metric; LCSC Part C25804
R206, R207, R208, R209, R210, R212, R213, R214, R215, R216, R217, R218, R219, R220, R221, R224, R225, R226: 0 Ω; R_0402_1005Metric; LCSC Part C17168
R222, R223: 33 Ω; R_0402_1005Metric; LCSC Part C25105
U201: STM32L412C8T6; LCSC BOM 0
U202: MCP1320T-29LE_OT; MCP1320T-29LE&slash_OT; LCSC BOM 0

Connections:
/EPS - Batteries/BAT_CHG_ISMON: R217.2; also elsewhere on the board
/EPS - Batteries/BAT_CHG_STAT0: R218.2; also elsewhere on the board
/EPS - Batteries/BAT_CHG_STAT1: R210.2; also elsewhere on the board
/EPS - Converters/SW_3V3_BAT_uC: R213.2; also elsewhere on the board
/EPS - Converters/SW_5V_BAT_uC: R207.2; also elsewhere on the board
/EPS - Converters/SW_12V_BAT_uC: R212.2; also elsewhere on the board
/EPS - Converters/SW_12V_SC_uC: R208.2; also elsewhere on the board
/EPS - MCU/*PFO_SC: R209.2; also elsewhere on the board
/EPS - MCU/PGOOD_SC: R214.2; also elsewhere on the board
/EPS - MCU/WDI: R221.2, U202.4 (WDI)
/I2C2_SCL: R211.1, R224.2; also elsewhere on the board
/I2C2_SDA: R205.1, R225.2; also elsewhere on the board
/LPUART1_RX: R222.2; also elsewhere on the board
/LPUART1_TX: R223.2; also elsewhere on the board
/NRST_MCU: R226.2, U201.7 (NRST); also elsewhere on the board
/SPI1_MISO: R203.1, R206.2; also elsewhere on the board
/SPI1_MOSI: R201.1, R220.2; also elsewhere on the board
/SPI1_NSS: R202.1, U201.38 (PA15); also elsewhere on the board
/SPI1_SCK: R204.1, R219.2; also elsewhere on the board
/SWCLK: J201.4, R216.2; also elsewhere on the board
/SWDIO: J201.3, R215.2; also elsewhere on the board
GND: C201.2, J201.2, U201.8 (VSSA/VREF-), U201.23 (VSSA/VREF-), U201.35 (VSS), U201.47 (VSS), U202.2 (VSS); also elsewhere on the board
unnamed: R206.1, U201.40 (PB4)
unnamed: R207.1, U201.11 (PA1)
unnamed: R208.1, U201.13 (PA3)
unnamed: R209.1, U201.17 (PA7)
unnamed: R210.1, U201.20 (PB2)
unnamed: R212.1, U201.10 (PA0)
unnamed: R213.1, U201.12 (PA2)
unnamed: R214.1, U201.16 (PA6)
unnamed: R215.1, U201.34 (PA13)
unnamed: R216.1, U201.37 (PA14)
unnamed: R217.1, U201.18 (PB0)
unnamed: R218.1, U201.19 (PB1)
unnamed: R219.1, U201.39 (PB3)
unnamed: R220.1, U201.41 (PB5)
unnamed: R221.1, U201.43 (PB7)
unnamed: R222.1, U201.21 (PB10)
unnamed: R223.1, U201.22 (PB11)
unnamed: R224.1, U201.26 (PB13)
unnamed: R225.1, U201.27 (PB14)
unnamed: R226.1, U202.1 (*RST)
unnamed: R227.1, U202.3 (*MR)
VDD: C201.1, J201.1, R201.2, R202.2, R203.2, R204.2, R205.2, R211.2, R227.2, U201.9 (VDDA/VREF+), U201.24 (VDDA/VREF+), U201.48 (VDD), U202.5 (VDD); also elsewhere on the board

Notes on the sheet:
Voltage Supervisor (Watchdog)
Serial Wire Debugger (SWD)
Microcontroller (µC)

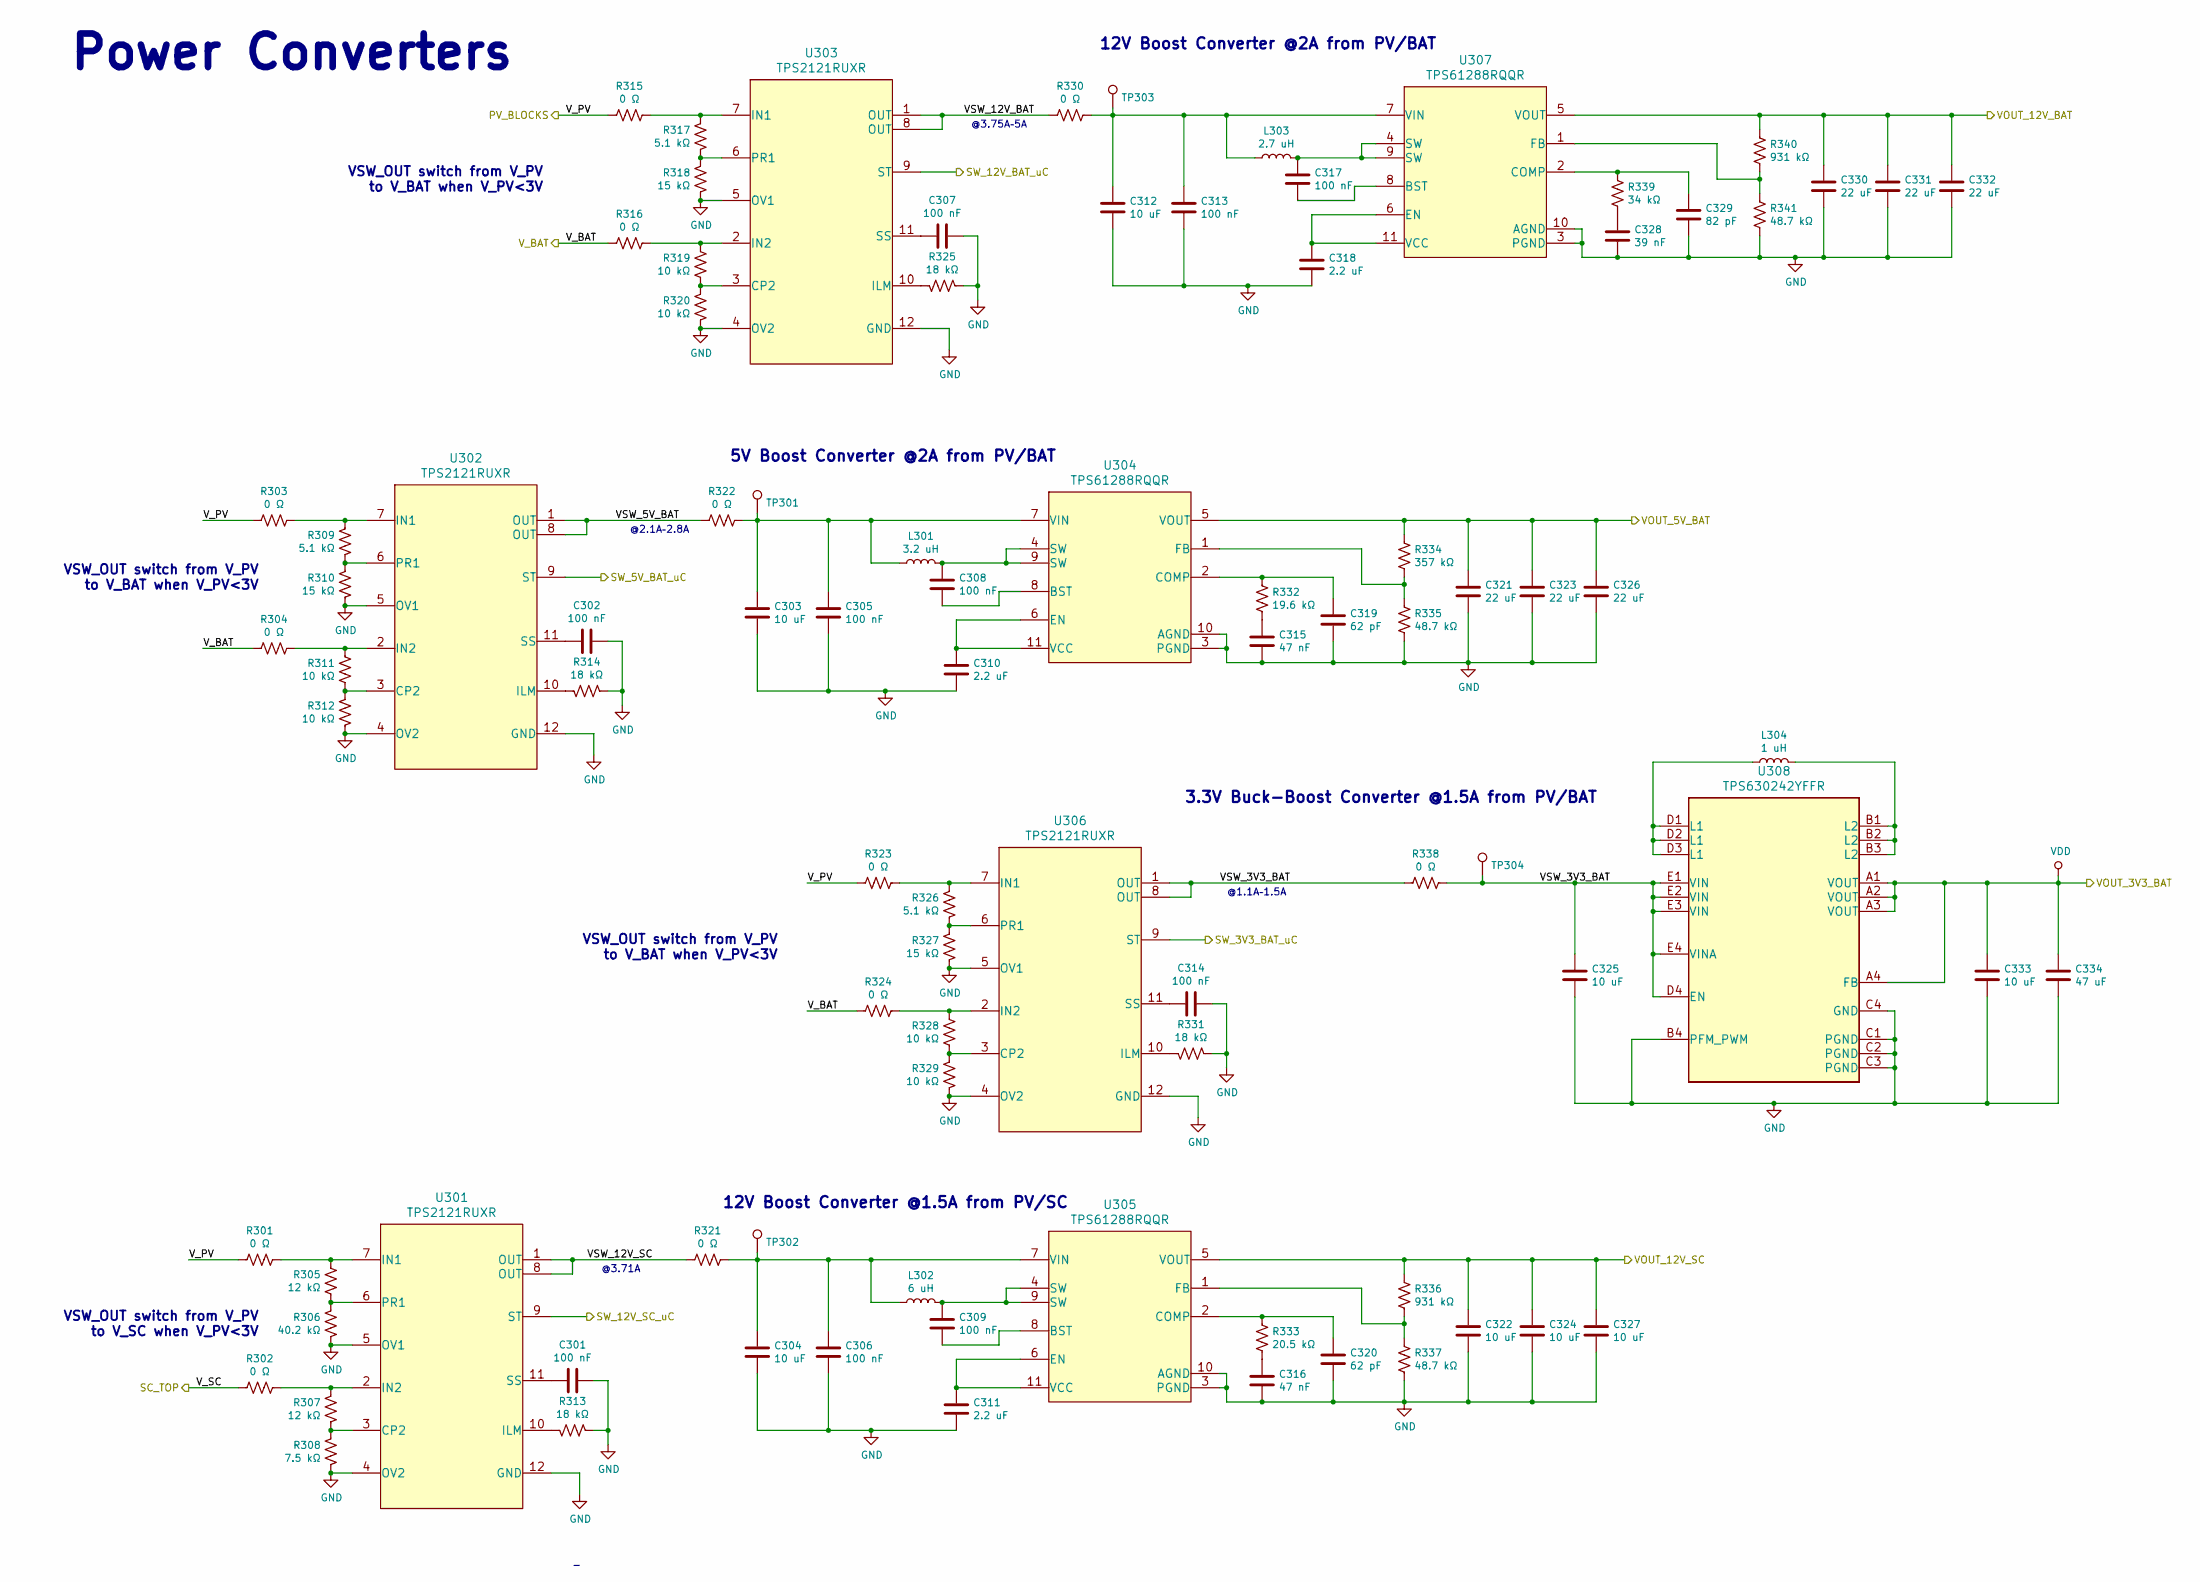
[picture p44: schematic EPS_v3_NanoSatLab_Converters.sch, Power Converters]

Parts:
C301, C302, C305, C306, C307, C308, C309, C313, C314, C317: 100 nF; C_0603_1608Metric; LCSC Part C14663
C303, C304, C312, C322, C324, C325, C327, C333: 10 uF; C_0805_2012Metric; LCSC Part C15850
C310, C311, C318: 2.2 uF; C_0603_1608Metric; LCSC Part C23630
C315, C316: 47 nF; C_0603_1608Metric; LCSC Part C1622
C319, C320: 62 pF; C_0402_1005Metric; LCSC BOM 0
C321, C323, C326, C330, C331, C332: 22 uF; C_0805_2012Metric; LCSC Part C45783
C328: 39 nF; C_0402_1005Metric; LCSC BOM 0
C329: 82 pF; C_0603_1608Metric; LCSC Part C1683
C334: 47 uF; C_1206_3216Metric; LCSC Part C96123
L301: 3.2 uH; IND_FP3-3R3-R; LCSC BOM 0
L302: 6 uH; PM628S-100; LCSC BOM 0
L303: 2.7 uH; IND_LQH5BPN2R7NT0L; LCSC BOM 0
L304: 1 uH; L_0603_1608Metric; LCSC BOM 0
R301, R302, R303, R304, R315, R316, R321, R322, R323, R324, R330, R338: 0 Ω; R_0603_1608Metric; LCSC Part C21189
R305, R307: 12 kΩ; R_0402_1005Metric; LCSC Part C25752
R306: 40.2 kΩ; R_0603_1608Metric; LCSC Part C12447
R308: 7.5 kΩ; R_0805_2012Metric; LCSC Part C17807
R309, R317, R326: 5.1 kΩ; R_0805_2012Metric; LCSC Part C27834
R310, R318, R327: 15 kΩ; R_0805_2012Metric; LCSC Part C17475
R311, R312, R319, R320, R328, R329: 10 kΩ; R_0603_1608Metric; LCSC Part C25804
R313, R314, R325, R331: 18 kΩ; R_0603_1608Metric; LCSC Part C25810
R332: 19.6 kΩ; R_0603_1608Metric; LCSC BOM 0
R333: 20.5 kΩ; R_0603_1608Metric; LCSC BOM 0
R334: 357 kΩ; R_0603_1608Metric; LCSC BOM 0
R335, R337, R341: 48.7 kΩ; R_0603_1608Metric; LCSC BOM 0
R336, R340: 931 kΩ; R_0603_1608Metric; LCSC BOM 0
R339: 34 kΩ; R_0603_1608Metric; LCSC BOM 0
TP301, TP302, TP303, TP304: TestPoint; TESTPOINT_5013; LCSC BOM 0
U301, U302, U303, U306: TPS2121RUXR; LCSC BOM 0
U304, U305, U307: TPS61288RQQR; LCSC BOM 0
U308: TPS630242YFFR; LCSC BOM 0

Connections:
/5V_BAT: C321.1, C323.1, C326.1, R334.1, U304.5 (VOUT); also elsewhere on the board
/12V_BAT: C330.1, C331.1, C332.1, R340.1, U307.5 (VOUT); also elsewhere on the board
/12V_SC: C322.1, C324.1, C327.1, R336.1, U305.5 (VOUT); also elsewhere on the board
/EPS - Batteries/V_BAT: R304.2, R316.2, R324.2; also elsewhere on the board
/EPS - Converters/SW_3V3_BAT_uC: U306.9 (ST); also elsewhere on the board
/EPS - Converters/SW_5V_BAT_uC: U302.9 (ST); also elsewhere on the board
/EPS - Converters/SW_12V_BAT_uC: U303.9 (ST); also elsewhere on the board
/EPS - Converters/SW_12V_SC_uC: U301.9 (ST); also elsewhere on the board
/EPS - Converters/VSW_3V3_BAT: C325.1, R338.1, R338.2, TP304.1, U306.1 (OUT), U306.8 (OUT), U308.D4 (EN), U308.E1 (VIN), U308.E2 (VIN), U308.E3 (VIN), U308.E4 (VINA)
/EPS - Converters/VSW_5V_BAT: R322.2, U302.1 (OUT), U302.8 (OUT)
/EPS - Converters/VSW_12V_BAT: R330.2, U303.1 (OUT), U303.8 (OUT)
/EPS - Converters/VSW_12V_SC: R321.2, U301.1 (OUT), U301.8 (OUT)
/PV_BLOCKS: R301.2, R303.2, R315.2, R323.2; also elsewhere on the board
/SC_TOP: R302.2; also elsewhere on the board
GND: C301.1, C302.1, C303.2, C304.2, C305.2, C306.2, C307.1, C310.2, C311.2, C312.2, C313.2, C314.1, C315.2, C316.2, C318.2, C319.2, C320.2, C321.2, C322.2, C323.2, C324.2, C325.2, C326.2, C327.2, C328.2, C329.2, C330.2, C331.2, C332.2, C333.2, C334.2, R306.1, R308.1, R310.1, R312.1, R313.2, R314.2, R318.1, R320.1, R325.2, R327.1, R329.1, R331.2, R335.2, R337.2, R341.2, U301.4 (OV2), U301.5 (OV1), U301.12 (GND), U302.4 (OV2), U302.5 (OV1), U302.12 (GND), U303.4 (OV2), U303.5 (OV1), U303.12 (GND), U304.3 (PGND), U304.10 (AGND), U305.3 (PGND), U305.10 (AGND), U306.4 (OV2), U306.5 (OV1), U306.12 (GND), U307.3 (PGND), U307.10 (AGND), U308.B4 (PFM_PWM), U308.C1 (PGND), U308.C2 (PGND), U308.C3 (PGND), U308.C4 (GND); also elsewhere on the board
unnamed: C301.2, U301.11 (SS)
unnamed: C302.2, U302.11 (SS)
unnamed: C303.1, C305.1, L301.1, R322.1, TP301.1, U304.7 (VIN)
unnamed: C304.1, C306.1, L302.1, R321.1, TP302.1, U305.7 (VIN)
unnamed: C307.2, U303.11 (SS)
unnamed: C308.1, L301.2, U304.4 (SW), U304.9 (SW)
unnamed: C308.2, U304.8 (BST)
unnamed: C309.1, L302.2, U305.4 (SW), U305.9 (SW)
unnamed: C309.2, U305.8 (BST)
unnamed: C310.1, U304.6 (EN), U304.11 (VCC)
unnamed: C311.1, U305.6 (EN), U305.11 (VCC)
unnamed: C312.1, C313.1, L303.1, R330.1, TP303.1, U307.7 (VIN)
unnamed: C314.2, U306.11 (SS)
unnamed: C315.1, R332.2
unnamed: C316.1, R333.2
unnamed: C317.1, L303.2, U307.4 (SW), U307.9 (SW)
unnamed: C317.2, U307.8 (BST)
unnamed: C318.1, U307.6 (EN), U307.11 (VCC)
unnamed: C319.1, R332.1, U304.2 (COMP)
unnamed: C320.1, R333.1, U305.2 (COMP)
unnamed: C328.1, R339.2
unnamed: C329.1, R339.1, U307.2 (COMP)
unnamed: L304.1, U308.D1 (L1), U308.D2 (L1), U308.D3 (L1)
unnamed: L304.2, U308.B1 (L2), U308.B2 (L2), U308.B3 (L2)
unnamed: R301.1, R305.1, U301.7 (IN1)
unnamed: R302.1, R307.1, U301.2 (IN2)
unnamed: R303.1, R309.1, U302.7 (IN1)
unnamed: R304.1, R311.1, U302.2 (IN2)
unnamed: R305.2, R306.2, U301.6 (PR1)
unnamed: R307.2, R308.2, U301.3 (CP2)
unnamed: R309.2, R310.2, U302.6 (PR1)
unnamed: R311.2, R312.2, U302.3 (CP2)
unnamed: R313.1, U301.10 (ILM)
unnamed: R314.1, U302.10 (ILM)
unnamed: R315.1, R317.1, U303.7 (IN1)
unnamed: R316.1, R319.1, U303.2 (IN2)
unnamed: R317.2, R318.2, U303.6 (PR1)
unnamed: R319.2, R320.2, U303.3 (CP2)
unnamed: R323.1, R326.1, U306.7 (IN1)
unnamed: R324.1, R328.1, U306.2 (IN2)
unnamed: R325.1, U303.10 (ILM)
unnamed: R326.2, R327.2, U306.6 (PR1)
unnamed: R328.2, R329.2, U306.3 (CP2)
unnamed: R331.1, U306.10 (ILM)
unnamed: R334.2, R335.1, U304.1 (FB)
unnamed: R336.2, R337.1, U305.1 (FB)
unnamed: R340.2, R341.1, U307.1 (FB)
VDD: C333.1, C334.1, U308.A1 (VOUT), U308.A2 (VOUT), U308.A3 (VOUT), U308.A4 (FB); also elsewhere on the board

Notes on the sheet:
12V Boost Converter @2A from PV/BAT
5V Boost Converter @2A from PV/BAT
3.3V Buck-Boost Converter @1.5A from PV/BAT
12V Boost Converter @1.5A from PV/SC
@3.75A–5A
@2.1A–2.8A
@1.1A–1.5A
@3.71A
VSW_OUT switch from V_PV to V_BAT when V_PV<3V
VSW_OUT switch from V_PV to V_SC when V_PV<3V
Power Converters

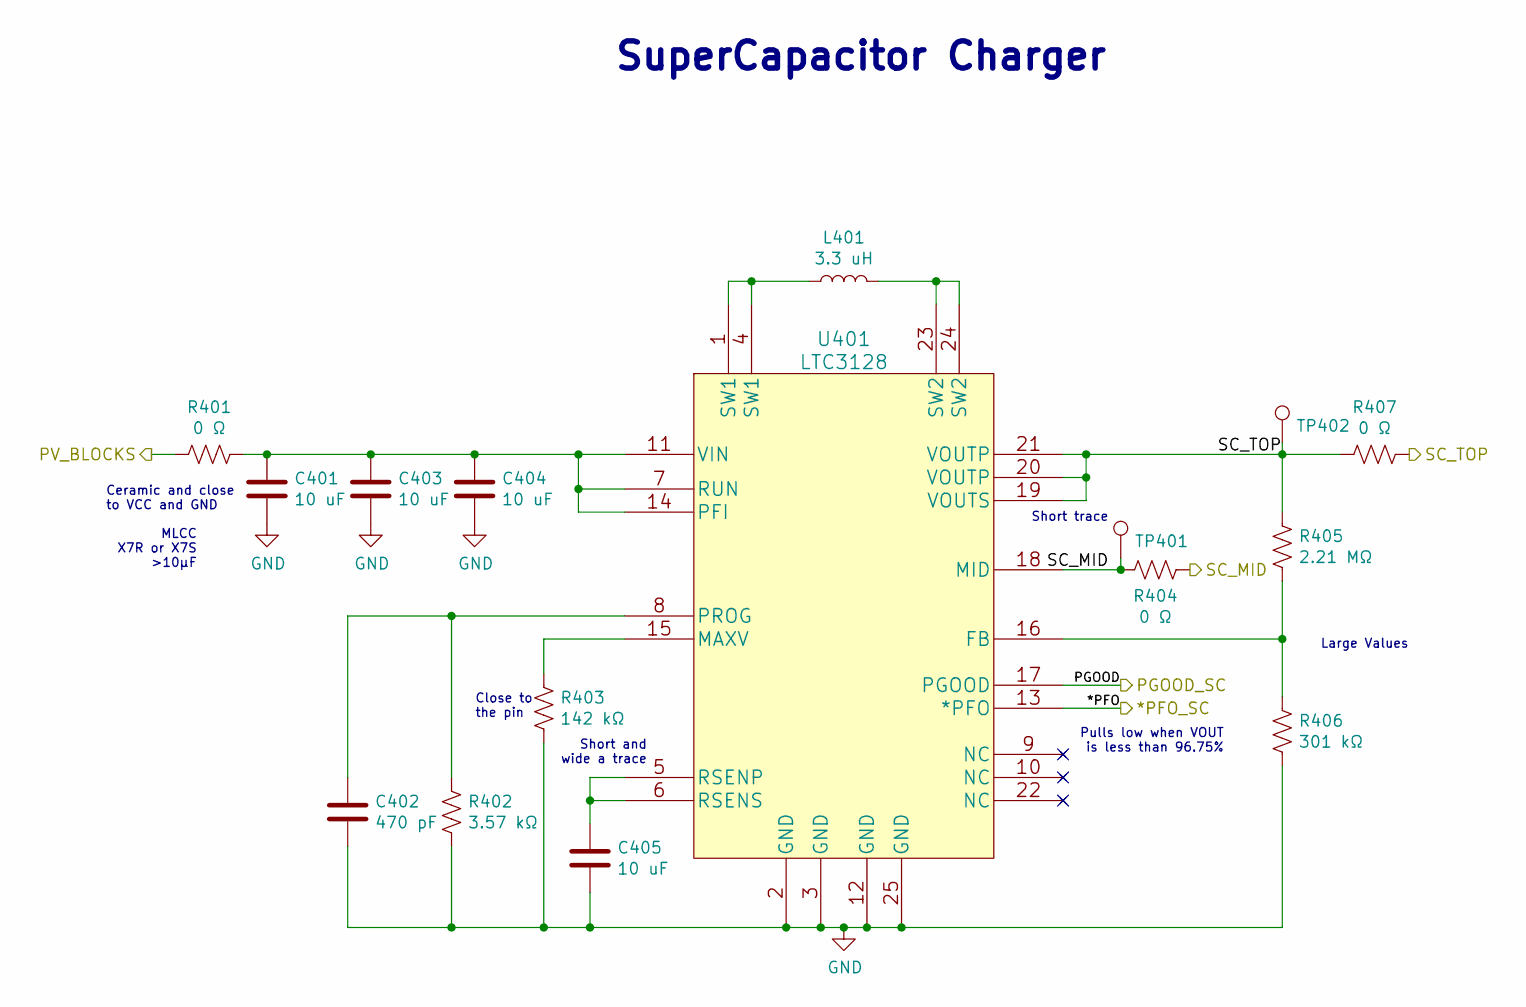
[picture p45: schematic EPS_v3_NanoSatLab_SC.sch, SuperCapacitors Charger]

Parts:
C401, C403, C404, C405: 10 uF; C_0805_2012Metric; LCSC Part C15850
C402: 470 pF; C_0402_1005Metric; LCSC Part C1537
L401: 3.3 uH; L_0805_2012Metric; LCSC BOM 0
R401, R404, R407: 0 Ω; R_0603_1608Metric; LCSC Part C21189
R402: 3.57 kΩ; R_0603_1608Metric; LCSC BOM 0
R403: 142 kΩ; R_0603_1608Metric; LCSC BOM 0
R405: 2.21 MΩ; R_0603_1608Metric; LCSC BOM 0
R406: 301 kΩ; R_0603_1608Metric; LCSC BOM 0
TP401, TP402: TestPoint; TESTPOINT_5013; LCSC BOM 0
U401: LTC3128; LTC3128EFE-PBF; LCSC BOM 0

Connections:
/EPS - MCU/*PFO_SC: U401.13 (*PFO); also elsewhere on the board
/EPS - MCU/PGOOD_SC: U401.17 (PGOOD); also elsewhere on the board
/PV_BLOCKS: R401.2; also elsewhere on the board
/SC_MID: R404.1, R404.2, TP401.1, U401.18 (MID); also elsewhere on the board
/SC_TOP: R405.1, R407.1, R407.2, TP402.1, U401.19 (VOUTS), U401.20 (VOUTP), U401.21 (VOUTP); also elsewhere on the board
GND: C401.2, C402.2, C403.2, C404.2, C405.2, R402.2, R403.2, R406.2, U401.2 (GND), U401.3 (GND), U401.12 (GND), U401.25 (GND); also elsewhere on the board
unnamed: C401.1, C403.1, C404.1, R401.1, U401.7 (RUN), U401.11 (VIN), U401.14 (PFI)
unnamed: C402.1, R402.1, U401.8 (PROG)
unnamed: C405.1, U401.5 (RSENP), U401.6 (RSENS)
unnamed: L401.1, U401.1 (SW1), U401.4 (SW1)
unnamed: L401.2, U401.23 (SW2), U401.24 (SW2)
unnamed: R403.1, U401.15 (MAXV)
unnamed: R405.2, R406.1, U401.16 (FB)

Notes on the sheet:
SuperCapacitor Charger
Ceramic and close to VCC and GND
Short trace
MLCC X7R or X7S >10µF
Close to the pin
Short and wide a trace
Large Values
Pulls low when VOUT is less than 96.75%

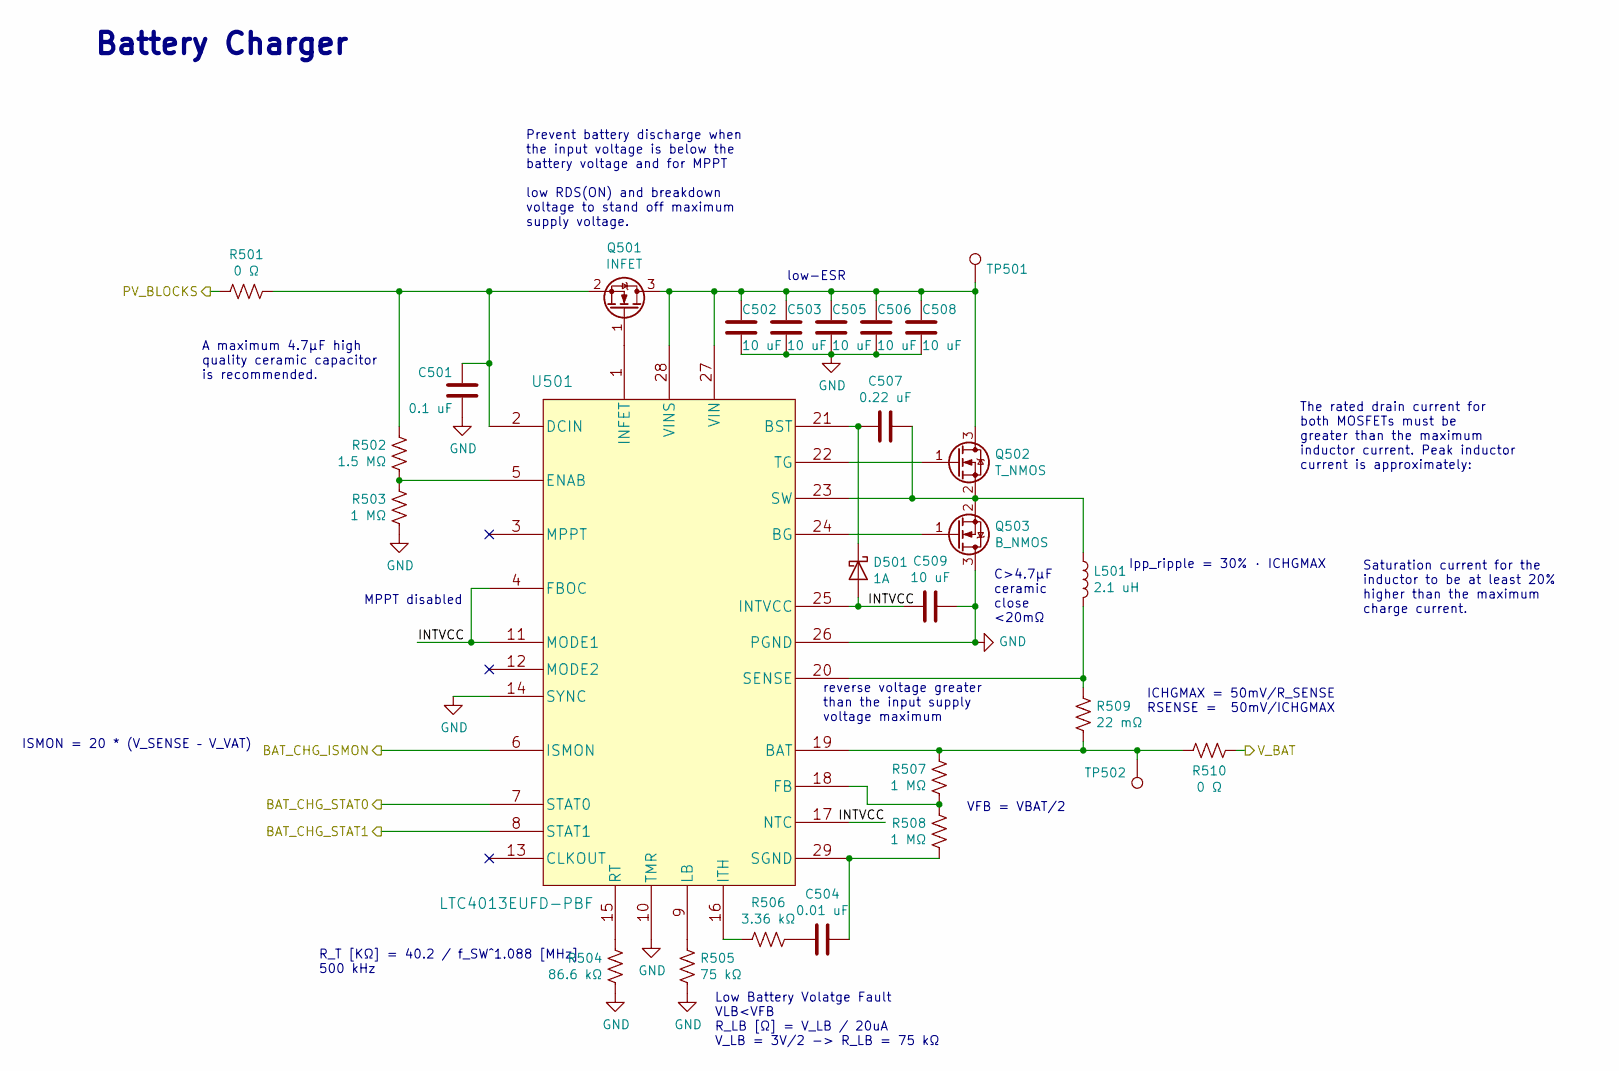
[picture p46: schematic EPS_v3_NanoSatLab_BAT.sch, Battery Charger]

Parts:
C501: 0.1 uF; C_0603_1608Metric; LCSC Part C14663
C502, C503, C505, C506, C508, C509: 10 uF; C_0805_2012Metric; LCSC Part C15850
C504: 0.01 uF; C_0402_1005Metric; LCSC Part C15195
C507: 0.22 uF; C_0603_1608Metric; LCSC Part C21120
D501: 1A; DO-214BA-2; LCSC BOM 0
L501: 2.1 uH; NR10050T2R1N; LCSC BOM 0
Q501: INFET; DMN1019USN-7(TSOT-26-6); LCSC BOM 0
Q502: T_NMOS; DMN1019USN-7(TSOT-26-6); LCSC BOM 0
Q503: B_NMOS; DMN1019USN-7(TSOT-26-6); LCSC BOM 0
R501, R510: 0 Ω; R_0603_1608Metric; LCSC Part C21189
R502: 1.5 MΩ; R_0603_1608Metric; LCSC Part C4172
R503, R507, R508: 1 MΩ; R_0603_1608Metric; LCSC Part C22935
R504: 86.6 kΩ; R_0603_1608Metric; LCSC BOM 0
R505: 75 kΩ; R_0603_1608Metric; LCSC Part C23242
R506: 3.36 kΩ; R_0603_1608Metric; LCSC BOM 0
R509: 22 mΩ; R_0815_2038Metric; LCSC BOM 0
TP501, TP502: TestPoint; TESTPOINT_5013; LCSC BOM 0
U501: LTC4013EUFD-PBF; LCSC BOM 0

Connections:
/EPS - Batteries/BAT_CHG_ISMON: U501.6 (ISMON); also elsewhere on the board
/EPS - Batteries/BAT_CHG_STAT0: U501.7 (STAT0); also elsewhere on the board
/EPS - Batteries/BAT_CHG_STAT1: U501.8 (STAT1); also elsewhere on the board
/EPS - Batteries/INTVCC: C509.2, D501.2 (A), U501.4 (FBOC), U501.11 (MODE1), U501.17 (NTC), U501.25 (INTVCC)
/EPS - Batteries/V_BAT: R510.1; also elsewhere on the board
/PV_BLOCKS: R501.2; also elsewhere on the board
GND: C501.1, C502.2, C503.2, C505.2, C506.2, C508.2, C509.1, Q503.3 (D), R503.2, R504.2, R505.2, U501.10 (TMR), U501.14 (SYNC), U501.26 (PGND); also elsewhere on the board
unnamed: C501.2, Q501.2 (S), R501.1, R502.1, U501.2 (DCIN)
unnamed: C502.1, C503.1, C505.1, C506.1, C508.1, Q501.3 (D), Q502.3 (D), TP501.1, U501.27 (VIN), U501.28 (VINS)
unnamed: C504.1, R508.2, U501.29 (SGND)
unnamed: C504.2, R506.1
unnamed: C507.1, L501.1, Q502.2 (S), Q503.2 (S), U501.23 (SW)
unnamed: C507.2, D501.1 (K), U501.21 (BST)
unnamed: L501.2, R509.1, U501.20 (SENSE)
unnamed: Q501.1 (G), U501.1 (INFET)
unnamed: Q502.1 (G), U501.22 (TG)
unnamed: Q503.1 (G), U501.24 (BG)
unnamed: R502.2, R503.1, U501.5 (ENAB)
unnamed: R504.1, U501.15 (RT)
unnamed: R505.1, U501.9 (LB)
unnamed: R506.2, U501.16 (ITH)
unnamed: R507.1, R509.2, R510.2, TP502.1, U501.19 (BAT)
unnamed: R507.2, R508.1, U501.18 (FB)

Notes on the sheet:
Battery Charger
low-ESR
Low Battery Volatge Fault VLB<VFB R_LB [Ω] = V_LB / 20uA V_LB = 3V/2 -> R_LB = 75 kΩ
ISMON = 20 * (V_SENSE – V_VAT)
R_T [KΩ] = 40.2 / f_SW^1.088 [MHz] 500 kHz
Prevent battery discharge when the input voltage is below the battery voltage and for MPPT low RDS(ON) and breakdown voltage to stand off maximum supply voltage.
ICHGMAX = 50mV/R_SENSE RSENSE = 50mV/ICHGMAX
Ipp_ripple = 30% · ICHGMAX
Saturation current for the inductor to be at least 20% higher than the maximum charge current.
The rated drain current for both MOSFETs must be greater than the maximum inductor current. Peak inductor current is approximately:
A maximum 4.7μF high quality ceramic capacitor is recommended.
reverse voltage greater than the input supply voltage maximum
MPPT disabled
C>4.7μF ceramic close <20mΩ
VFB = VBAT/2

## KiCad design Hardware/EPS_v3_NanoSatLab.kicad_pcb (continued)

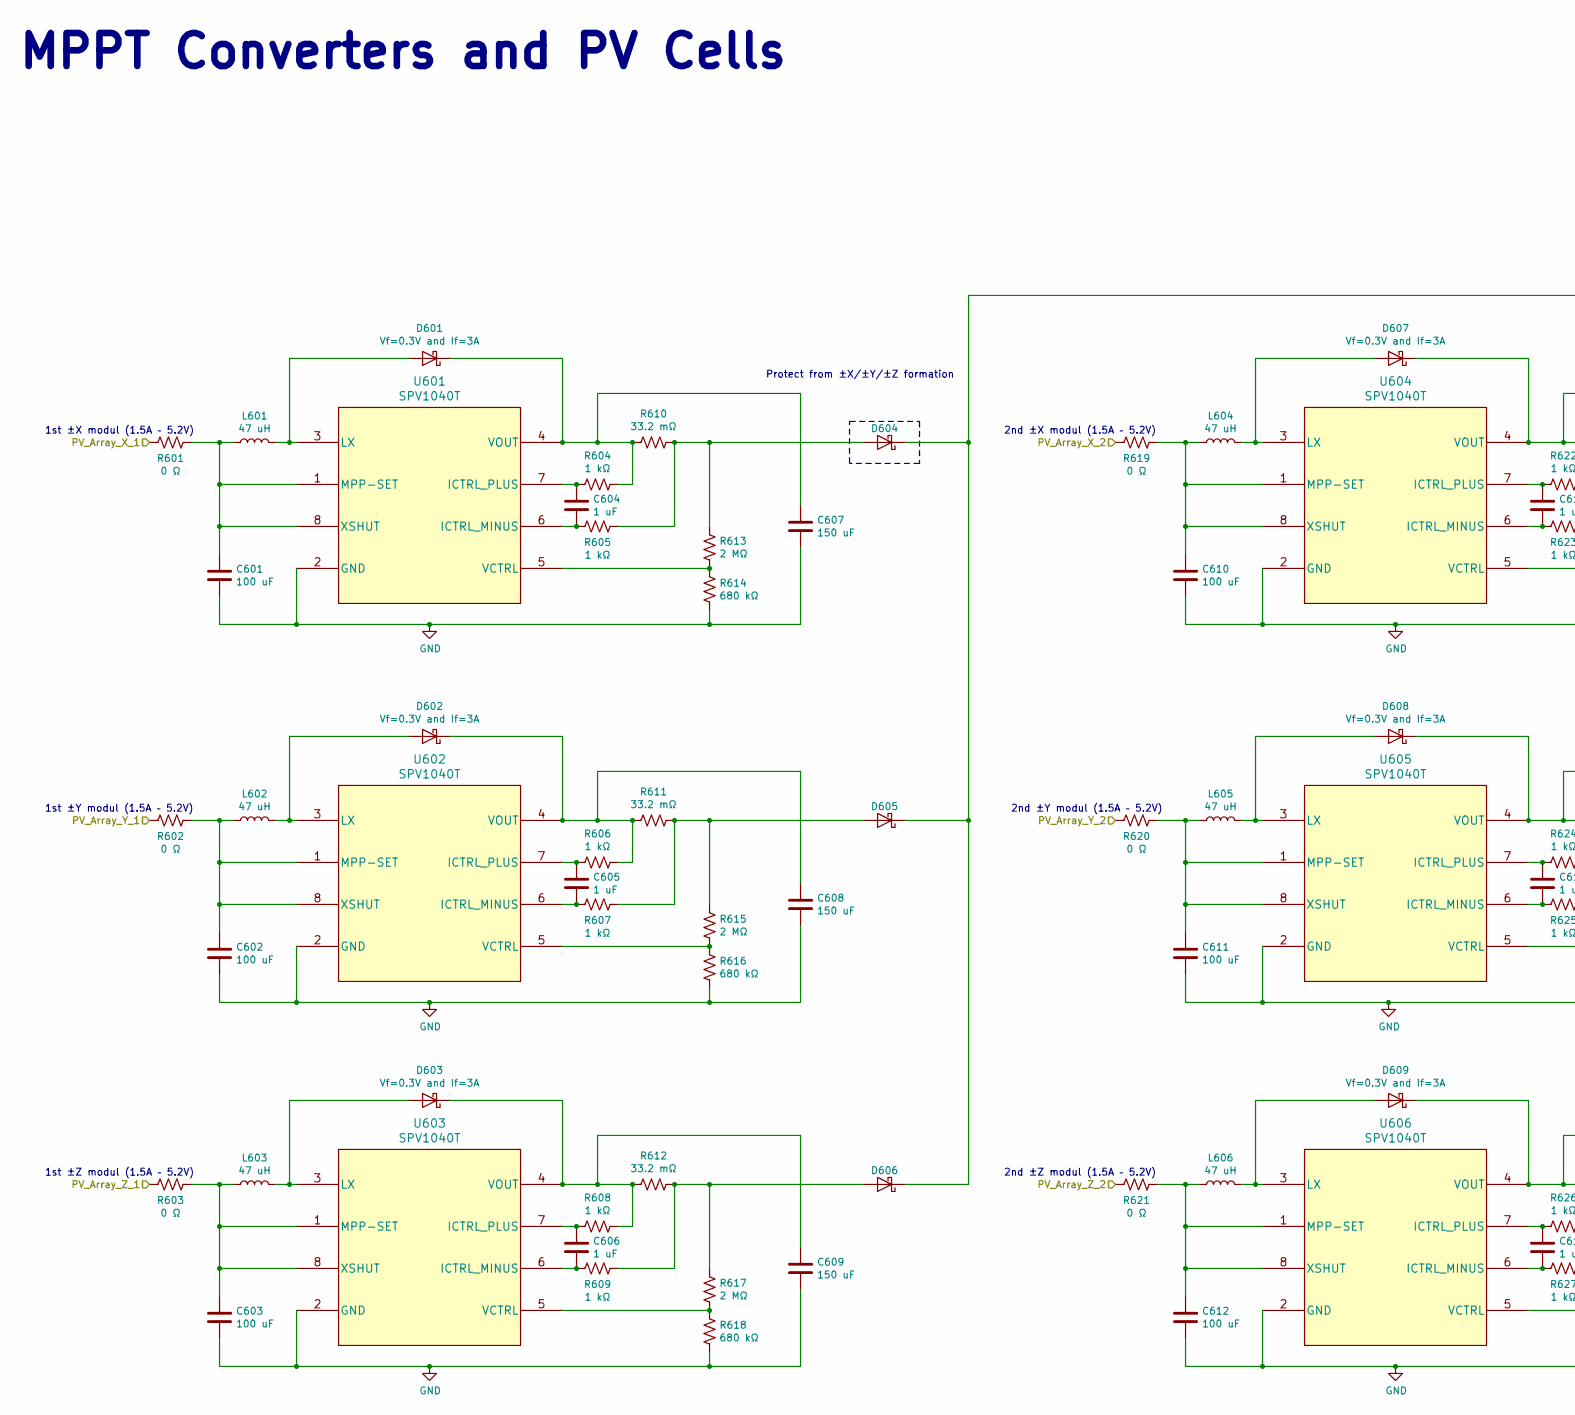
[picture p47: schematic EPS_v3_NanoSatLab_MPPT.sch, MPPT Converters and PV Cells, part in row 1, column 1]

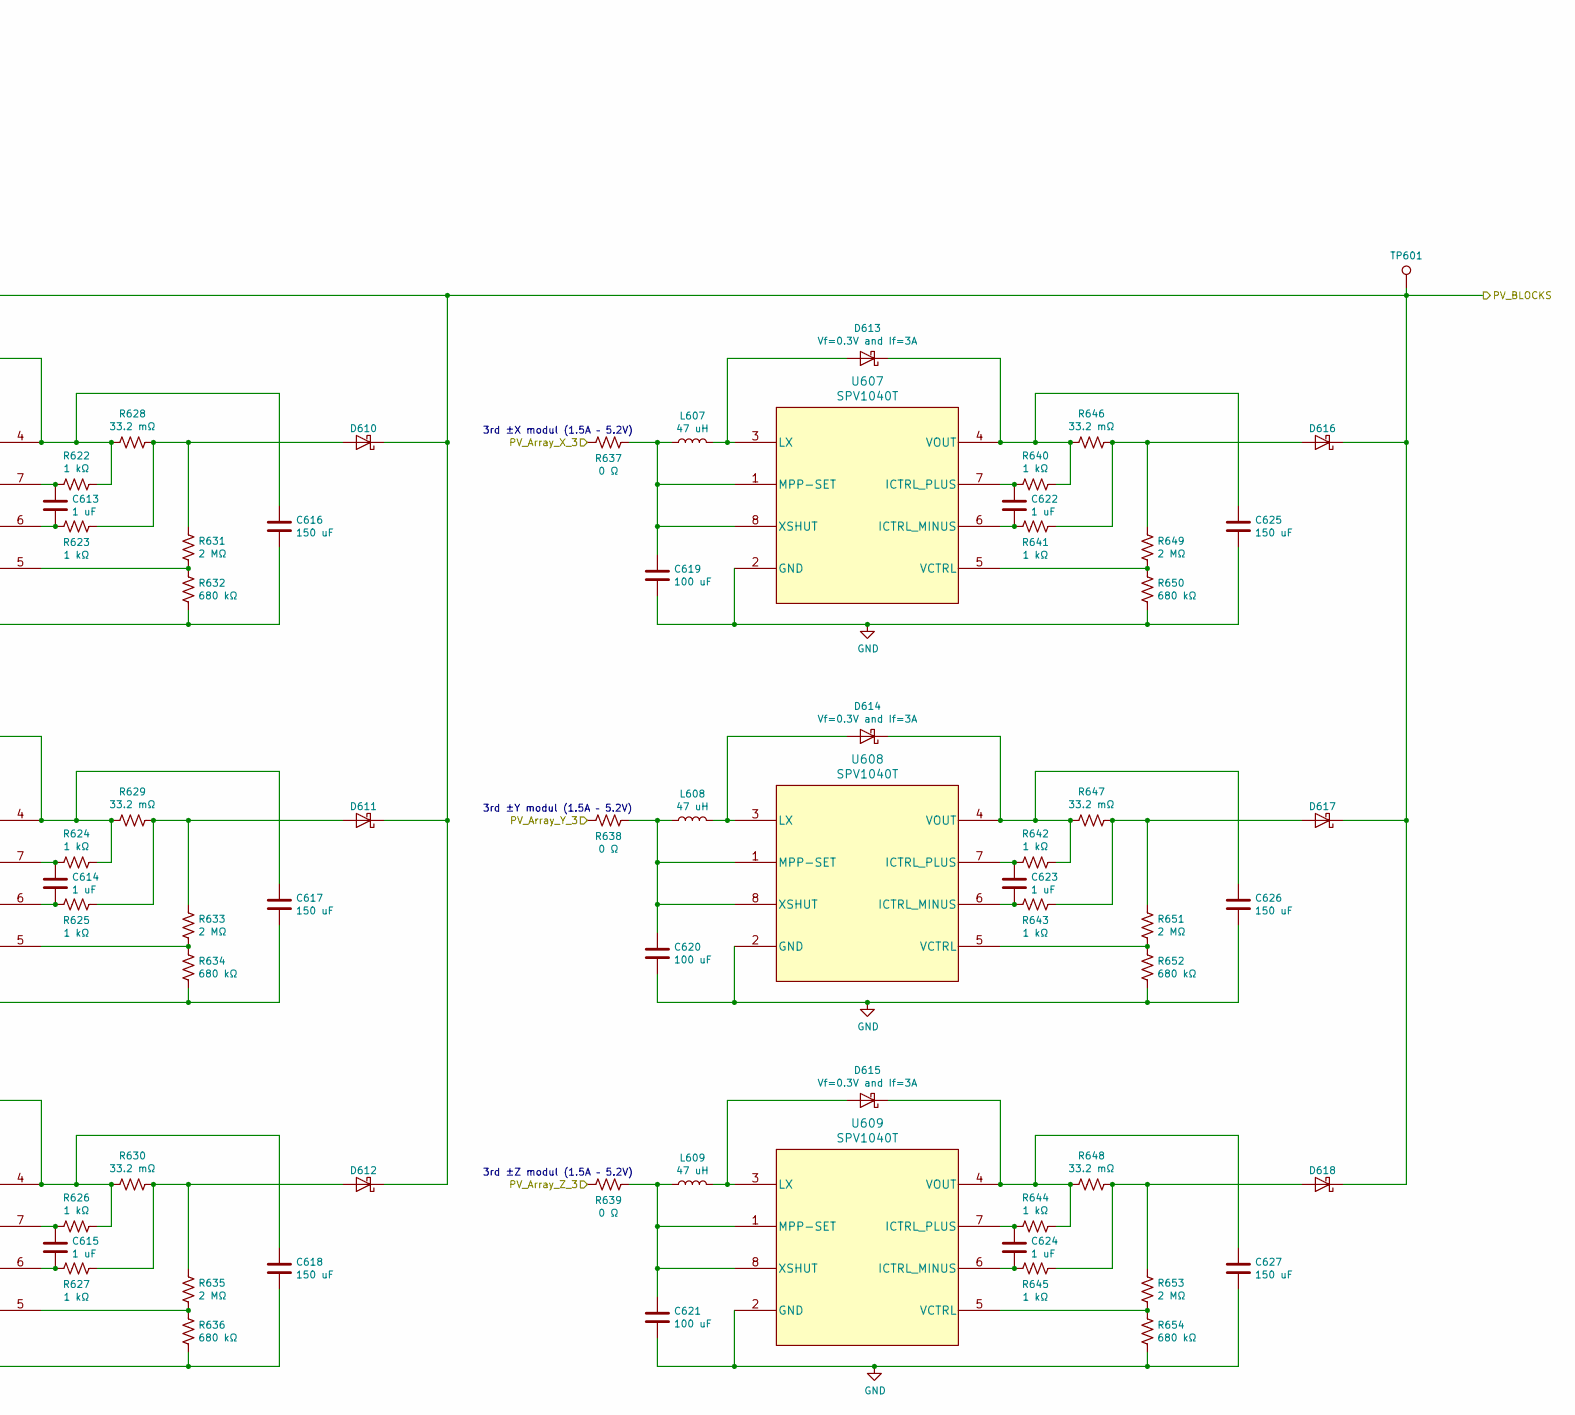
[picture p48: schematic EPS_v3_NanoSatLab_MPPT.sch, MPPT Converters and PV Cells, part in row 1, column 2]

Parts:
C601, C602, C603, C610, C611, C612, C619, C620, C621: 100 uF; C_1210_3225Metric; LCSC BOM 0
C604, C605, C606, C613, C614, C615, C622, C623, C624: 1 uF; C_0402_1005Metric; LCSC Part C52923
C607, C608, C609, C616, C617, C618, C625, C626, C627: 150 uF; C_1210_3225Metric; LCSC BOM 0
D601, D602, D603, D604, D605, D606, D607, D608, D609, D610, D611, D612, D613, D614, D615, D616, D617, D618: Vf=0.3V and If=3A; DO-214AB-2; LCSC BOM 0
L601, L602, L603, L604, L605, L606, L607, L608, L609: 47 uH; NRS5020T4R7MMGJ; LCSC BOM 0
R601, R602, R603, R619, R620, R621, R637, R638, R639: 0 Ω; R_0603_1608Metric; LCSC Part C21189
R604, R605, R606, R607, R608, R609, R622, R623, R624, R625, R626, R627, R640, R641, R642, R643, R644, R645: 1 kΩ; R_0402_1005Metric; LCSC Part C11702
R610, R611, R612, R628, R629, R630, R646, R647, R648: 33.2 mΩ; R_0805_2012Metric; LCSC BOM 0
R613, R615, R617, R631, R633, R635, R649, R651, R653: 2 MΩ; R_0603_1608Metric; LCSC Part C22976
R614, R616, R618, R632, R634, R636, R650, R652, R654: 680 kΩ; R_0402_1005Metric; LCSC Part C4131
TP601: TestPoint; TESTPOINT_5013; LCSC BOM 0
U601, U602, U603, U604, U605, U606, U607, U608, U609: SPV1040T; LCSC BOM 0

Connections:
/EPS – MPPT/PV_Array_X_1: R601.2; also elsewhere on the board
/EPS – MPPT/PV_Array_X_2: R619.2; also elsewhere on the board
/EPS – MPPT/PV_Array_X_3: R637.2; also elsewhere on the board
/EPS – MPPT/PV_Array_Y_1: R602.2; also elsewhere on the board
/EPS – MPPT/PV_Array_Y_2: R620.2; also elsewhere on the board
/EPS – MPPT/PV_Array_Y_3: R638.2; also elsewhere on the board
/EPS – MPPT/PV_Array_Z_1: R603.2; also elsewhere on the board
/EPS – MPPT/PV_Array_Z_2: R621.2; also elsewhere on the board
/EPS – MPPT/PV_Array_Z_3: R639.2; also elsewhere on the board
/PV_BLOCKS: D604.1 (K), D605.1 (K), D606.1 (K), D610.1 (K), D611.1 (K), D612.1 (K), D616.1 (K), D617.1 (K), D618.1 (K), TP601.1; also elsewhere on the board
GND: C601.2, C602.2, C603.2, C607.2, C608.2, C609.2, C610.2, C611.2, C612.2, C616.2, C617.2, C618.2, C619.2, C620.2, C621.2, C625.2, C626.2, C627.2, R614.2, R616.2, R618.2, R632.2, R634.2, R636.2, R650.2, R652.2, R654.2, U601.2 (GND), U602.2 (GND), U603.2 (GND), U604.2 (GND), U605.2 (GND), U606.2 (GND), U607.2 (GND), U608.2 (GND), U609.2 (GND); also elsewhere on the board
unnamed: C601.1, L601.1, R601.1, U601.1 (MPP-SET), U601.8 (XSHUT)
unnamed: C602.1, L602.1, R602.1, U602.1 (MPP-SET), U602.8 (XSHUT)
unnamed: C603.1, L603.1, R603.1, U603.1 (MPP-SET), U603.8 (XSHUT)
unnamed: C604.1, R604.2, U601.7 (ICTRL_PLUS)
unnamed: C604.2, R605.2, U601.6 (ICTRL_MINUS)
unnamed: C605.1, R606.2, U602.7 (ICTRL_PLUS)
unnamed: C605.2, R607.2, U602.6 (ICTRL_MINUS)
unnamed: C606.1, R608.2, U603.7 (ICTRL_PLUS)
unnamed: C606.2, R609.2, U603.6 (ICTRL_MINUS)
unnamed: C607.1, D601.1 (K), R604.1, R610.2, U601.4 (VOUT)
unnamed: C608.1, D602.1 (K), R606.1, R611.2, U602.4 (VOUT)
unnamed: C609.1, D603.1 (K), R608.1, R612.2, U603.4 (VOUT)
unnamed: C610.1, L604.1, R619.1, U604.1 (MPP-SET), U604.8 (XSHUT)
unnamed: C611.1, L605.1, R620.1, U605.1 (MPP-SET), U605.8 (XSHUT)
unnamed: C612.1, L606.1, R621.1, U606.1 (MPP-SET), U606.8 (XSHUT)
unnamed: C613.1, R622.2, U604.7 (ICTRL_PLUS)
unnamed: C613.2, R623.2, U604.6 (ICTRL_MINUS)
unnamed: C614.1, R624.2, U605.7 (ICTRL_PLUS)
unnamed: C614.2, R625.2, U605.6 (ICTRL_MINUS)
unnamed: C615.1, R626.2, U606.7 (ICTRL_PLUS)
unnamed: C615.2, R627.2, U606.6 (ICTRL_MINUS)
unnamed: C616.1, D607.1 (K), R622.1, R628.2, U604.4 (VOUT)
unnamed: C617.1, D608.1 (K), R624.1, R629.2, U605.4 (VOUT)
unnamed: C618.1, D609.1 (K), R626.1, R630.2, U606.4 (VOUT)
unnamed: C619.1, L607.1, R637.1, U607.1 (MPP-SET), U607.8 (XSHUT)
unnamed: C620.1, L608.1, R638.1, U608.1 (MPP-SET), U608.8 (XSHUT)
unnamed: C621.1, L609.1, R639.1, U609.1 (MPP-SET), U609.8 (XSHUT)
unnamed: C622.1, R640.2, U607.7 (ICTRL_PLUS)
unnamed: C622.2, R641.2, U607.6 (ICTRL_MINUS)
unnamed: C623.1, R642.2, U608.7 (ICTRL_PLUS)
unnamed: C623.2, R643.2, U608.6 (ICTRL_MINUS)
unnamed: C624.1, R644.2, U609.7 (ICTRL_PLUS)
unnamed: C624.2, R645.2, U609.6 (ICTRL_MINUS)
unnamed: C625.1, D613.1 (K), R640.1, R646.2, U607.4 (VOUT)
unnamed: C626.1, D614.1 (K), R642.1, R647.2, U608.4 (VOUT)
unnamed: C627.1, D615.1 (K), R644.1, R648.2, U609.4 (VOUT)
unnamed: D601.2 (A), L601.2, U601.3 (LX)
unnamed: D602.2 (A), L602.2, U602.3 (LX)
unnamed: D603.2 (A), L603.2, U603.3 (LX)
unnamed: D604.2 (A), R605.1, R610.1, R613.1
unnamed: D605.2 (A), R607.1, R611.1, R615.1
unnamed: D606.2 (A), R609.1, R612.1, R617.1
unnamed: D607.2 (A), L604.2, U604.3 (LX)
unnamed: D608.2 (A), L605.2, U605.3 (LX)
unnamed: D609.2 (A), L606.2, U606.3 (LX)
unnamed: D610.2 (A), R623.1, R628.1, R631.1
unnamed: D611.2 (A), R625.1, R629.1, R633.1
unnamed: D612.2 (A), R627.1, R630.1, R635.1
unnamed: D613.2 (A), L607.2, U607.3 (LX)
unnamed: D614.2 (A), L608.2, U608.3 (LX)
unnamed: D615.2 (A), L609.2, U609.3 (LX)
unnamed: D616.2 (A), R641.1, R646.1, R649.1
unnamed: D617.2 (A), R643.1, R647.1, R651.1
unnamed: D618.2 (A), R645.1, R648.1, R653.1
unnamed: R613.2, R614.1, U601.5 (VCTRL)
unnamed: R615.2, R616.1, U602.5 (VCTRL)
unnamed: R617.2, R618.1, U603.5 (VCTRL)
unnamed: R631.2, R632.1, U604.5 (VCTRL)
unnamed: R633.2, R634.1, U605.5 (VCTRL)
unnamed: R635.2, R636.1, U606.5 (VCTRL)
unnamed: R649.2, R650.1, U607.5 (VCTRL)
unnamed: R651.2, R652.1, U608.5 (VCTRL)
unnamed: R653.2, R654.1, U609.5 (VCTRL)

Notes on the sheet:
MPPT Converters and PV Cells
Protect from ±X/±Y/±Z formation
1st ±X modul (1.5A – 5.2V)
1st ±Z modul (1.5A – 5.2V)
2nd ±X modul (1.5A – 5.2V)
2nd ±Y modul (1.5A – 5.2V)
2nd ±Z modul (1.5A – 5.2V)
3rd ±X modul (1.5A – 5.2V)
3rd ±Y modul (1.5A – 5.2V)
3rd ±Z modul (1.5A – 5.2V)
1st ±Y modul (1.5A – 5.2V)

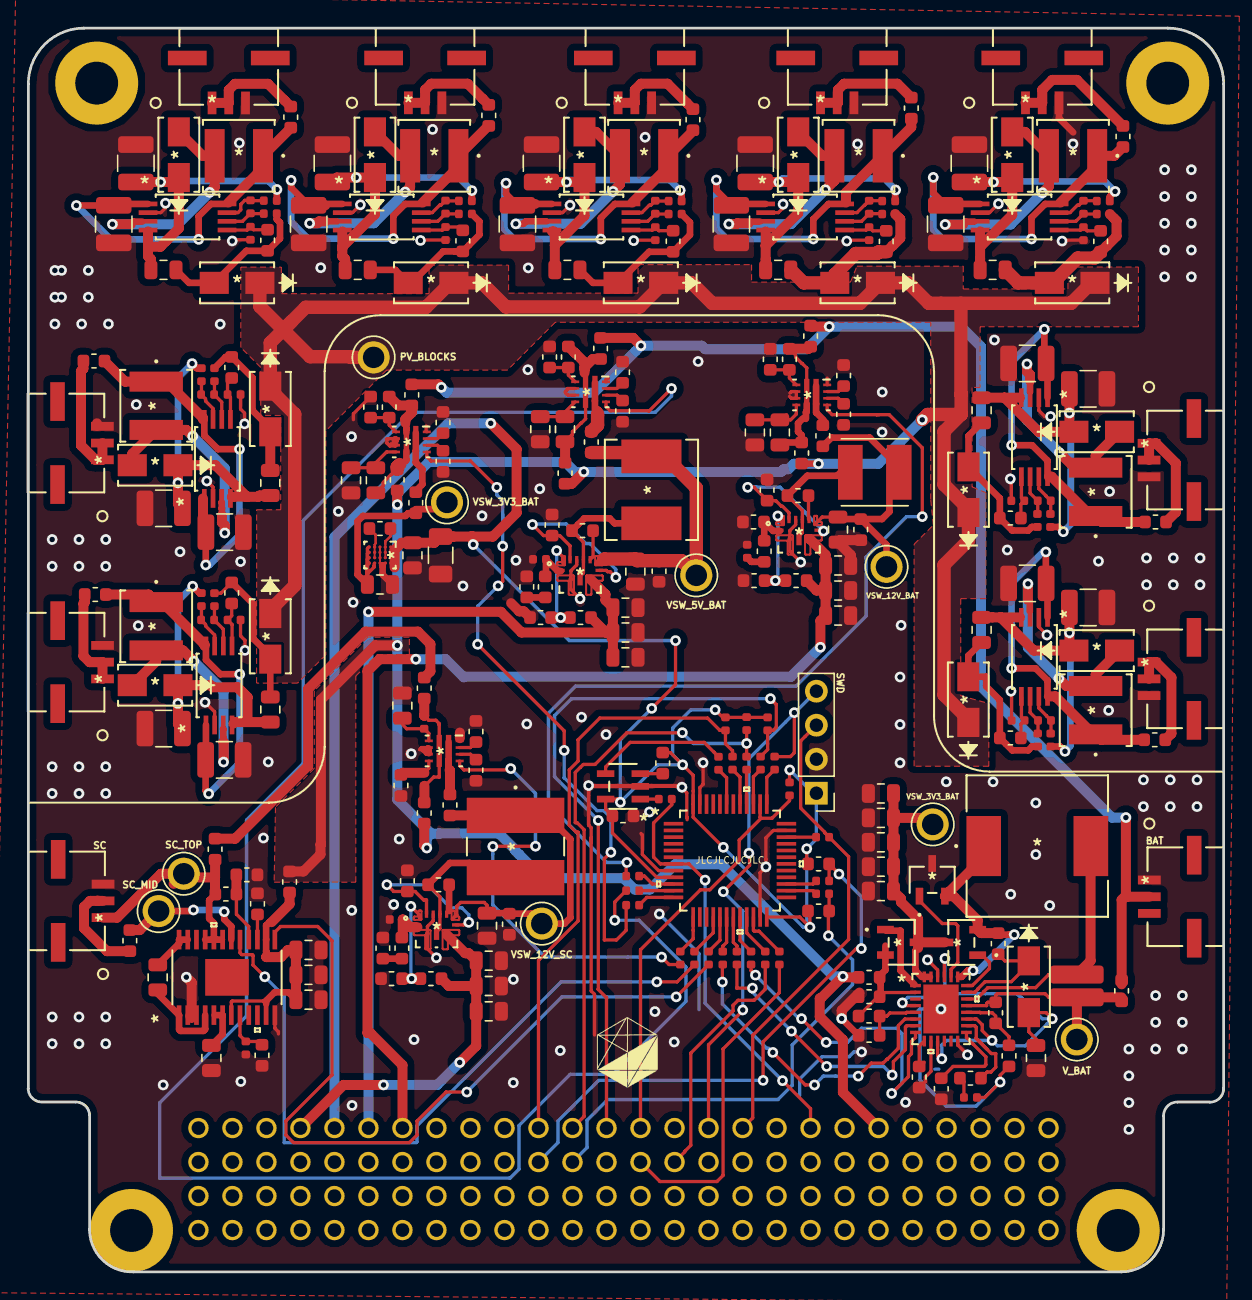
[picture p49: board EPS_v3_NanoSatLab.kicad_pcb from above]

Board: 2 copper layers, 89.3 x 92.9 mm, 295 parts (0 on the bottom side), 198 nets.

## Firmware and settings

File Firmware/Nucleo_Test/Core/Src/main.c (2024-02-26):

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
/* Includes ------------------------------------------------------------------*/
#include "main.h"
#include <string.h>
#include <stdio.h>

ADC_HandleTypeDef hadc1;

TIM_HandleTypeDef htim1;

UART_HandleTypeDef huart2;

/* USER CODE BEGIN PV */

uint16_t tDelay = 500;

/* USER CODE END PV */

void SystemClock_Config(void);
static void MX_GPIO_Init(void);
static void MX_USART2_UART_Init(void);
static void MX_TIM1_Init(void);
static void MX_ADC1_Init(void);
/**
  * @brief  The application entry point.
  * @retval int
  */
int main(void)
{
  /* USER CODE BEGIN 1 */
  uint16_t raw;
  char msg[10];
  /* USER CODE END 1 */

  /* MCU Configuration--------------------------------------------------------*/

  /* Reset of all peripherals, Initializes the Flash interface and the Systick. */
  HAL_Init();

  /* Configure the system clock */
  SystemClock_Config();

  /* Initialize all configured peripherals */
  MX_GPIO_Init();
  MX_USART2_UART_Init();
  MX_TIM1_Init();
  MX_ADC1_Init();
  /* Infinite loop */
  /* USER CODE BEGIN WHILE */
  while (1)
  {
	// Get ADC Values
	HAL_ADC_Start(&hadc1);
	HAL_ADC_PollForConversion(&hadc1, HAL_MAX_DELAY);
	raw = HAL_ADC_GetValue(&hadc1);

	// Convert to string and print
	sprintf(msg, "%hu\r\n", raw);
	HAL_UART_Transmit(&huart2, (uint8_t*)msg, strlen(msg), HAL_MAX_DELAY);

	HAL_Delay(1);

    /* USER CODE END WHILE */

    /* USER CODE BEGIN 3 */
	HAL_GPIO_TogglePin(GPIOA, GPIO_PIN_5);
	HAL_Delay(tDelay);
  }
  /* USER CODE END 3 */
}

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


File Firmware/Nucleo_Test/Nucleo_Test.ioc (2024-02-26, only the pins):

Mcu.UserName=STM32F401RETx
PC13-ANTI_TAMP.GPIO_Label=B1 [Blue PushButton]
PA14.GPIO_Label=TCK
PC14-OSC32_IN.Signal=RCC_OSC32_IN
PA0-WKUP.Signal=ADCx_IN0
PA13.Signal=SYS_JTMS-SWDIO
PC15-OSC32_OUT.Signal=RCC_OSC32_OUT
PA5.Signal=GPIO_Output
PC13-ANTI_TAMP.Signal=GPXTI13
PA2.Signal=USART2_TX
PA13.GPIO_Label=TMS
PB3.Signal=SYS_JTDO-SWO
PA5.GPIO_Label=LD2 [Green Led]
PA2.GPIO_Label=USART_TX
PA14.Signal=SYS_JTCK-SWCLK
PA3.GPIO_Label=USART_RX
PA3.Signal=USART2_RX
PB3.GPIO_Label=SWO

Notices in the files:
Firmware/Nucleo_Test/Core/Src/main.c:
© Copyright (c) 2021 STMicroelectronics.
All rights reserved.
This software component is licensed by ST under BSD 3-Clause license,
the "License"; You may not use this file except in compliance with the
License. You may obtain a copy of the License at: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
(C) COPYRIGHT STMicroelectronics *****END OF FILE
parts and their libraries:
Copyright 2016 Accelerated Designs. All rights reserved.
